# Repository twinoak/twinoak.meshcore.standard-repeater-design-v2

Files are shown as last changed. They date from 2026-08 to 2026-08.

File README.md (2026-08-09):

# TwinOak Standard Repeater Design v2

## General design concept and project goals
The thought behind this project came to life after quite a few failures in OTA firmware updates. There was need for a better, and more stable, way of doing the firmware updates. 
Besides the devices being bricked from the OTA process, repeaters can also sit quite a long distance away, so it would also be desireable to have something that could update remotely, from the comfort of a desk. 
One could consider using LoRa for sending the updates to the repeaters, but since the network is already congested enough, it seems like a bad idea to pile even more load on that band, even assuming that it somehow would be possible to get a stable link to all the repeater sites.

It was decided to go for a design which incorporated an LTE-M module for managinge the node. This gives almost 100% coverage(in Denmark at least!) and high bandwidth for firmware transfers. 
The structure looked something like this:
```mermaid
flowchart LR
    subgraph Mesh plane
    A@{ shape: cloud, label: "Mesh network" } <--> B[LoRa module]
    end
    B[LoRa module] <-.-> C[LTE-M module]
    subgraph Management plane
    C <--> D@{ shape: cloud, label: "Internet" }
    end
```

Besides the problematic management of remote nodes, there is also a few other features to address with this new repeater design. This meant that the primary goals for the project ended up being:
1. <b>Remote management</b>. Being able to do management remotely based on existing LTE infrastructure. Only management, no data via LTE.
2. <b>Superior noise "rejection"</b> with radio in RF shielding and using proper cables and isolation to give the LoRa the best possible noise floor. Previous experience with SenseCAP Solar P1 nodes, even though they are very nice nodes, proved that they are just plastic enclosures with no RF protection. Put them next to a cell tower and you are in trouble! A bit ironic that the biggest nemesis regarding noise in MeshCore repeaters is LTE, when this going to use LTE as the transport for the management plane!
3. <b>Integrated cavity filter</b>. There has been multiple issues with noise in all many locations. There is always a cell tower(or some DAB/DVT/whatever tower) sitting just next to great locations. The Solar P1 only offers the option to add a small SAW filter, but one goal of this project is that it should to be easy to add a good cavity filter. Even maybe be the default.
4. <b>Modularity</b>. Things change fast; firmware, features and other software changes fast! But hardware also changes. With the Solar P1 one would have to replace the entire unit if a new and better radio became available. This project should solve this by enabling changing JUST the radio or JUST the solarpanel or JUST the batteries. Not doing a complete "forklift upgrade" everytime is a must.

## Hardware design principle
The hardware is split into 3 parts:
1. The LoRa part
2. The power part
3. The management part

To make these function together in a modular way each part has been split into multiple "levels" with increasing amount of specialization the higher the level. This has been illustrated here:
```mermaid
block
  columns 7
  block:stuff:2
    columns 1
    A1["LoRa modul"] 
    space
    A2["LoRa adapter board"] 
    space
    A3["Platform board"]
    space
    space
  end
  space
  block:stuff2:2
    columns 1
    space
    space
    space
    space
    B3["Platform mgmt"]
    space
    B4["Power"]
  end
  space
  block:stuff3:2
    columns 1
    C1["LTE modul"] 
    space
    C2["LTE adapter board"]
    space
    C3["Platform board"]
    space
    space
  end

  %% Arrows vertically
  A1 <--> A2
  A2 <--> A3

  B4 --> B3

  C1 <--> C2
  C2 <--> C3

  %% Arrows horisontally
  A3 <--> B3
  B3 <--> C3
```
From the bottom up:
- <b>Power</b> is just that: Simple DC power source from either solarpanel, grid connection or battery.
- <b>Platform</b> and <b>Platform management</b> is introducing management of the power from the power source and handling signaling between the two platform boards. Each platformboard is just supplying simple power to the upper levels and generic IO between the levels.
- <b>Adapters</b> change the generic IO and power from the platform to the specific needs of the module above it. That could be board specific power management, levelshifting of IO signals and routing to the proper pins for the given module above.
- <b>Radio modules</b> is the actual off-the-shelf radio modules, such as a Heltec LoRa module like the T096 or similar.

Each of the 3 parts should be kept as RF isolated as possible as the two radio modules will likely interfer with each other. So the parts also indicate an "physical seperation" with RF shielding. To make this as good as possible the entire repeater should be house inside a RF shielded enclosure and both the LoRa part and the management part should be kept in seperate RF shielded enclosures. Great care should be taken at the interfaces between each part, such that RF noise don't traverse the bounderies between each part.

### Pinouts and inter-board wiring

Every pin of the D-subs, the A↔B ribbon, the platform boards and all adapter mappings is documented in
[`hardware/pcb/INTERCONNECT.md`](hardware/pcb/INTERCONNECT.md) — including the I2C bus plan (LoRa is master,
INA3221 @0x42, RV-3028 @0x52), the LoRa↔Walter UART link, the remote power-kill behaviour and JLCPCB part
references. Update that file first whenever the wiring changes.

## Bill-of-materials and links to sources

| Component | Brand | Model | Source | Price |
|---|---|---|---|---:|
| <u>*External components*</u> |
| Antenna, LoRa | Vinnant | CC868/8-PEL 10dBi | [Hoeg teknik](https://hoegteknik.dk/shop/da/dv-nodermeshtastic/483-8dbd-58-antenne-for-868-mhz.html) | 599 DKK |
| Antenna, LTE-M | SR passives| IP67, N-Male, 5dBi | [TME](https://www.tme.eu/dk/en/details/5g-ant-rs02w-n/gsm-antennas/sr-passives/) | 73 DKK |
| Cable | Bevotop | LMR240, N Male to N Male, 80cm | [Aliexpress](https://www.aliexpress.com/item/1005002640557645.html) | ~70 DKK |
| Pipe | | 1" pipe, 200cm | [Webshop](https://shop.erik-larsen.dk/products/pipe-galv?variant=39625182412883) | 150 DKK |
| Brackets | | Pipeclamps, set of 2, max 60mm | [Amazon](https://www.amazon.de/-/da/Premium-mastklemme-dobbeltklemme-galvaniseret-dobbelt/dp/B010UL5B66) | ~67 DKK |
| Enclosure | | Diecast alu box, IP67 | [Aliexpress](https://www.aliexpress.com/item/1005007492347455.html) |  ~185 DKK |
| Solar panel | Cellevia | 10W Solar Panel | [TME](https://www.tme.eu/dk/en/details/cl-sm10p/photovoltaic-modules/cellevia-power/) | 76 DKK |
| Vent valve | | M16 watertight alu vent valve | [Aliexpress](https://www.aliexpress.com/item/1005012242062756.html) | ~20 DKK |
| Bracket | | For solar panel | TBD | |
| Bracket | | For enclosure | TBD | |
| <u>*Internal components*</u> |
| Backplates | Custom | Set of 2pce, 1,5mm lasercut alu | (Fusion link? DXF?) | 280 DKK |
| RF boxes | Gainta | G103-IP67, 64x98x34mm, alu, 2pce  | [TME](https://www.tme.eu/dk/en/details/g103-ip67/multipurpose-enclosures/gainta/) | 108 DKK |
| Cavity filter | Sysmocom | 7Mhz Cavity filter(Link to test?) | [Sysmocom](https://shop.sysmocom.de/868-863..870-MHz-cavity-filter-ISM-LoRa-SigFox-Helium/cf866.5-kt30)  |  ~400 DKK |
| Battery | Meshnology | 10.000mA LiPo battery | [Meshnology](https://meshnology.com/collections/frontpage/products/3-7v-10000mah-lipo-battery-with-usb-charger-protection-for-arduino-esp32-drone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) | ~150 DKK |
| Cable | | U.FL -> SMA pigtail, 10cm | [Aliexpress](https://www.aliexpress.com/item/1005009937311685.html) | ~10 DKK |
| Cable | | N-female -> SMA pigtail, 10cm | [Aliexpress](https://www.aliexpress.com/item/1005008984322302.html) | ~10 DKK |
| Cable | | N-female -> SMA pigtail, 20cm | [Aliexpress](https://www.aliexpress.com/item/1005008984322302.html) | ~10 DKK |
| Cable | | SMA -> SMA pigtail, 10cm | [Aliexpress](https://www.aliexpress.com/item/1005006890065800.html) | ~10 DKK |
| <u>*Radio modules*</u> |
| LoRa module | Heltec | Heltec V3, ESP32 based | [Heltec](https://heltec.org/project/wifi-lora-32-v3/) |  ~120 DKK |
| *...or...* |
| LoRa module | Heltec | Heltec T096, nRF52 based | [Heltec](https://heltec.org/project/t096/) |  ~230 DKK |
| LTE module | Quickspot  | Walter LTE MCU, ESP32 based | [TinyTronics](https://www.tinytronics.nl/nl/development-boards/microcontroller-boards/met-telecommunicatie/walter-esp32-s3-iot-development-board-cat-m-nb-iot-en-gnss-gm02sp) | ~510 DKK |
| <u>*Custom PCBs*</u> |
| Platform board | | TBD | | |
| Heltec V3 adapter | | TBD | | |
| *...or...* |
| Heltec T096 adapter  | | TBD | | |
| LoRa connector board | | TBD | | |
| LTE connector board  | | TBD | | |
| <u>*Electrical components*</u> |
| D-sub connector | Amphenol | FCE17-E09SM-250, 9-pin, filter, x2| [Mouser](https://eu.mouser.com/en/ProductDetail/Amphenol-Commercial-Products/FCE17-E09SM-250) |  ~175 DKK |
| D-sub connector | Amphenol | L717DFE09PT, 9-pin, male PCB, x2  | [Mouser](https://eu.mouser.com/en/ProductDetail/Amphenol-Commercial-Products/L717DFE09PT) |  ~100 DKK |
| Capacitor | Panasonic  | 16SEPG470M, 470µF PolyAlu, x1 | [TME](https://www.tme.eu/dk/en/details/16sepg470m/tht-polymer-capacitors/panasonic/) | ~10 DKK |
| Capacitor | AISHI | EWH1CM101E11OT, 100µF, x2 | [TME](https://www.tme.eu/dk/en/details/ce-100_16pht-y/tht-electrolytic-capacitors/aishi/ewh1cm101e11ot/) | ~1 DKK |
| Capacitor | SR passives| CCT-10N/100V-S, 10nF Ceramic, x2  | [TME](https://www.tme.eu/dk/en/details/cct-10n_100v-s/mlcc-tht-capacitors/sr-passives/ct40805b103k101f1r/) |  ~1 DKK | | |
| Connector | | Pin headers for radio modules? | TBD | |
| Connector | | Low profile headers for adapters? | TBD | |

Total: ~3.250DKK + TBD + solder/heatshrink/screws/wires/etc + shipping/customs/fees/etc

## LTE-M providers

### Lebara
Lebara SIM card, their cheapest plan, has been tested and it worked fine with the Walter MCU and could get contact with the internet without issues.

### NexCon
The LTE provider nexcon.io has been tested. They have a 25MB/month plan that is VERY cheap, like 1eur/month per SIM card including a management website that is VERY nice! Can highly recommend them, however they might only serve commercial customers, so check that first.

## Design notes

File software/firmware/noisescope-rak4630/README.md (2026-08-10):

# NoiseScope — SX1262 spectrum/noise scanner for the RAK4630 adapter

Diagnostic firmware for the TwinOak standard-repeater LoRa module. When a site
has noise problems, flash this **in place of MeshCore**, let it stream spectrum
sweeps, RSSI histograms and burst statistics over the Walter management UART,
then flash MeshCore back. The measurement happens through the repeater's real
RX chain — antenna, coax, cavity filter, matching network, the SX1262 itself —
so unlike an external tinySA measurement it shows exactly what the radio sees.

Never transmits. RX only.

## What it measures

* **Monitor (default on boot):** continuous ~1 kHz instantaneous-RSSI sampling
  of the home channel (869.618 MHz, 62.5 kHz, SF8 by default) through the LoRa
  channel filter. Reports avg/max/min and a burst duty-cycle number every 10 s —
  this is MeshCore's "noise floor" number, but with the transients that
  MeshCore's averaging deliberately filters out.
* **Sweep:** stepped-RSSI spectrum scan (default 863–870 MHz in 25 kHz steps),
  avg + max-hold per point. The SX1262 tunes 150–960 MHz, so you can also point
  it at a suspected blocker (GSM/LTE downlink) — through the cavity filter,
  which is the honest view of what reaches the radio.
* **Hist:** Semtech's spectral-scan engine (official RAM patch, the same
  mechanism SX1261-equipped LoRaWAN gateways use). Per frequency: a histogram
  of 2048 RSSI samples taken 8.2 µs apart, 33 bins × 4 dB from −11 down to
  −139 dBm. Shows floor, burst level and duty cycle in one line — the tool for
  "idles at −115 but jumps to −100" mysteries.
* **Dwell:** park on one frequency and stream windowed statistics — burst
  periodicity and duty cycle over time.
* **CAD:** LoRa preamble-detection ratio, to tell "another LoRa network" apart
  from broadband/other interference.

See `PROTOCOL.md` for the exact NDJSON formats and the command set;
`tools/waterfall_plot.py` renders live or logged output as a waterfall.

## Relationship to MeshCore

Built on the **same pinned Adafruit nRF52 core fork and the same pinned
RadioLib commit** as MeshCore, with the same radio bring-up (DIO2 RF switch,
DIO3 TCXO 1.8 V, 140 mA current limit, RX boosted gain on), so RSSI readings
are comparable with what the repeater experiences in service.
`variants/rak4631/` and `boards/rak4631.json` are vendored from MeshCore
(Arduino LLC / Adafruit LGPL headers preserved).

MeshCore's on-flash config (identity keys, prefs in InternalFS) is **not
touched**: this firmware never writes flash, so a scanner→MeshCore round trip
preserves the repeater's identity. When flashing over SWD, use **sector/range
erase of the application area only — never chip erase** — or the bootloader,
SoftDevice and MeshCore's config filesystem go with it.

## Building

```
pio run
```

Artifacts in `.pio/build/rak4630/`:

* `firmware.hex` — for SWD flashing (Walter, J-Link, probe of choice)
* `firmware.zip` — DFU package for `adafruit-nrfutil dfu serial`
* `firmware.elf` — debugging

Offline/registry-blocked networks: every PlatformIO package can be substituted
with a local `symlink://` package (apt `gcc-arm-none-eabi` as
`toolchain-gccarmnoneeabi`, pip `scons`, apt `srecord` as `tool-sreccat`,
sparse-cloned CMSIS 5.7). The pinned framework and RadioLib come straight from
GitHub.

## Flashing workflows

**Remote (Walter, SWD):** flash `firmware.hex` over the SWD lines (D-sub pins
3/4/5), application range only. Same procedure back to MeshCore. The nRF52
watchdog (8 s) plus the bootloader living in protected flash means a bad day
ends in a reboot loop you can still flash out of — not a brick.

**Field (USB-C on the adapter):** double-tap reset or send `dfu` over any
serial console → UF2 bootloader (drag-and-drop) — or
`adafruit-nrfutil dfu serial -pkg firmware.zip -p COMx -b 115200`.

**Back to MeshCore remotely:** `dfu serial` reboots into the bootloader's
serial-only DFU if you flash over USB-CDC-less transports; over SWD just flash
the MeshCore hex.

## Using it

Connect at 115200 (Walter UART or USB). It boots into monitor mode and starts
reporting on its own — with `auto 10` (default) it also runs a full-band sweep
every 10 minutes. Typical session:

```
time 1754820000        # sync the clock (writes the RV-3028)
info
sweep                  # one full-band pass, ~7 s
hist 869.4 869.8 25    # histogram zoom on the 500 mW ERP subband
dwell 869.618 300      # 5 minutes of burst statistics on-channel
cad                    # is it LoRa?
```

Live waterfall on a laptop:

```
pip install -r tools/requirements.txt
python tools/waterfall_plot.py --port COM7 --metric max
```

Log on the Walter side and plot later:

```
python tools/waterfall_plot.py --file site.ndjson --save site.png
```

## Design notes / safety

* **Watchdog:** 8 s hardware WDT, fed from the main loop. Any hang → reset →
  boots into passive monitor mode.
* **Serial always live:** scans are chunked; command input is drained during
  blocking steps and executed between them. `stop` always works.
* **Spectral-scan patch:** ~2 kB Semtech blob (from `Lora-net/sx1302_hal`,
  shipped with RadioLib), uploaded into SX1262 RAM over SPI at the start of
  each `hist` session, purged by hardware reset at the end. Volatile by design:
  a PWR_KILL cycle, NRST pulse or reboot always returns the radio to stock.
* **Power telemetry:** reports the B-board INA3221 (panel/battery/load) in
  every heartbeat, so a scanning session doubles as a power-budget check.
  Missing peripherals (bench setup) are detected and skipped.
* **RX boosted gain** matches MeshCore's default (`boost off` to compare).
* The nRF52840's own radio is untouched (no BLE, no SoftDevice enabled).

## Interpreting results (quick reference)

* tinySA-style absolute accuracy is not the goal (±few dB); *deltas* are the
  signal: antenna vs. dummy load, filter in vs. out, quiet hour vs. busy hour.
* `stat.rssi.dc` ≫ 0 with calm `avg` = pulsed interferer (the case a single
  noise-floor number hides). Chase it with `dwell` (periodicity) then `hist`
  (level + true duty cycle), then `sweep --max` to find its frequency.
* High `cad.det` on a clean-looking channel = other LoRa traffic.
* A raised floor across the whole sweep that disappears on a dummy load =
  in-band interference or front-end compression from a strong out-of-band
  carrier; step the sweep across likely blockers (LTE800 DL 791–821,
  GSM-R/GSM900 DL 921–960) and remember you are looking through the cavity
  filter — that attenuation is part of the honest answer.

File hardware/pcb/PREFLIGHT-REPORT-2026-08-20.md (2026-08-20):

# TwinOak Standard Repeater v2 — JLCPCB Pre-Order Preflight (round 3)

**Date:** 2026-08-20 · **Scope:** Connector board A only (post-BME280/J_ENV re-route)
**Reference:** `hardware/pcb/INTERCONNECT.md` as the authoritative spec. Supersedes `PREFLIGHT-REPORT-2026-08-14.md` **for Conn A only** — findings for the other four boards in the 08-14 report remain in force.

---

## Verdict

**Order-ready after one two-field flag fix and a re-export.** The re-route is electrically perfect: the BME280 island is correct pin-for-pin (SDO strapped to GND → I²C **0x76**, exactly what stock MeshCore auto-detects), schematic and PCB agree **pad-for-pad across all 21 nets with zero open nets**, the long-standing **F1 clearance blocker at U4 is fixed** (board minimum is now exactly your 0.2 mm rule), and the GND zone fills are fresh — they respect every piece of new copper. One regression slipped in via the schematic sync, and the exports on disk predate everything.

| # | Finding | Severity |
|---|---|---|
| A1 | **J3 (J_ENV) lost `exclude_from_bom` / `exclude_from_pos_files`** — its schematic symbol says `in_bom yes` / `in_pos_files yes` (unlike JP1/J1/J2's `no`/`no`), so the F8 sync stripped the PCB excludes. With no LCSC number, Fabrication Toolkit will emit an unmatched JLC BOM line. | **Fix before export — 2 checkboxes** |
| A2 | **U5 (BME280) pin-1 orientation must be eyeballed in the JLC preview** — new part (C92489), LGA-8, no `FT Rotation Offset` field; FT relies on its rotation DB, and LGA sensors are frequent offenders. A wrong rotation puts VDD across GND. | **Resolve in JLC preview** |
| A3 | **`outputs/` gerbers are from July 20, `production/` is empty** — pre-F1-fix, pre-BME280, pre-re-route. Nothing currently on disk is uploadable. | Re-export |
| A4 | **Stock watch: L2 (C4354938 LPS4018) was 12 pcs at JLC on 08-14** — still listed and orderable today, but I could not read a live warehouse count this round. LCSC and Mouser (47 k+) are deep; BME280 C92489 sits at ~7 k at LCSC, SMT-assemblable (Standard). | Verify count at order time |

---

## Findings in detail

### A1 — J3 exclude flags stripped by the schematic sync (regression, trivial fix)
The PCB attr audit shows every hand-fit connector carrying both excludes **except J3**:

| Ref | PCB attrs | Sch `in_bom` / `in_pos_files` |
|---|---|---|
| J1 (D-sub) | through_hole + both excludes | no / no |
| J2 (ribbon) | through_hole + both excludes | no / no |
| JP1 | through_hole + both excludes | no / no |
| **J3 (J_ENV)** | **through_hole only** | **yes / yes** |

Root cause: J3's schematic symbol was created with `in_bom yes` / `in_pos_files yes`, and KiCad's Update-PCB-from-Schematic copies those flags onto the footprint — overwriting the excludes. **Fix it in the schematic** (J3 symbol properties → untick "In BOM" and "In position files"), then F8; fixing only the PCB attrs would regress on the next sync. After the fix, J3 exports exactly like JP1: bare pads, hand-solder the header when you want the ENV breakout.

### A2 — U5 rotation: check the pink pin-1 dot deliberately
U5 sits at (130.06, 77.54) rot −90 on F.Cu. The KiCad footprint is `Bosch_LGA-8_…_ClockwisePinNumbering` with the pin-1 tick at the chamfered corner; JLC's feeder orientation for C92489 is whatever their DB says, and there is no `FT Rotation Offset` field to pin it. In the JLC assembly preview, confirm their pin-1 marker lands on your extended silk tick / fab chamfer corner. While in the same session, re-eyeball U4 (TPS63001 DRC0010J — also no offset field) and confirm D4 is correctly absent (DNP).

### A3 — Stale exports
All 12 gerbers in `connector-board-a/outputs/` are dated **2026-07-20 13:45** — they predate the F1 clearance fix, the SH grounding, the BME280/J_ENV addition, and the re-route. `production/` is empty. After A1: refill zones, run ERC + DRC, export a fresh Fabrication Toolkit package, and consider deleting the July zip so it can't be uploaded by accident.

### A4 — Stock
* **C4354938** (L2, LPS4018-222MRC): the JLC part page is live with SMT assembly offered (Economic + Standard), but no count was readable in this pass — it showed **12 pcs on 08-14**. Confirm the count in the assembly BOM step; fallback: JLC Global Sourcing (LCSC has stock, Mouser holds ~47 k) or the C370436 sub from the 08-14 report.
* **C92489** (U5, BME280, genuine Bosch): ~**6,991 pcs** at LCSC, SMT-assemblable at JLC as a Standard part. One per board — fine, but it's the only humidity-capable part in the design, so don't sit on it.
* All other Conn-A parts (C14663, C15849, C15850, C45783, C149504, C17710, C17414, C28060, C8545) are JLC basics/high-runners; nothing else changed since 08-14.

---

## Medium / low — worth a thought while the files are open

1. **Conformal coating will blind the BME280.** If these boards get sprayed for outdoor duty, mask U5 — the metal-lid vent hole must stay open, and the enclosure needs some air exchange for RH/pressure readings to mean anything. (Sensor self-heating is a non-issue: MeshCore polls in forced mode.)
2. **Bench-test caveat carried over from 08-14:** the I²C pull-ups for this bus live on the RAK adapter (1 k pair). A-board + BME280 alone on the bench has no pull-ups → a bare-board I²C scan will fail. In-system is fine. (RAK-board scope; unchanged.)
3. **I²C stubs to U5** run 0.254 mm, mostly B.Cu, one via per line — electrically fine at 100 kHz. Nothing to do; noted for completeness.

---

## Verified clean — what I checked and found correct

**BME280 island, pin-for-pin (schematic *and* copper):** SDO (pad 5) → GND → address **0x76** ✓ · CSB (pad 2) → 3V3_LORA → I²C mode latched ✓ · VDD (8) + VDDIO (6) → 3V3_LORA ✓ · GND (1, 7) → GND ✓ · SDI (3) → I2C_SDA, SCK (4) → I2C_SCL ✓ · C22/C23 100 nF (C14663) across 3V3_LORA/GND at **2.8 mm and 3.3 mm** from U5 — proper decoupling distance ✓ · J_ENV pinout 1=3V3_LORA, 2=GND, 3=SDA, 4=SCL, pin-1 rect pad, 1.0 mm drills ✓ · stock `RAK_4631_repeater` ENV manager auto-detects BME280@0x76 — no firmware config needed ✓.

**Schematic ↔ PCB sync:** geometric netlist rebuilt from the schematic (all 106 pins attach; zero floating, zero NC conflicts) and compared pad-for-pad against the copper netlist — **100 % agreement, 21/21 nets, 86 connected pads**.

**Routing completeness:** every net is a single connected copper island (pads + 200 tracks + 49 vias + zone fills) — **zero open nets**, including all new BME280/J_ENV copper.

**Clearance sweep (F.Cu + B.Cu, tracks/pads/vias/zone fills, different nets):** **nothing below 0.2 mm anywhere** — the minimum is exactly 0.2000 mm (your rule), comfortably above JLC's 0.127 mm. **The 08-14 F1 blocker (0.111 mm VBAT_RAW at U4) is confirmed fixed.** The GND fills respecting every new track at ≥ 0.2 mm also proves the fills in the file are post-re-route.

**Board level:** outline closed (27.4 × 39.1 mm rect) ✓ · all new parts and courtyards fully inside; no courtyard overlaps anywhere (U5↔C22 gap 0.53 mm, U5↔C23 0.47 mm, U5↔J3 0.56 mm — tight but legal) ✓ · J3 pin-1 hole edge 1.79 mm from the board edge ✓ · min copper-to-edge 0.508 mm ✓ · vias uniform 0.6/0.3 ✓ · min THT drill 0.8 ✓ · track widths only 0.254 / 0.508 ✓ · all SMD front-side, single-side assembly preserved ✓.

**BOM:** 12 unique LCSC numbers across 21 machine-placed parts, every one populated — U5 carries **C92489**, C22/C23 reuse **C14663** ✓ · hand-fit J1/J2/JP1 and DNP'd D4 correctly excluded in both schematic and PCB (J3 is the lone exception → A1) ✓.

**Resolved from 08-14:** the open shield question is closed — **J1's SH pad is now tied to GND** in both schematic and copper ✓.

---

## Pre-order procedure (Conn A)

1. Schematic: J3 → untick In-BOM + In-position-files → save.
2. F8 (Update PCB from Schematic) → confirm only J3's attrs change.
3. Refill zones → ERC + DRC (expect zero; silk-over-pad on the new tight cluster gets its official check here).
4. Fabrication Toolkit export → verify the BOM has 12 LCSC lines and **no** J3 line, POS has no J3 row.
5. JLC preview: U5 pin-1 dot vs silk tick (A2), U4, D4 absent.
6. Assembly BOM step: read the live counts for **C4354938** and **C92489** before paying.

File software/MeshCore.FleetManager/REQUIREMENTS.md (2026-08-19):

# FleetManager — Requirements

Priority tags: **[M]** must-have (core value), **[S]** should-have, **[C]** could-have / later.
Unlike NightCrawler, FleetManager is a long-lived system, so "must" here means
"must exist for the first genuinely useful version," which is defined as the
**inventory + config-backup vault** (see [ROADMAP](ROADMAP.md) phase 1). Remote
control is deliberately *not* in that first must-have set — it's gated behind the
security model.

---

## 1. Inventory & identity

- **[M] FR-1** Maintain a record for **every node in the fleet**, of any tier
  (LTE-managed, mesh-only, third-party), keyed on the MeshCore public key with a
  human-friendly label/name.
- **[M] FR-2** Record each node's **capability set** (what management actions are
  possible) rather than a rigid type, and derive the archetype (LTE-managed /
  mesh-only / third-party) from it.
- **[M] FR-3** Record **site/location** context: where it physically is (address /
  coordinates / "the chimney in Grenaa"), mount type, antenna, and site notes —
  reusing the RF-site knowledge the project already tracks.
- **[M] FR-4** Record **role** (repeater / room server / companion / sensor /
  observer) and **hardware** (board, radio module, enclosure, filter, panel,
  battery) — the modular BOM per node.
- **[S] FR-5** Track **third-party / foreign nodes** with why they're in
  inventory (e.g. "essential hop to reach Vejle"), owner contact if known, and
  explicitly **no secrets** held for them.
- **[S] FR-6** Group nodes into **logical fleets/regions** (e.g. Djursland,
  Vejle) and tag them freely.
- **[S] FR-7** Track **lifecycle state**: planned → provisioned → deployed →
  degraded → retired → lost, with dates and notes.
- **[C] FR-8** Track **relationships/dependencies** between nodes (this node's
  only viable path to the internet-map is via that third-party hop).

## 2. Configuration backup vault

- **[M] FR-9** Store a **restorable configuration backup** per owned node: all
  MeshCore settings needed to reconstruct the node — identity keys (**private
  key**), **admin/guest passwords**, name, owner info, radio params (freq/bw/sf/
  cr/tx), region/scope config, advert intervals, repeat settings, and any custom
  vars.
- **[M] FR-10** Store secrets (private keys, passwords) **encrypted at rest**,
  with access controlled and audited. This is a hard requirement — see
  [SECURITY.md](SECURITY.md).
- **[M] FR-11** Support **versioned** config backups: keep history so you can see
  what a node's config was at any past point and roll back to it.
- **[S] FR-12** **Capture** a backup automatically where possible — from a
  provisioning step, from a NightCrawler crawl (non-secret fields), or from a
  direct query over the LTE plane for LTE nodes.
- **[S] FR-13** **Restore / re-provision**: generate the exact CLI command
  sequence (or push it directly, for LTE nodes) to rebuild a replacement node
  with a lost node's identity and config.
- **[S] FR-14** Detect **config drift**: compare the stored intended config
  against what NightCrawler observed or what a live query returns, and flag
  differences.
- **[C] FR-15** **Key rotation** workflow: change an admin password or rotate an
  identity across the fleet and track which nodes are updated.

## 3. Firmware management (LTE tier)

- **[S] FR-16** Maintain a **firmware image library** (versions, target boards,
  build provenance, checksums, release notes) for MeshCore and for the
  [NoiseScope](../firmware/noisescope-rak4630/) diagnostic firmware.
- **[S] FR-17** Track **which firmware each node runs** (from telemetry / crawl /
  query) and flag nodes behind the current target — an "update campaign" view.
- **[C] FR-18** **Orchestrate remote OTA** over the LTE plane, honouring the
  on-node A/B + health-gated auto-rollback design: stage image → trigger →
  monitor health → confirm or auto-rollback. FleetManager tracks campaign state
  across the fleet; the node firmware guarantees un-brickability.
- **[C] FR-19** **Swap firmware** on an LTE node between MeshCore and NoiseScope
  for a diagnostic session and back, as the noisescope workflow describes
  (flash-in-place, scan, flash-back), preserving the node's config filesystem
  (application-area erase only — **never** chip erase).
- **[C] FR-20** Track **OTA history** and outcomes per node (success, rollback,
  failure) for reliability trending.

## 4. Remote state & control (LTE tier)

- **[S] FR-21** **Force reboot / power-cycle** an LTE node remotely (the Walter
  can power-kill the LoRa radio's 3V3 rail), with the action authorised and
  audited ([SECURITY](SECURITY.md)).
- **[S] FR-22** Read **live node state** on demand over LTE (up/down, current
  firmware, radio config, uptime, last reboot reason).
- **[C] FR-23** **Remote console passthrough** to a node's MeshCore CLI over the
  LTE UART tunnel — the "management from a desk" endgame.
- **[C] FR-24** **Scheduled / conditional actions** (e.g. auto power-cycle a node
  that's been unresponsive for N hours, matching the on-node watchdog with a
  fleet-level safety net).

## 5. Telemetry & environment archive

- **[M] FR-25** Store **time-series telemetry** per node: battery voltage/current
  and charge, panel voltage/current (INA3221 channels), and enclosure environment
  (BME280 temp/humidity/pressure) — the same channels the repeater hardware and
  NoiseScope heartbeats already expose.
- **[S] FR-26** **Automatically pull** power and environment stats from LTE nodes
  on a schedule (the "automatic pulling of statistics" requirement) and ingest
  the same fields from NoiseScope heartbeats and MeshCore telemetry frames.
- **[S] FR-27** **Trend and alert**: charts over time, and alerts on thresholds
  (battery low, not charging through a sunny day, temperature/condensation risk,
  node silent).
- **[S] FR-28** Correlate telemetry with the **darkest-winter power-budget**
  concern — flag nodes whose battery trend won't survive the winter stretch.
- **[C] FR-29** **Manual telemetry entry** for mesh-only nodes visited in person
  (a reading taken with a multimeter or read off the mesh).

## 6. NoiseScope RF archive

- **[M] FR-30** Store **NoiseScope sweeps/measurements** per node/site with full
  context (timestamp, firmware, radio config, antenna/filter setup, the raw
  NDJSON), so a sweep is a first-class, permanently-kept artefact.
- **[M] FR-31** Support **historical comparison**: put a sweep from last year
  next to one taken now for the same site and show the delta (the explicitly
  requested "1 sweep last year vs a sweep now" use case).
- **[S] FR-32** **Trigger a NoiseScope session** on an LTE node (flash → scan →
  collect → flash back) and file the results automatically (ties FR-19 + FR-30).
- **[S] FR-33** Render sweeps as **waterfalls/spectra** (reusing the
  `waterfall_plot.py` logic) and histograms, and annotate known blockers
  (LTE800/GSM-R bands) as the noisescope docs describe.
- **[C] FR-34** **Fleet-wide RF health** view: which sites are noisy, trending
  worse, or newly quiet after a filter change.

## 7. Observation & drift (the NightCrawler tie-in)

- **[M] FR-35** **Ingest NightCrawler's mesh graph** and match observed nodes to
  inventory by public key.
- **[S] FR-36** Surface **unknown/rogue nodes** the crawler found that aren't in
  inventory — candidates to adopt (as owned or third-party) or investigate.
- **[S] FR-37** Surface **drift**: firmware behind target, region/scope config
  changed, owner info changed, neighbours lost/gained, node gone silent.
- **[S] FR-38** Store the **neighbour graph over time** so topology change is
  visible (an essential hop that vanished, a new link that appeared).

## 8. Access, audit, operability

- **[M] FR-39** All access to secrets and all control actions are **authenticated
  and audited** (who/what/when) — see [SECURITY](SECURITY.md).
- **[S] FR-40** A **web UI** (single-operator) presenting inventory, a per-node
  detail page, telemetry charts, the NoiseScope archive, and the drift dashboard.
- **[S] FR-41** An **API** so NightCrawler, the Walter nodes, and future tools can
  push/pull without the UI.
- **[C] FR-42** **Backup/export** of the whole FleetManager datastore itself
  (it's the crown jewels — it must itself be backed up, encrypted).
- **[C] FR-43** **Map view** of the fleet (sites, links, health) — possibly by
  feeding the existing MeshMapper/CoreScope tooling rather than reimplementing.

---

## 9. Non-functional requirements

- **[M] NFR-1 Security-first.** This system holds private keys and admin
  passwords and can reboot hardware. Confidentiality of secrets and
  authorisation of control actions dominate every design decision
  ([SECURITY](SECURITY.md)).
- **[M] NFR-2 Durability.** Inventory, backups and the RF archive are long-lived
  records that must survive disk failure — the datastore is itself backed up, and
  the RF/telemetry archive is expected to grow for years.
- **[M] NFR-3 Single-operator simplicity, multi-user-ready.** Runs for one person
  managing one fleet, on modest hardware (a home-lab box / small VPS / the same
  Raspberry Pi class the BBS runs on), but the model shouldn't preclude adding
  users/roles later.
- **[S] NFR-4 Offline-tolerant.** LTE nodes go dark; the mesh is intermittent.
  The system degrades to "last known state" gracefully and reconciles when
  connectivity returns.
- **[S] NFR-5 Technology fit.** Thomas's stack is .NET/C# (LabelHub, NoiseScope
  tooling, NightCrawler). A .NET server + a straightforward relational store is
  the natural fit; time-series data may warrant a purpose-built store later.
- **[S] NFR-6 Auditability for external stakeholders.** The project already has a
  NIS 2 / utility-company angle; an auditable record of node config, access and
  changes is a latent asset there — design so it *could* satisfy that scrutiny.
- **[C] NFR-7 Extensible node model.** New hardware, new capabilities, new
  telemetry channels arrive constantly (the whole repeater project is built on
  modularity) — the schema must absorb them without migrations-from-hell.

---

## 10. Explicit non-goals

- Not sending management traffic over LoRa (LTE/IP is the management plane).
- Not re-implementing the mesh map — integrate with existing mappers instead.
- Not a public/multi-tenant service in v1.
- Not doing the on-node firmware's job (A/B, watchdog, health-gating live on the
  node; FleetManager orchestrates and records, it doesn't replace them).

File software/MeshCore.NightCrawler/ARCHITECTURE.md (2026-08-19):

# NightCrawler — Architecture

The guiding constraint is [NFR-1: simplicity](REQUIREMENTS.md#2-non-functional-requirements).
This is a PoC console app. The architecture below is the *smallest* structure
that keeps the three genuinely tricky concerns — the frame protocol, the
throttle, and the traversal — cleanly separable and testable, and nothing more.

---

## 1. Layers

```
┌─────────────────────────────────────────────────────────────┐
│  CLI / host  (Program.cs)                                     │
│  parse args + config, build the object graph, run, report     │
└───────────────┬───────────────────────────────────────────────┘
                │
┌───────────────▼───────────────────────────────────────────────┐
│  Crawler  (the traversal)                                      │
│  frontier · visited-set · depth bound · per-node query plan    │
│  — pure logic, no sockets, no clock it doesn't own —           │
└───────┬───────────────────────────────────┬───────────────────┘
        │ asks for data                      │ every OTA request goes through
┌───────▼─────────────────┐        ┌─────────▼───────────────────┐
│  IMeshClient            │        │  IRateLimiter               │
│  high-level ops:        │        │  the single choke point     │
│  GetSelf, GetContacts,  │        │  (msgs/min token bucket)    │
│  Login, GetNeighbours,  │        └─────────────────────────────┘
│  GetOwnerInfo, GetVer,  │
│  GetRegions, GetStats   │
└───────┬─────────────────┘
        │ implemented by
┌───────▼─────────────────────────────────────────────────────┐
│  MeshCoreCompanionClient                                       │
│  companion frame protocol over a transport                    │
│  ├─ FrameCodec      (encode/decode <…>, >…len… payloads)      │
│  ├─ OpCodes         (the single place opcodes live)           │
│  ├─ read loop       (drains frames, routes PUSH_* asynchronously)│
│  └─ ITransport      (TcpTransport now; SerialTransport later) │
└───────┬───────────────────────────────────────────────────────┘
        │
┌───────▼───────────────┐        ┌─────────────────────────────┐
│  ITransport → TCP      │        │  IGraphStore                │
│  (TcpClient stream)    │        │  load/save the JSON graph   │
└────────────────────────┘        │  atomic incremental writes  │
                                   └─────────────────────────────┘
```

### Why these seams

- **Crawler ↔ IMeshClient.** The traversal is the part with the interesting
  bugs (loops, double-queries, depth off-by-ones). Putting a high-level
  `IMeshClient` interface between it and the wire means the whole traversal can
  be unit-tested against a fake client with a scripted mesh — no radio, no
  sockets, deterministic ([NFR-7](REQUIREMENTS.md#2-non-functional-requirements)).
- **IRateLimiter as a hard choke point.** [FR-24](REQUIREMENTS.md#16-throttling-first-class-not-an-afterthought)
  says it must be *structurally impossible* to skip the throttle. So the limiter
  is not a politeness call sprinkled around the code — every `IMeshClient` method
  that emits an over-the-air request `await`s a token from the limiter before it
  sends, inside the client implementation. The crawler can't forget to call it
  because the crawler never calls it directly.
- **OpCodes in one file.** Per [PROTOCOL.md](PROTOCOL.md) the numeric opcodes are
  not fully trustworthy across firmware versions. Isolating them means a firmware
  bump is a one-file edit.

## 2. Concurrency model

**Single logical worker.** At 1 message/minute there is nothing to parallelise —
the rate limiter is the bottleneck by a factor of thousands, not the CPU or the
socket. The crawl is a simple `async` loop: pull the next node from the frontier,
run its query plan (each step `await`s a rate token), fold the results into the
graph, enqueue new neighbours, persist, repeat.

The **only** concurrency is the client's background **read loop**, which must run
continuously to drain inbound frames and dispatch unsolicited `PUSH_*` frames
(adverts, path updates) regardless of what command is currently outstanding. This
is modelled as one long-running `async` read task feeding an internal channel;
command methods await the specific response frame they expect, pushes are routed
to handlers. (Per Thomas's stated preference, this is plain linear `async`/`await`
with a `Channel<T>`/`await foreach`, not hand-rolled `TaskCompletionSource`
plumbing or `Promise`-style constructs.)

## 3. Suggested project layout

A single solution, one runnable project, one test project:

```
MeshCore.NightCrawler/
├─ MeshCore.NightCrawler.sln
├─ src/
│  └─ MeshCore.NightCrawler/
│     ├─ Program.cs                 // arg/config parse, wire-up, run, summary
│     ├─ CrawlOptions.cs            // strongly-typed config (depth, rate, host…)
│     ├─ Crawl/
│     │  ├─ Crawler.cs              // the traversal (frontier, visited, depth)
│     │  ├─ Frontier.cs             // queue of (nodeId, depth) to visit
│     │  ├─ NodeQueryPlan.cs        // the per-node sequence of asks
│     │  └─ CrawlSummary.cs         // end-of-run stats
│     ├─ Mesh/
│     │  ├─ IMeshClient.cs          // high-level ops (the crawler's view)
│     │  ├─ MeshCoreCompanionClient.cs
│     │  ├─ FrameCodec.cs           // <…> / >…len… framing
│     │  ├─ OpCodes.cs              // CMD_/RESP_/PUSH_ constants (per firmware)
│     │  ├─ CompanionReadLoop.cs    // background frame drain + push routing
│     │  └─ Transports/
│     │     ├─ ITransport.cs
│     │     └─ TcpTransport.cs      // (SerialTransport.cs later — FR-4)
│     ├─ RateLimiting/
│     │  └─ TokenBucketRateLimiter.cs   // IRateLimiter, msgs/min
│     ├─ Model/
│     │  ├─ MeshNode.cs             // one node record (see DATA-MODEL.md)
│     │  ├─ Neighbour.cs
│     │  ├─ MeshGraph.cs            // the whole graph + run manifest
│     │  └─ RunManifest.cs
│     └─ Storage/
│        ├─ IGraphStore.cs
│        └─ JsonGraphStore.cs       // atomic incremental persistence
└─ tests/
   └─ MeshCore.NightCrawler.Tests/
      ├─ CrawlerTests.cs            // loops, depth, visited-set, budgets
      ├─ RateLimiterTests.cs
      ├─ FrameCodecTests.cs
      └─ FakeMeshClient.cs         // scripted mesh for traversal tests
```

If even this feels heavy for a first cut, it collapses cleanly to a handful of
files in one project; the folders are the *conceptual* seams, and the interfaces
(`IMeshClient`, `IRateLimiter`, `ITransport`, `IGraphStore`) are the ones worth
keeping no matter how small the implementation starts.

## 4. Dependencies

Keep it lean:

- **System.Text.Json** for persistence (in-box, source-generatable, fast). No
  Newtonsoft.
- A minimal arg parser — either hand-rolled or **System.CommandLine** if the flag
  surface justifies it. Config file binding via
  `Microsoft.Extensions.Configuration` is optional; a plain JSON `appsettings`
  read is fine for the PoC.
- **No** database, ORM, message bus, or web framework.
- Logging: `Microsoft.Extensions.Logging` with the console provider, or plain
  `Console` writes behind a tiny wrapper. Nothing heavier.

## 5. Configuration flow

`Program.cs` builds a `CrawlOptions` from, in ascending precedence: built-in
defaults → optional `appsettings.json` → environment variables → command-line
flags. The safe defaults (1 msg/min, depth 5) live in code so that *no*
configuration is required to run safely. See
[CONFIGURATION.md](CONFIGURATION.md).

## 6. Error & lifecycle handling

- **Per-node failures** (timeout, auth fail, malformed response) are caught,
  recorded on the node's record, and never abort the run
  ([NFR-5](REQUIREMENTS.md#2-non-functional-requirements)).
- **Transport drop** → the client raises a reconnect; the crawler pauses, the
  client re-establishes the TCP session and re-does the handshake, and the crawl
  resumes from the persisted frontier (FR-3). The visited-set and graph are
  already on disk, so at worst one node's partial query is retried.
- **Cancellation** — Ctrl-C / `SIGTERM` triggers a graceful stop: finish the
  current node (or abandon it), flush the graph and manifest, print the summary,
  exit non-zero to signal "incomplete." An overnight run stopped by the time
  budget (FR-22) does the same but exits zero.
- **Atomic writes** — the graph is written to a temp file and `File.Move`d over
  the target so a crash mid-write never corrupts the JSON
  ([FR-29](REQUIREMENTS.md#17-persistence)).

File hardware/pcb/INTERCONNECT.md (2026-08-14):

# TwinOak Standard Repeater v2 — Interconnect Reference

Single source of truth for every pin and net between the boards.
Updated 2026-08-14 (platform J1 ribbon remap; previously 2026-08-09 connection-audit + A/B power move).

## Topology

```
[LoRa module] ─ [LoRa adapter] ─ [platform board] ─ ribbon+IDC ─ (filtered D-sub bulkhead, LoRa box)
                                                                        │  ← connector board A (outside, D-sub male + 3V3 regulator)
                                                                   10-wire ribbon (A↔B)
                                                                        │  ← connector board B (outside, D-sub male + charger + telemetry)
[Walter]      ─ [LTE adapter]  ─ [platform board] ─ ribbon+IDC ─ (filtered D-sub bulkhead, LTE box)
```

* Both **platform boards are identical** (dumb 9-line pass-through; J1 order is permuted for flat ribbon fan-out — see the platform-board section). Only the adapters and connector boards give pins meaning.
* Bulkheads: Amphenol **FCE17-E09SM-250** filtered D-sub, **1000 pF** per line, **solder cup** — the internal harness fans the ribbon **flat across the solder cups in physical order**: conductor → D-sub pin **1, 6, 2, 7, 3, 8, 4, 9, 5** (conductor 10 unused). Red stripe (conductor 1) at the **pin-1/pin-6 end**; never split the ribbon into per-row bundles. This is the same map as a crimp-on IDC DE-9, so a crimped IDC socket on the ribbon gives the identical pinout for bench harnesses. *(Platform J1 was remapped 2026-08-14 to make this work — any pre-remap platform board needs the old 1:1-by-pin-number harness instead.)*
* Power architecture: solar → BQ24650 charger (B) → 1S LiPo. Raw battery feeds the Walter box (LTE D-sub pin 2) and, over the A↔B ribbon, the **TPS63001 3V3_LORA buck-boost on the A-board**. The Walter can kill 3V3_LORA remotely (LORA_PWR_KILL, default = ON when the kill line floats).

## D-sub pinouts (both are 9-pin, but NOT identical)

| Pin | LoRa box (A-side)  | LTE box (B-side) |
|----:|---|---|
| 1 | GND | GND |
| 2 | **3V3_LORA** (from A-board regulator) | **VLOAD+** (raw battery, INA ch3-measured) |
| 3 | LORA_nRESET | LORA_nRESET (Walter IO1) |
| 4 | LORA_SWDCLK ¹ | LORA_SWDCLK (Walter IO2) |
| 5 | LORA_SWDIO ¹ | LORA_SWDIO (Walter IO4) |
| 6 | I2C_SCL | **LORA_PWR_KILL** (Walter IO5) |
| 7 | I2C_SDA | — spare / NC |
| 8 | LORA_UART_RX | WALTER_TX (Walter IO7) |
| 9 | LORA_UART_TX | WALTER_RX (Walter IO8) |

¹ On the Heltec V3 adapter pin 4 is the **PRG/GPIO0 boot strap** and pin 5 is unused (ESP32 has no SWD).

Pins 3, 4, 5, 8, 9 are straight-through Walter↔LoRa links (via B-board). Pins 6, 7 differ per side; pin 2 carries a different rail per side.

## A↔B ribbon (10-wire, TE 8-215570-0 header both ends, 1:1)

| Wire | Net | Notes |
|-----:|---|---|
| 1 | GND | |
| 2 | VLOAD+ / VBAT_RAW | raw battery from B-board (`VLOAD+`, measured by INA ch3) → A-board regulator input (`VBAT_RAW`). Currently **unfused** — F2 was dropped; consider a PTC (C438898) in this feed if you want the ribbon protected. |
| 3 | LORA_nRESET | pass-through to both D-subs |
| 4 | LORA_SWDCLK | pass-through |
| 5 | LORA_SWDIO | pass-through |
| 6 | LORA_PWR_KILL  | LTE D-sub 6 → A-board kill circuit (Q3/EN) |
| 7 | I2C_SDA | LoRa D-sub 7 ↔ INA3221 on B-board |
| 8 | WALTER_TX / LORA_UART_RX | pass-through |
| 9 | WALTER_RX / LORA_UART_TX | pass-through |
| 10 | I2C_SCL | LoRa D-sub 6 ↔ INA3221 on B-board |

## Platform board (identical everywhere)

J1 conductor map (remapped 2026-08-14, board rev v1.1 — interleaved so the ribbon fans flat onto the D-sub cups):

| J1 pad / ribbon conductor | → D-sub pin | Rail / header row |
|--:|--:|---|
| 1 | 1 | GND (all row pins 1) |
| 2 | 6 | IO4 (rows B/D pin 2) |
| 3 | 2 | VBAT (rows A/C pin 2) |
| 4 | 7 | IO5 (B/D pin 3) |
| 5 | 3 | IO1 (A/C pin 3) |
| 6 | 8 | IO6 (B/D pin 4) |
| 7 | 4 | IO2 (A/C pin 4) |
| 8 | 9 | IO7 (B/D pin 5) |
| 9 | 5 | IO3 (A/C pin 5) |
| 10 | — | NC (unused conductor) |

By construction J1's **top header row (odd conductors) = D-sub top row, pins 1–5 in order**, and the **bottom row (even) = D-sub bottom row, pins 6–9 in order**. D-sub pin *meanings* are unchanged — only which ribbon conductor carries them.
Adapter interface = 4×5-pin rows; rows A‖C and B‖D are paralleled pin-for-pin (unchanged).
Note: platform J1 uses a 9-pin symbol on the 10-pad 82155700 footprint — pad 10 (unused IDC conductor) has no net. Cosmetic only.

## Adapter pin maps (platform IO → module pin)

| IO (D-sub) | Platform_LoRa name | RAK4630 adapter | Heltec V3 adapter | Platform_LTE name | Walter adapter |
|---|---|---|---|---|---|
| VBAT (2) | 3V3 | VBAT_NRF etc. (3.3 V in) | 3V3 header pins | VBAT | VIN (raw batt) |
| IO1 (3) | nRESET | P0.xx NRF_RESET (pin 17) + SW1 | RST | nRESET | Walter IO1 |
| IO2 (4) | SWDCLK | SWDCLK (pin 18) | **GPIO0 / PRG strap** | SWDCLK | Walter IO2 |
| IO3 (5) | SWDIO | SWDIO (pin 19) | — (NC) | SWDIO | Walter IO4 |
| IO4 (6) | SCL | P0.14 I2C_SCL + RV-3028 | GPIO34 (SCL) *LoRa side only — LTE side pin 6 = KILL* | PWR_KILL | Walter IO5 |
| IO5 (7) | SDA | P0.13 I2C_SDA + RV-3028 | GPIO33 (SDA) | SPARE | Walter IO6 |
| IO6 (8) | UART_RX | P0.15 Serial1 RX / P0.19 Serial2 RX (via J4) | GPIO44 U0RXD | UART_TX | Walter IO7 |
| IO7 (9) | UART_TX | P0.16 Serial1 TX / P0.20 Serial2 TX (via J5) | GPIO43 U0TXD | UART_RX | Walter IO8 |

RAK UART selection: 2.54 mm 3-pin headers **J4 (RX) / J5 (TX)** — jumper **1–2 = Serial1 (P0.15/P0.16, Arduino/MeshCore default)**, jumper 2–3 = Serial2 (P0.19/P0.20). The RAK adapter's SCL/SDA sit on the B-row platform pins (7/8) — electrically identical to the D-row (rows are paralleled on the platform board).

## I2C bus (LoRa is the single master)

* Members: RAK/V3 MCU (master), RV-3028-C7 RTC on the RAK adapter (**0x52**), INA3221 on B-board (**0x42**, A0 tied to SDA — deliberate).
* Pull-ups: **one set only — 1 k to +3V3 on the LoRa adapter** (RAK: R1/R2, V3 adapter: R2/R3). The B-board pull-ups were removed. With the rail killed the bus sits low and nothing backfeeds.
* Why 1 k: SDA/SCL cross the LoRa bulkhead filter (1000 pF/line ≈ 1.2 nF total with wiring). τ ≈ 1.3 µs → reaches V_IH in ~1.5 µs. Workable at 100 kHz (rise-time spec technically exceeded; drop the clock if flaky). 10 k would make the bus unusable (τ ≈ 12 µs).
* Sink current at 1 k ≈ 3.3 mA: within INA3221/RV-3028 limits; on nRF52 prefer high-drive (H0D1) pin config if VOL margin is tight.

## UART link (LoRa ↔ Walter)

Push-pull lines through two 1000 pF bulkhead filters (~2.2 nF) — fine at 115200. Recommended default 115200 8N1.
Heltec V3: the link lands on **UART0 (GPIO43/44)** so the Walter can run esptool-style flashing using nRESET + PRG (GPIO0). MeshCore RS232-bridge builds default to GPIO5/6 — override `WITH_RS232_BRIDGE_RX/TX` to 44/43 for this hardware (and mind the UART0 console).
RAK4630: SWD flashing via Walter (pins 3/4/5) stays the primary update path; UART is the data/management link (Serial1).

## Kill line behaviour

`LORA_PWR_KILL` (Walter IO5) → A-board R12 → Q3 gate (R13 100 k pull-down) → pulls TPS63001 EN low.
* Walter pin floating / Walter unpowered → **LoRa rail ON** (safe default).
* Drive HIGH to kill the LoRa 3V3 rail. RTC on the RAK adapter rides through on its backup caps.
* **Firmware rule: tristate nRESET/SWD/UART pins before asserting kill.** The A-board's 470 R series resistors (R1–R5) on pins 3/4/5/8/9 limit backfeed current into the unpowered radio to ~7 mA as a hardware backstop (swap to 0R if they ever bother SWD speed; bit-banged SWD is fine up to ~300 kHz).

## Walter USB / local flashing (added after USB analysis)

The Walter's USB-C VBUS and its VIN header pin are **directly tied** (datasheet: "DO NOT power Walter with both
the USB-C connection and the VIN-pin!"), and the S3's native USB (GPIO19/20) is not on the headers. The adapter
therefore now has:

* **U3 LM66100 ideal diode** (SC-70-6, LCSC C2869734) between the platform battery rail (`VCC`) and the Walter's
  VIN (`WALTER_VIN`), CE tied to GND, C3 100 nF on the input. Bulk C1 (470 µF) + C2 (10 nF) sit on the Walter side
  of the diode. Result: a PC on the onboard USB-C (5 V) simply wins the rail and **cannot back-charge the LiPo**
  through RS4 — hot-plug is safe with the system live. Drop ≈ 20–90 mV; INA ch3 still reads battery-sourced Walter
  current. (Boards built before this change: flip SW1 OFF before connecting USB — 5 V would otherwise force-charge
  the battery past the BQ24650's 4.2 V limit.)
* **J1 recovery header** (1×6, 2.54 mm): 1 = WALTER_VIN (5 V from a dongle is fine — the diode isolates the battery),
  2 = TX0 (GPIO43), 3 = RX0 (GPIO44), 4 = nRST, 5 = IO0 (boot strap, doubles as the module's 3V3_SW enable — unused
  here), 6 = GND. Any USB-UART dongle + esptool can flash the Walter if the native USB ever wedges.

## Board change log (this revision)

* **Bug fixed:** B-board had I2C SCL on ribbon wire 9 while the RAK adapter had SCL on D-sub 6 — SCL never reached the INA3221 and was instead shorted to Walter IO5 through the pin-6 pass-through. SDA happened to line up. New map above is consistent end-to-end (machine-verified netlist walk across all five boards).
* B-board: 3V3_LORA stage (TPS63001 + kill circuit) **moved to the A-board**; B-board pull-ups R9/R10 deleted; J1.7 now NC; every remaining part carries an `LCSC Part #` field. (F2 later removed in your rail rework — ribbon feed is unfused, see ribbon table.)
* A-board: was a dumb 1:1 adapter, now hosts the 3V3_LORA regulator, kill circuit and series protection resistors. Ribbon J2 is now the proper 10-pin 8-215570-0 symbol.
* RAK adapter: labels renamed to real signal names; Serial1/Serial2 selectable via J4/J5 pin-header jumpers; I2C pull-ups 10 k → 1 k.
* Walter adapter: symbol/labels renamed only — **no wire changes**. Firmware: KILL moves from IO8 → IO5; IO7 = TX to LoRa, IO8 = RX from LoRa; IO6 spare.
* Heltec V3 adapter: rebuilt for the real V3 (ESP32-S3) with a pinout-verified module symbol (was a V2 symbol with I2C/UART on input-only GPI36-38, and the module's 3V3 pins were not even connected). Physical 2×18 footprint reused (Heltec: V2→V3 pin layout unchanged) — verify mechanically against a real module before ordering.
* T096 adapter: still an unwired stub — TODO (nRF52840: same SWD+UART+I2C pattern as RAK; MeshCore T096 variant uses P0.07/P0.08 as Wire SDA/SCL, Serial1 on P0.23/P0.25).
* **2026-08-11 preflight fixes:** RV-3028-C7 **footprint pad numbering corrected** — the library footprint was mirrored (top row read 4-3-2-1); pads renumbered in `TwinOak.pretty` and in the U5 copy embedded in the RAK PCB, silk pin-1 dot moved to the true pin-1 corner. **U5 tracks must be rerouted** (nets stayed with their pad numbers, so four signal pads changed sides). B-board **STAT LEDs D2/D3 flipped** so the anode faces the VREF resistors — the 2026-08-09 note above claimed this fix but it was not in the files. B-board **input protection added**: new net `PANEL_IN` (J2.1) → D4 SS54 → `PANEL_RAW`; D5 SMBJ26A TVS from `PANEL_IN` to GND. MPPT setpoint left at 17.83 V — the panel now sits one diode drop above it (≈18.2 V ≈ Vmp), which lands the operating point even closer to the panel's maximum-power voltage. Part swaps for delisted JLC catalog entries: A-board R13–R15 100 k C17407 → **C149504** (Basic), B-board L1 C511353 → **C845066**. D4/D5 have no PCB placements yet — run *Update PCB from Schematic* on the B-board and place/route them at J2. *(Done 2026-08-13 — TH redrew the protection with direct wires; input net is unnamed but topology identical.)*
* **2026-08-13 JLC-import cleanup:** all hand-fitted parts are now excluded from BOM+position exports (Walter C1/C2/J1 + **U1/U2 set DNP**; RAK J4/J5; A-board JP1/J1/J2; B-board J1/J5), and the already-DNP parts (RAK U2, A D4, B C13/R11) carry explicit exclude attributes — Fabrication Toolkit exports now import to JLC without unmatched lines regardless of the Exclude-DNP option. RAK U3 and U5 carry an `FT Rotation Offset` field (+90° / 180°; field renamed 2026-08-14 — `FT Rotation Offset` is the name Fabrication Toolkit actually reads, `JLCPCB Rotation Offset` is not recognized) for the CPL; verify the pink-dot-on-white-dot alignment in the JLC preview each order (FT versions with issue #195 ignore the field — correct in the JLC editor if so). **U5/RV-3028 orientation re-verified against Micro Crystal's datasheet (top row 1-2-3-4, dot top-left): the board is correct — the JLC part model is what needs rotating.** SW1 (C55159901): valid+assemblable but zero JLC warehouse stock — use JLC Global Parts Sourcing (LCSC has stock) or hand-solder. Bottom-silk mirroring checked on A and B: identical flags, both correct.
* **2026-08-13 CORRECTION — RV-3028-C7 footprint restored to ORIGINAL numbering (pin 1 top-right).** The 2026-08-11 preflight claimed the footprint was mirrored; that claim was wrong — it came from text-layer extraction of the datasheet's Pin Connections figure, which lists the corner labels in misleading order. Visual read of the figure (top view: #1 bottom-left with index dot, numbering CCW) plus TH's Micro Crystal eval-board photos confirm the ORIGINAL footprint chirality was correct all along; JLCPCB's C3304278 model agrees. Pads renumbered back in the shared lib and in the U5 copy on the RAK PCB; U5's rotation offset stays **180°** (an earlier note here said "zeroed" — that was wrong; TH re-verified the 180° offset against the JLC pink-dot preview 2026-08-14). **U5 must be rerouted a second time** (the 2026-08-12 reroute matched the wrong numbering). After rerouting, verify in the JLC preview that their pink pin-1 dot sits on the silk dot at the chosen rotation.
* **2026-08-14 — platform J1 remapped for flat ribbon fan-out (board rev v1.1).** The old harness rule (conductor n → D-sub cup n) forced splitting the ribbon into a top-row and a bottom-row bundle at the solder cups, because the cups physically interleave (1,6,2,7,3,8,4,9,5 walking across the connector). J1's schematic wiring and PCB breakout were permuted so conductor n now lands on the n-th physical cup: J1 pads 2–9 now carry IO4, VBAT, IO5, IO1, IO6, IO2, IO7, IO3 (in pad order). D-sub pinouts (both boxes), the adapter-row pinout, connector boards A/B and the A↔B ribbon are all untouched — the change lives entirely on the platform board, and one board serves both boxes as before. Bonus: the ribbon map now equals a standard crimp-on IDC DE-9, and J1's top/bottom header rows correspond 1:1 to the D-sub's top/bottom cup rows. Silk bumped to "Platform baseboard v1.1" with the fan-out order printed next to J1. Edits machine-verified (full connectivity walk sch+pcb, expected-netlist match, 0.2 mm clearance pass); the GND stitch zone's cached fills were stripped — **open in KiCad 10, refill zones (B), run DRC, re-export gerbers** before ordering. A platform board built from pre-remap files needs the old 1:1 harness.
* **2026-08-14 preflight-2 fixes:** conn-A VBAT_RAW clearance at the TPS63001 rerouted (was 0.111 mm — under JLC's 0.127 mm minimum — now ≥ 0.2 mm, re-verified). Walter U3 ideal diode LCSC swapped **C2869734 → C2832141** (LM66100DCKT, same part/footprint — DCKR fell to 9 pcs JLC stock). Rotation-offset fields unified everywhere to the FT-recognized name `FT Rotation Offset`, schematic and PCB in agreement: RAK U3 = **+90°**, RAK U5 = **180°**, conn-B U1 = **−90°** (all verified against the JLC pink-dot preview; conn-B U1's field added to the schematic so a future field re-sync can't drop the PCB value). Walter adapter: **"USB-C THIS END" silk hint** added at the socket's pin-1/VIN end (USB-C end of the module — the 2×14 socket is unkeyed). Fabrication Toolkit `EXCLUDE DNP` now ticked on all four assembled boards. Stock watch at order time: RAK4630 47 pcs, LPS4018 (conn-A L2) 12 pcs, SI4840DY 152 pcs, CAX toggle via Global Sourcing. USB-C receptacle vs 1.6 mm board: **decided 2026-08-14 — keeping the TYPEC-303-ACP16 (C720628) on the standard 1.6 mm board as-is** (shell tabs solder from the top into the slots; maintenance-port duty). Same-day layout polish: conn-B spine widened to 40 mil (2 A path) / 30 mil (panel chain); conn-A TPS63001 input caps moved tight to VIN; RAK I2C pull-ups moved onto the live bus (U2 pins 7/8, vacated D-row pins NC'd); the GND via near the RAK USB-C shell slot relocated (1.49 mm hole-edge gap now); **D-sub SH shield pads tied to GND on both connector boards** (SH pin added to the DE9 symbol, pads picked up by the GND pours). All five boards re-verified: zero opens, fills fresh, no different-net spacing under 0.2 mm outside the accepted RAK USB pair region.

## Shared libraries (from this revision)

All custom symbols and footprints live in **`hardware/pcb/lib/`**:
`TwinOak.kicad_sym` (Platform_interface / Platform_LoRa / Platform_LTE, RAK4630, RV-3028-C7, DPT_Walter,
WiFi_LoRa_32_V3, 8-215570-0, TPS63001) and `TwinOak.pretty/` (platform-adapter-footprint, 82155700, RAK4630,
RV-3028-C7, CPH3225A, USB-C XUNPU, Kinghelm switch, CAX toggle, walter-socket/-solder, Heltec module, TI VQFN).
Every project has its own `sym-lib-table`/`fp-lib-table` pointing at them via `${KIPRJMOD}` relative paths, so the
repo is self-contained — no global-library registration needed. Superseded per-project `.pretty` dirs and the old
`hardware/TwinOak-standard-repeater-layout.kicad_sym` are parked in `hardware/pcb/_superseded/` (delete when happy;
also remove their entries from KiCad's global library tables if you had added them there).
Conventions: power symbols are the standard `power:GND` / `power:+3V3` / `power:VCC` / `power:VIN` / `power:VBAT`
everywhere; every unused pin carries an explicit no-connect flag (T096 adapter excluded — still an unwired stub).

## B-board rail names (your rename, kept)

`PANEL_IN` (J2) → **D4 SS54** (reverse-panel blocking, added 2026-08-11) → `PANEL_RAW`→switch→`PANEL+`→RS2→`VIN` (charger input; **D5 SMBJ26A** TVS clamps `PANEL_IN` to GND) · `BAT_RAW`→switch→`BAT+`→F1→`VBAT`→RS3→`VCC`
(battery rail) · `VCC`→RS4→`VLOAD+` (feeds LTE D-sub pin 2 and ribbon wire 2). INA3221: ch1 = panel (RS2),
ch2 = battery (RS3), ch3 = total load (RS4). Fixed during review: IN-1 rejoined to `VIN`, IN-3 label typo
(`VLOAD`→`VLOAD+`), and both STAT LEDs were reversed (anode must face the VREF/resistor side, cathode the STAT pin).

## Adapter bulk storage (verified)

Each radio adapter buffers its rail at the box entry, per the BOM: Walter = **470 µF 16 V polymer**
(Panasonic 16SEPG470M) + 10 nF (CCT-10N/100V-S); Heltec V3 = **100 µF** (AISHI EWH1CM101E11OT) + 10 nF;
RAK = 2×100 µF MLCC on the 3V3 rail. For the Walter this is sound: LTE-M bursts (~1 A class) ride on the module's
own buck input caps + 470 µF low-ESR, and the 10 Ah battery is close by — no change recommended. If field logs ever
show brown-outs during TX bursts, double C1 to 2×470 µF; don't go polymer→tantalum here.
The Walter adapter also gained a reset micro-switch (SW1, Kinghelm KH-6X6X5H-STM, C2837531) — `WALTER_nRST` to GND,
safe against the module's onboard 10 k pull-up/RC.

## JLCPCB / BOM notes (checked 2026-08-09)

Substitutions vs. previous values (all in stock at LCSC):

| Ref (B-board) | Was | Now | LCSC |
|---|---|---|---|
| R2 (MPPSET) | 36k5 (out of stock everywhere) | **36k** → V_MPP = 17.8 V (was 17.6 V; panel Vmp 18.2 V — still fine) | C4360 |
| F1 | Bourns MF-MSMF300 (not at LCSC) | RUILON SMD1812P300TF/16, 3 A hold | C702820 |
| F2 | generic 0.35 A | PTTC SMD1206P035TF/30 PTC | C438898 |
| C1/C2 (solar input) | 10u 25 V-class | Samsung CL32B106KBJNNNE **50 V** (panel Voc ≈ 21.6 V) | C138687 |
| Q1/Q2 | Si4840BDY (LCSC OOS) | VBsemi SI4840DY-T1-E3-VB (low stock, 131) — check JLCPCB's own stock of C222446 first | C558269 |
| L1 | IHLP4040DZER100M**5A** (C511353 — delisted from the JLC assembly catalog) | IHLP4040DZER100M**11** (same land pattern, Isat 7.1 A) | C845066 |
| D2/D3 | unspecified LEDs | CHG = red C84256, DONE = green C2297 | — |
| R13–R15 (A-board) | 100k C17407 (NRND, delisted at JLC) | same UNI-ROYAL 0805W8F1003T5E re-listed, Basic | C149504 |
| D4 (new, B-board) | — | SS54 5 A/40 V SMA reverse-panel blocking diode in the PANEL_IN feed | C22452 |
| D5 (new, B-board) | — | SMBJ26A 26 V-standoff 600 W SMB TVS, PANEL_IN → GND | C123820 |

Not machine-assemblable (hand-solder, source at Mouser/TME): TE 8-215570-0 ribbon headers, Amphenol L717DFE09PT PCB D-subs, FCE17-E09SM-250 bulkheads. THT JST/screw-terminal parts have LCSC numbers in the schematic if you want JLC THT assembly.
Low-LCSC-stock flags: C13585 (10 µF 1206, JLC Basic stock is separate), C17710 (470 R, same), C2903502 (20 mΩ shunt, 2.6 k pcs), C558269 (see above).

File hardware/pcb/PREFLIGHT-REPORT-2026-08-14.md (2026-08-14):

# TwinOak Standard Repeater v2 — JLCPCB Pre-Order Preflight (round 2)

**Date:** 2026-08-14 · **Scope:** Walter adapter · RAK4630 adapter · Connector board A · Connector board B · Platform board
**Reference:** `hardware/pcb/INTERCONNECT.md` (2026-08-14) as the authoritative spec. Supersedes `PREFLIGHT-REPORT-2026-08-11.md`.

---

## Verdict

**Order-ready after one copper fix, one BOM edit, and one rotation-offset resolution.** Everything that changed since the 2026-08-11 preflight was re-verified from scratch and came back correct: the **RV-3028 second reroute is electrically perfect**, the **platform J1 interleave remap is machine-verified end-to-end across all five boards**, the STAT-LED flip and the D4/D5 panel protection are in and correctly oriented, and every schematic now matches its PCB pad-for-pad with **zero mismatches and zero open (unrouted) nets anywhere**.

| # | Board | Finding | Severity |
|---|---|---|---|
| F1 | Conn A | **VBAT_RAW track 0.111 mm from U4 (TPS63001) L1 node** — under JLC's 0.127 mm fab minimum. Unchanged since last preflight. | **Blocker — must fix** |
| F2 | Walter | **LM66100DCKR (C2869734) has 9 pcs JLC stock** — effectively unorderable | **Blocker — 1 field edit** |
| F3 | RAK | **U5 rotation offset: files say 180°, INTERCONNECT.md says it was zeroed** — one of them is wrong, and a wrong value = dead RTC. Plus U3 offset −90 (sch) vs +90 (pcb). | **Resolve in JLC preview** |
| F4 | All | **Every file in `outputs/` is from July 20** — pre-preflight-fixes, pre-rewire. `production/` is empty. | Re-export everything |
| F5 | RAK / Conn A | Stock watch: RAK4630 **47 pcs**, LPS4018 L2 **12 pcs**, SI4840DY 152, CAX toggle absent from catalog mirror | Order soon / global-source |

Details below, then the verified-clean list, then the updated pre-order procedure.

---

## Critical / high findings

### F1 — Conn A: 0.111 mm clearance at the TPS63001 — BLOCKER, confirmed twice (measured both preflights)
The VBAT_RAW 0.508 mm track ending at **(131.08, 99.438)** passes the U4 L1-node tracks and **U4 pad 4** (at 131.58, 99.438) with **0.111 mm** track-to-track and **0.126 mm** pad-to-track clearance on F.Cu. JLCPCB's 2-layer minimum is 0.127 mm — this **can fail fabrication**, and it violates your own 0.2 mm rule, so KiCad DRC will flag it too. Fix: pull that VBAT_RAW ending ~0.15 mm away from U4 pad 4 (it's the same two routes flagged on 2026-08-11 — the fix never landed).

### F2 — Walter: LM66100DCKR down to 9 pcs at JLC — BLOCKER (1 field edit)
U3's **C2869734** (LM66100DCKR) shows **9 pcs** in the JLC assembly catalog — below any sane MOQ headroom. Same die, drop-in alternatives, both in stock:

| Option | LCSC | Stock (2026-08-14) | Note |
|---|---|---|---|
| **LM66100DCKT** (cut tape) | **C2832141** | 182 | Same part, same SC-70-6 — recommended |
| LM66100QDCKRQ1 (automotive) | C5219211 | 548 | Same footprint, AEC-Q100 |

### F3 — RAK: rotation-offset state is internally inconsistent — resolve before ordering
Fabrication Toolkit reads the footprint field **`FT Rotation Offset`** (verified against FT's docs; `JLCPCB Rotation Offset` is *not* a recognized name). Current live values in the PCBs: RAK **U5 = 180**, RAK **U3 = 90**, Conn B **U1 = −90**. Three problems:

1. **U5 (RV-3028):** INTERCONNECT.md's 2026-08-13 correction says the offset was **zeroed** after the footprint numbering was restored — but the file still carries **180**. One of the two is stale. A wrong 180° on the RTC swaps VDD/VSS diagonally → dead/damaged part on every board. Only the JLC preview (their pink pin-1 dot on your silk dot) settles which is right — **check it deliberately, don't assume**.
2. **U3 (USBLC6):** schematic says **−90**, PCB says **+90** — 180° apart on a SOT-23-6 = supply pins mirrored. The PCB value is the live one; verify it in the preview and fix the schematic field.
3. Hygiene: the schematic still carries the dead-name `JLCPCB Rotation Offset` fields on U3/U5. Rename them to `FT Rotation Offset` with the settled values (or delete them and keep only the PCB fields), so a future field re-sync can't reintroduce the conflict.

Also eyeball in the same preview session: Conn B U1 (BQ24650, −90), Conn A U4 (TPS63001 DRC0010J, no offset field — relies on FT's rotation DB), the USB-C receptacle, the RAK4630 module, and diode polarity on D4/D5/D1/D2/D3 (Conn B) and D1/D2 (RAK).

### F4 — Stale exports: do not upload anything currently on disk
All gerbers in every `outputs/` folder date from **July 20** (pre-preflight fixes, pre-J1-remap), including `platform-board/outputs/platform-board.zip` — uploading that zip would order a **pre-remap platform board** that needs the old harness. `production/` folders are empty. After F1: refill zones, re-run DRC, export fresh Fabrication Toolkit packages on all boards, and consider deleting the stale `outputs/` zips so they can't be uploaded by accident. (Good news: the platform zone fills in the *file* are **fresh** — I verified they clear all foreign nets and complete the GND net, so the INTERCONNECT warning about stripped fills has already been actioned. The stale part is only the exported outputs.)

### F5 — Stock watch (JLC assembly catalog via jlcsearch mirror, 2026-08-14)

| Part | Ref | Stock | Action |
|---|---|---|---|
| C32315253 RAK4630-8-SM-I | rak U4 | **47** (unchanged since 08-11) | 1/board, no substitute — order soon |
| C4354938 LPS4018-222MRC 2.2 µH | conn-a L2 | **12** (unchanged) | JLC Global Sourcing (LCSC has stock) or sub C370436 |
| C558269 SI4840DY (VBsemi) | conn-b Q1/Q2 | 152 | 2/board — fine for a small run, don't sit on it |
| C55159901 CAX toggle | conn-b SW1 | **absent from mirror** | Known: zero JLC warehouse stock — Global Sourcing or hand-solder |
| C3304278 RV-3028-C7 | rak U5 | 429 | OK |
| C2293 LED blue 0805 | rak D2 | 19 k | OK |

All **48 unique LCSC numbers** across the four assembled boards were re-checked today; descriptions/packages match the schematic values in every case. Everything else is deep in stock (thousands to millions).

---

## Medium / low — worth a look while the files are open

1. **RAK: I²C pull-ups still on the D-row** (R1/R2 on U2 pins 17/18; the bus runs on 7/8). In-system fine (platform parallels the rows); bench bring-up over USB with no platform under it has no pull-ups → RTC scan fails. Same nag as last time; move to pins 7/8 if you ever expect to bench-test bare.
2. **RAK: GND via 0.19 mm from the USB-C shell slot** — via at (139.332, 83.058) sits 0.19 mm hole-edge-to-hole-edge from J3's S1 oval slot, under JLC's 0.254 mm hole-to-hole guideline. Same net (GND), so worst case is a DFM remark / drill breakout; nudging the via ~0.1 mm away is free.
3. **Walter: the 2×14 socket still has no orientation hint on silk** (only the A–D row letters on the platform interface). One "USB-C ➜ this end" text prevents a 180° module insertion in the field.
4. **Platform: the J1 fan-out legend documented in INTERCONNECT.md is not on the silk.** The board carries only "Platform baseboard v1.1". Either add the `1,6,2,7,3,8,4,9,5` legend text or amend the doc — as-is, the harness builder needs the doc open.
5. **D-sub shield pads (SH) still float on A and B** — the deliberate-or-not decision from last preflight remains open. Make it conscious.
6. **USB-C vs 1.6 mm board** (repeat): the XUNPU TYPEC-303-ACP16 drawing assumes 0.8 ± 0.1 mm PCB for the through-shell tabs. Confirm the C720628 variant against 1.6 mm before assembly, or order the RAK adapter at 0.8–1.0 mm thickness.
7. **EXCLUDE DNP option differs per board** (rak/conn-a: true; walter/conn-b: false). Now moot — I verified **every** DNP/hand-fit part on all four assembled boards carries both `exclude_from_bom` and `exclude_from_pos_files` in the PCB, so exports come out clean either way — but ticking it everywhere costs nothing and removes the trap.
8. **Conn B: charge-spine widths unchanged** (0.508 mm / 20 mil bottleneck, ~+20 °C at 2.0 A peak-sun). Concrete fix: widen **20 mil → 40 mil (1.0 mm)** on the 2 A battery-charge spine — that takes the rise from ~+20 °C to **~+7 °C** (30 mil ≈ +10 °C, 50 mil ≈ +4.5 °C, IPC-2221 1 oz external). The runs that carry the full 2 A (KiCad coords, F.Cu unless noted):
   * SRP node `Net-(U1-SRP)`: L1.2 (146.8, 57.0) → C10.1 → RS1.1 (143.8, 53.3), ≈ 8 mm (the C8/C9 branch at x ≈ 151.6 carries ripple — widen if easy)
   * `VCC` spine link RS1.2 → RS3.1: (143.8, 50.4) → (143.8, 48.5)
   * `VBAT`: RS3.2 (143.8, 45.5) → F1.1 (142.5, 42.2), ≈ 4.5 mm
   * `BAT+`: F1.2 (146.8, 42.2) → SW1.5 (149.8, 38.2), ≈ 6.5 mm
   * `BAT_RAW` (B.Cu): SW1.4 (149.8, 42.9) → J7.2 (143.8, 34.3), ≈ 12 mm
   * PH node `Net-(U1-PH)`: Q1 source (145.3, 73.4) → Q2 drains (y = 69.5) → L1.1 (146.8, 66.0), ≈ 8.5 mm — same 2 A, and shorter/wider is also better for EMI

   The panel-side ~1.2 A chain sits at ~+6 °C and is nice-to-have at 30–40 mil: `Net-(D4-A)` J2.1 → D4/D5 (≈ 40 mm, mostly B.Cu at x ≈ 166.3), `PANEL_RAW` D4.1 → SW1.1 (≈ 21 mm), `PANEL+` SW1.2 → RS2.1 (≈ 17 mm B.Cu), `VIN` RS2.2 → C1/C2 (≈ 8 mm) plus the 14.6 mm feed at x = 142.7 down to the Q1 drains. While in there, add a **second via in parallel** at the three spots where panel current crosses layers through a single 0.6/0.3 via: (167.1, 58.7), (149.9, 47.2), (149.9, 50.2). Do **not** widen the 0.254 mm kelvin/sense taps — U1 pins 9/10 (SRN/SRP), the four long INA3221 taps at x ≈ 141.9–143.3, the U2.1 run at y = 93.1, and the R3 VFB tap are all correct thin (widening them adds no capacity and hurts sense accuracy). The 2 A spine itself never crosses a via — all F.Cu/THT — so tracks are the whole story.
9. **Conn B: D5 drawn with a bidirectional-TVS symbol** but SMBJ26A is unidirectional. Copper is right (cathode band to panel+, forward-conducts on reversed panel — which even complements D4). Cosmetic only.
10. **RAK: J3 S1 slot annular 0.125 mm** and **Conn B: SW1 mounting-post pad at 0.024 mm from board edge / zero-annular oval** — both are the connector-manufacturer land patterns, both known; expect at most DFM remarks.

---

## Verified clean — what I checked and found correct

**Schematic ↔ PCB sync:** independent geometric netlists rebuilt for all five schematics and compared pad-for-pad against the copper netlists in the PCBs — **100 % agreement, all five boards** (conn-a's stale name sync from last time is gone).

**Routing completeness:** every net on every board is a single connected copper island (pads + tracks + vias + zone fills) — **zero open nets**. This specifically confirms: **U5's second reroute is correct** (SCL→pad 3, SDA→4, VSS→5, VBACKUP→6, VDD→7, EVI→8 on the restored numbering, matching the shared lib exactly), the **platform rewire is fully routed**, and Conn B's **D4/D5 are placed and routed**.

**Platform J1 remap, machine-verified end-to-end:** RAK pin → adapter interface → platform row → J1 conductor → (1,6,2,7,3,8,4,9,5) solder-cup fan → D-sub → A-board → ribbon → B-board → LTE D-sub → platform → Walter pin, for every signal:

| Signal | LoRa D-sub | Ribbon wire | LTE D-sub | Walter pin | Result |
|---|---|---|---|---|---|
| nRESET | 3 | 3 | 3 | IO1 | **PASS** |
| SWDCLK | 4 | 4 | 4 | IO2 | **PASS** |
| SWDIO | 5 | 5 | 5 | IO4 | **PASS** |
| I2C_SCL | 6 | **10** | — (INA3221) | — | **PASS** |
| I2C_SDA | 7 | 7 | — (INA3221 + A0=0x42) | — | **PASS** |
| UART RX←TX | 8 | 8 | 8 | IO7 | **PASS** |
| UART TX→RX | 9 | 9 | 9 | IO8 | **PASS** |
| KILL | — | 6 | 6 | IO5 | **PASS** |
| 3V3_LORA / VLOAD+ | 2 | 2 (VBAT_RAW) | 2 | VIN via LM66100 | **PASS** |
| GND / spare | 1 / — | 1 | 1 / 7 NC'd | GND / IO6 | **PASS** |

J1 pad 10 has no net (unused conductor) ✓; odd conductors = A/C rows, even = B/D rows exactly as documented ✓; silk bumped to v1.1 ✓.

**Fixes from the 08-11 preflight, confirmed landed:** STAT LEDs D2/D3 now anode→R7/R8→VREF, cathode→STAT1/2 (open-drain sink — correct) ✓ · D4 SS54 anode→J2.1, cathode→PANEL_RAW ✓ · D5 SMBJ26A cathode→panel input, anode→GND ✓ · R13–R15 = C149504 ✓ · L1 = C845066 ✓ · Walter U1/U2 now DNP + excluded ✓ · Walter C1/C2/J1, RAK J4/J5, A-board JP1/J1/J2, B-board J1/J5 all carry exclude-BOM **and** exclude-POS attributes in the PCBs ✓ (the 08-13 cleanup is complete — no unmatched JLC lines regardless of options).

**Electrical re-checks (this round):** kill chain J2.6→R12→Q3 (R13 pulldown, R14 pullup to VBAT_RAW) → TPS63001 EN, default-ON when floating ✓ · TPS63001 pin-complete, FB→VOUT (fixed version), PS/SYNC low via R15 with JP1 forced-PWM option ✓ · BQ24650 network recomputed: MPPT divider 499k/36k, 4.2 V float (499k/499k), TS window (5k23/30k1 vs VREF), TERM_EN=enabled, bootstrap D1 A→REGN/K→BTST, SRP/SRN across RS1 with C10 differential cap ✓ · INA3221 ch1=RS2(panel), ch2=RS3(battery, bidirectional), ch3=RS4(load), A0→SDA=0x42, powered from the always-on MCP1700 ✓ · LM66100: VCC→VIN, VOUT→WALTER_VIN, CE→GND ✓ · USB path J3→USBLC6 flow-through→nRF USB, D+→D+, CC 5.1 k, shield→GND ✓ · RV-3028: VDD/VSS/backup bank/EVI pull-up ✓ · UART jumpers J4/J5 1-2 = Serial1 (P0.15/16) ✓ · rail chain PANEL_IN→D4→PANEL_RAW→SW1→PANEL+→RS2→VIN and BAT_RAW→SW1→BAT+→F1→VBAT→RS3→VCC→RS4→VLOAD+ ✓ (ribbon feed deliberately unfused, per spec).

**NC / DNP audit:** zero unconnected pins without NC flags, zero NC-but-connected conflicts, on all five boards (61 explicit NCs). B-board J1.7 spare NC'd ✓.

**Board-level:** outlines closed on all five ✓ · min drill 0.3 mm everywhere ✓ · via 0.6/0.3 ✓ · zone fills present and fresh on all boards (they clear all foreign nets — platform's post-rewire refill is in the file) ✓ · different-net clearance sweep: **nothing below 0.127 mm anywhere except F1**; the only sub-0.2 items are the known USB differential pair on the RAK (0.146–0.196 mm, deliberate) and a handful of 0.17–0.19 via gaps in the same USB area — DRC nags, fab-safe ✓ · all SMD front-side, single-side assembly ✓.

**BOM:** every machine-placed part on all four assembled boards carries `LCSC Part #` ✓; platform is all hand-solder THT (order bare, **2 per repeater**) ✓; 48/48 part numbers live and matching their schematic values ✓ (stock exceptions in F2/F5).

---

## Pre-order procedure (do in this order)

1. Conn A: nudge the VBAT_RAW ending at (131.08, 99.438) ≥ 0.2 mm off the U4 L1 node (F1).
2. Walter schematic: U3 `LCSC Part #` → **C2832141** (F2). Update PCB from schematic.
3. Field hygiene: rename the schematic `JLCPCB Rotation Offset` fields on RAK U3/U5 to `FT Rotation Offset` and settle their values; decide U5 = 0 or 180 **only** via the JLC preview (F3).
4. Decide/confirm: L2 sourcing (Global Sourcing vs C370436), CAX toggle (Global Sourcing vs hand-solder), SH-to-GND, USB-C vs 1.6 mm board.
5. Every touched board: *Update PCB from Schematic* → refill zones → **run real ERC + DRC in KiCad 10 locally** (this sandbox still can't run v10 — my geometric sweep is not a substitute; expect it to also show the known USB-pair nags).
6. Fabrication Toolkit export per board (EXCLUDE DNP ticked for tidiness) → fresh `production/` zips only — treat everything in `outputs/` as stale (F4).
7. In the JLC order tool: confirm rotations against the pink-dot preview (U5, U3, conn-b U1, conn-a U4, USB-C, RAK module, all diodes), confirm live stock for the F5 list, expect unmatched lines only if a hand-solder part slipped through (none should).
8. Order: platform ×2 per repeater (bare), other boards with front-side SMD assembly; conn-b THT set via JLC THT or hand.

## Open items only you can close

U5 rotation offset truth (JLC preview) · USB-C vs 1.6 mm (or thinner RAK board) · SH-to-GND decision · CAX toggle sourcing · RAK module stock timing (47 pcs) · harness pin-1 discipline at build time · RTC TCE=1 / BSM=LSM firmware config (unchanged from last report).

---

*Method: independent geometric netlister (transform-validated, 100 % pad-net agreement with all five PCBs) + full-copper connectivity (pads/tracks/arcs/vias/zone fills) + different-net clearance sweep + hole/annular/edge audits, all rebuilt from the current working-tree files (which match git HEAD apart from line-ending churn — no uncommitted design changes). Cross-board walk executed programmatically against INTERCONNECT.md's 2026-08-14 map. Stock: jlcsearch mirror of the JLC assembly catalog, 2026-08-14 — re-verify the F5 watch-list at upload time. FT field-name behaviour verified against the Fabrication Toolkit documentation.*

---

## Addendum — 2026-08-14 evening (post-review fixes, verified)

* **F1 FIXED and re-verified:** the conn-A reroute landed — minimum different-net spacing on the board is now exactly 0.2 mm (your rule limit, passes), zero open nets, schematic↔PCB sync intact.
* **F2 applied:** Walter U3 → **C2832141** (LM66100DCKT, 182 pcs), schematic + PCB fields both updated.
* **F3 resolved:** PCB values confirmed correct per TH's JLC preview check. Fields renamed to `FT Rotation Offset` everywhere; RAK sch U3 corrected −90 → **+90** to match the verified PCB value; conn-B U1's −90° field added to the schematic so a field re-sync can't drop it. INTERCONNECT.md corrected (the "zeroed" claim was the stale statement).
* **Walter silk hint added:** "USB-C / THIS END" on F.Silk at (148.6, 67.8), inside the module outline at the pin-1/VIN end — visible while inserting, clear of all pads and footprint silk.
* **EXCLUDE DNP** ticked in walter + conn-B Fabrication Toolkit options (now true on all four assembled boards). No DNP/exclude attributes were missing — verified again.
* **USB-C vs 1.6 mm (medium #6):** no *verified* drop-in found. Same-series XUNPU height variants exist — TYPEC-303-ACP16H056 (C53278835), H065-B/-O (C53278836/37), H068-B/-O (C53278838/39), 180–600 pcs each — one of these may be the taller-stack/longer-tab version, but the drawings are image-only and need a 2-minute human check on LCSC. Fallbacks: order the RAK adapter at 0.8–1.0 mm (JLC standard; board is small and carried by the 20-pin interface), or keep 1.6 mm and accept top-side-soldered shell tabs (reduced retention; maintenance-port duty only).

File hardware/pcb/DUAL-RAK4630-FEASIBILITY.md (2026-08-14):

# Dual-RAK4630 Adapter — Feasibility Investigation

*TwinOak standard repeater v2 · 2026-08-11 · updated 2026-08-12 (§6: same-channel bridge addendum)*
*Scope: a new LoRa-box adapter carrying **two** RAK4630 stamp modules. Walter adapter, platform boards, connector boards A and B stay **exactly as designed**. Remote flashing and control of both modules via the Walter must work as it does today for the single module.*

**Verdict: feasible.** The D-sub is not actually the blocker — you don't need more pins. What you need is *target selection inside the LoRa box*, and there is a clean way for the Walter to signal "which module" over the existing lines, with **zero firmware on the adapter** and no dependency on either RAK being alive. Everything reduces to one new adapter PCB plus a ~20-line addition to the Walter's firmware.

---

## 1. What the adapter actually receives

Per `INTERCONNECT.md`, the dual adapter sees exactly what the single one sees (LoRa-box D-sub, via the unchanged platform board):

| Pin | Net | Direction (adapter view) |
|---|---|---|
| 1 | GND | — |
| 2 | 3V3_LORA (A-board TPS63001) | power in |
| 3 | LORA_nRESET (Walter IO1) | in |
| 4 | LORA_SWDCLK (Walter IO2) | in |
| 5 | LORA_SWDIO (Walter IO4) | bidir |
| 6 | I2C_SCL (to INA3221 on B) | out (RAK is master) |
| 7 | I2C_SDA | bidir |
| 8 | LORA_UART_RX (← WALTER_TX) | in |
| 9 | LORA_UART_TX (→ WALTER_RX) | out |

One reset, one SWD port, one UART, one I2C master role — for two modules. Those are the four sharing problems; each has a clean answer.

## 2. The four sharing problems

### 2.1 SWD — you must multiplex; you cannot parallel

The obvious hope is SWD multi-drop (several targets parallel on one SWDIO/SWDCLK, selected via `TARGETSEL`). **The nRF52840 does not support it** — multi-drop requires an ARM DPv2 debug port, and Nordic has confirmed the nRF52840's SW-DP has no multi-drop capability. Two live DPs paralleled on one wire pair would both respond to the line-reset + `DPIDR` read and fight over SWDIO.

So the SWD pair must be **switched** to one module at a time with an analog switch. This is trivial electrically: the Walter bit-bangs SWD at ≲300 kHz through the A-board's 470 Ω series resistors and two 1000 pF bulkhead filters (τ ≈ 1 µs — already the speed limiter). A 10 Ω analog switch (TS5A23157, LCSC **C11133**) in the path is invisible at those speeds. The unselected module's SWD pins float safely — nRF52 keeps an internal pull-up on SWDIO and pull-down on SWDCLK.

### 2.2 nRESET — one line, two targets

If nRESET were shared, every flash of module B would also reboot module A. So nRESET is **routed** (same SPDT approach) to the selected module only, and each module keeps its own local reset push-button (2× Kinghelm KH-6X6X5H-STM, as on the current adapter). The unselected module's reset gets a local 10 k pull-up so it idles released. Pin-reset on nRF52 is hard-wired behaviour (via UICR `PSELRESET`), so a hung module can always be reset — same caveat as today: a full chip-erase clears UICR, and your Walter flasher must restore `PSELRESET` afterwards. You already live with this on the single-RAK design, nothing new.

### 2.3 UART — stock MeshCore is point-to-point, so mux it

MeshCore's serial interface is a point-to-point protocol with no device addressing. Two stock-firmware nodes cannot share one UART as a bus (both would answer, and both would emit unsolicited traffic). Two honest options:

* **Analog mux (recommended).** Walter's TX is routed to one module's RX, and that module's TX is routed back. One TS5A23157 handles both directions. The unselected module's RX is pulled up to idle-high; its TX simply goes nowhere. Fully transparent to MeshCore — the Walter just decides *who it is talking to*, exactly like plugging the cable into the other module.
* **Bridge MCU (your "UART bridge" idea).** A small MCU on the adapter speaks to the Walter on one UART and fans out to both RAKs, adding an addressing layer. It works, but it adds a third firmware image, a flashable single point of failure between you and both radios, and it cannot carry SWD (so you still need the switching logic for flashing). Given that the mux gives you everything the bridge would except *simultaneous* streaming from both modules, the mux wins. (If you ever want concurrent streams, the ATtiny variant in §4 can grow into a concentrator later.)

Switching the mux mid-stream can corrupt at most one byte; the Walter chooses when to flip, so in practice it flips between polls.

### 2.4 I2C — segment the bus; never share the master role

Three hard constraints collide here: the LoRa module is the *single* I2C master by design; nRF52 TWIM has no multi-master arbitration; and both modules running stock MeshCore will each want an RV-3028 RTC, which has a **fixed address 0x52** — two of them cannot coexist on one bus anyway. The clean answer is segmentation, no switching required:

* **RAK-A's bus = today's bus, unchanged.** Its P0.13/P0.14 carry its own RV-3028 (with backup caps, riding through kills) *and* the D-sub SCL/SDA out to the INA3221 on the B-board, with the same 1 k pull-ups to 3V3_LORA (still needed — the bulkhead's ~1.2 nF is unchanged).
* **RAK-B gets a private bus.** Its P0.13/P0.14 see only its own RV-3028 with ordinary 4.7 k pull-ups (short traces, no filter caps). MeshCore auto-detects the RTC exactly as on module A.

Consequence: battery telemetry (INA3221) is visible to module A only. That is the right outcome anyway — with both modules running MeshCore you want exactly one of them reporting battery state, not two nodes double-polling one sensor. Module A is thereby the "primary" node. (If you ever need B to reach the INA3221, the spare half of one TS5A23157 can steer the external segment — but I'd leave that off v1.)

## 3. The clever part — selecting a target over the existing wires

The select logic must satisfy three requirements: controllable by the Walter using only pins 3/4/5/8/9; **no dependency on either RAK being alive** (a bricked module must always be reflashable — this rules out any scheme where a RAK sets the mux, e.g. an I2C GPIO expander, which dies with its master); and defined behaviour at power-on.

**Key observation:** in normal operation and in every sane flash sequence, SWDCLK never toggles *while nRESET is held asserted*. The Walter owns both lines, so you can simply make that a rule of your flasher — which turns "SWDCLK edges during reset-low" into a free, unused signalling channel. No new pins, no new protocol on any existing traffic.

**Implementation — a 2-bit shift register, no MCU:**

```
                        ┌──────────────────────────────┐
 nRESET (pin 3) ───┬───►│ 1G97: CLK_EN = ~nRESET       │
 SWDCLK (pin 4) ───┼───►│ SHIFT_CLK = SWDCLK & ~nRESET │
                   │    └──────────────┬───────────────┘
                   │                   ▼
 SWDIO (pin 5) ──── D ──►[FF1 1G175]──►[FF2 1G175]     RC on CLR pins:
                          │ Q = DEBUG_SEL │ Q = UART_SEL   power-on = 0,0 → module A
                   │      ▼               ▼
                   │   SPDT: SWDIO/SWDCLK/nRESET → A or B   SPDT: UART TX/RX → A or B
                   │
                   └──►[RC ~2–5 ms + 1G17 Schmitt]──► nRESET to *selected* module
```

* **Parts:** 2× SN74LVC1G175 D-FF with clear (LCSC C2677755 / C202238), 1× 74LVC1G97 configurable gate (computes `SWDCLK AND NOT nRESET`), 1× 74LVC1G17 Schmitt buffer, 3× TS5A23157 dual-SPDT (C11133) — six SC70/MSOP-class chips, all JLC-assemblable, **zero firmware**.
* **Programming a selection:** Walter drives nRESET low, clocks 2 bits in on SWDCLK with SWDIO as data (FF2's bit first), releases nRESET. Takes microseconds. Idempotent — the Walter never needs to *know* the current state, it just re-programs it before every operation.
* **The reset that programs the mux never reaches the radios.** nRESET toward the modules passes an RC (~2–5 ms) + Schmitt buffer, so the sub-millisecond programming window is filtered out entirely. Flipping the UART from A to B **does not reboot anything**. A real reset = Walter holds nRESET ≥ 50 ms (which also still supports the bootloader's double-tap DFU entry, per module). The pulse must exceed the ~1 µs bulkhead RC, so a 100–500 µs programming window is the sweet spot.
* **Power-on default = module A** (RC clear on the FFs), so a fresh unit behaves exactly like the single-RAK design until told otherwise.
* **Stray-clock safety:** during the programming window the 2–3 SWDCLK pulses do reach the previously-selected module's SWD pins, but a valid SWD transaction needs a full 8-bit header — a couple of stray clocks cannot form one. Conversely, if a Walter reboot ever glitches a spurious bit into the FFs, nothing breaks: the next operation re-programs the state anyway.
* **Bench override:** two 3-pin THT jumpers (repo convention) can force DEBUG_SEL / UART_SEL to A or B, bypassing the FFs during bring-up.

**Why two independent bits:** DEBUG_SEL (SWD + reset) and UART_SEL are separate, so the Walter can keep the live console on module A *while* it flashes module B over SWD. A one-bit version saves one FF and loses that.

**Alternative implementation:** one ATtiny202/402 decoding the same (or a richer) signalling scheme and driving the three select lines. One chip instead of four logic parts, and extensible (pulse-width protocols, UART concentration). Cost: a third firmware image and a factory UPDI-programming step. For an unattended hilltop box I'd take the discrete logic — it cannot be bricked, ESD-corrupted, or version-skewed. Both fit the board.

## 4. Walter firmware rules (the entire software cost)

1. Never toggle SWDCLK while nRESET is asserted, except deliberately, to program the select register (reorder the flash sequence if it currently clocks during reset — attach via the normal SWD line-reset sequence with nRESET released).
2. Program the select register explicitly before every SWD or UART operation; assume nothing about its current state.
3. Real resets: hold nRESET ≥ 50 ms. Select programming: 100–500 µs window.
4. After a full chip-erase, restore UICR `PSELRESET` (existing rule, unchanged).
5. Tristate nRESET/SWD/UART before asserting LORA_PWR_KILL (existing rule, unchanged).

## 5. Power

* **Rail capacity:** TPS63001 on the A-board delivers ~1.2 A in step-down mode (V_IN ≥ 3.6 V) and ≥ 800 mA worst-case across the LiPo range. Worst-case dual load — both nRF52840s active plus both SX1262s in TX at +22 dBm (118 mA typ each) — is ~260–300 mA. Comfortable margin; no A-board change needed.
* **Bulk:** double the adapter's rail bulk to 4× 100 µF MLCC (two per module, per the current BOM pattern), plus each module's RTC keeps its own 2× 100 µF backup pair.
* **Energy budget (the real cost):** an always-listening MeshCore node is roughly 8–15 mA at 3.3 V (nRF52 + SX1262 RX 4.6 mA, DC-DC). A second radio roughly **doubles the site's quiescent draw** — ~0.2–0.3 Ah/day extra at battery voltage. With the 10 Ah battery: no-sun autonomy drops from ~35–40 days to ~18–22 days. The 10 W panel still covers it in any realistic Danish winter, but the dual box has half the dark-weather reserve of a single. Worth stating on the site sheet.
* **Kill line:** LORA_PWR_KILL cuts 3V3_LORA — i.e. **both** modules together. You cannot power-cycle one module alone. In practice this doesn't matter: per-module pin-reset (routed) plus SWD recovery covers every soft-failure mode, and rail-kill remains the big hammer. Per-module load switches could be added, but need a third select bit — not worth it for v1.

## 6. RF — two antennas, both modules on air

You've chosen two separate antennas (second N/SMA bulkhead on the LoRa box, both RAK4630s the u.FL variant, pigtails only — still no RF on the PCB). The numbers that matter:

* **Damage:** SX1262 absolute-maximum RF input is **+10 dBm**. At +22 dBm TX, you need > 12 dB antenna-to-antenna isolation to protect the other receiver — vertically separated collinears on one mast give ~25–40 dB, so damage is a non-issue with any sane mounting. Aim for ≥ 30 dB (≥ 1–2 m vertical spacing; two verticals can't use cross-pol).
* **Desense is unavoidable:** at 30 dB isolation the victim still sees ~-8 dBm during the other's TX — total front-end blocking for that airtime. With LoRa repeater duty cycles (≲1–2 %) the throughput cost is small, but any packet arriving during the neighbour's TX is lost. This is inherent to co-located radios, not to this board.
* **Same channel:** pointless co-location (two omnis, same coverage) just doubles airtime for nothing. But the **bridge configuration is the legitimate same-channel case** — see §6.1.
* **Filtering:** the cavity filter serves module A's chain as today. Module B gets its own inline filter; in the same-channel bridge configuration it is simply a second unit of the same part (CF866.5KT30-class), which keeps the two-feedthrough plan a straight copy of the existing chain.

### 6.1 Same-channel bridge (the planned configuration)

Planned deployment: **RAK-A on the omni** (local coverage), **RAK-B on yagi(s)** toward one or more distant sites — a deliberate long-distance bridge, both radios on the DK standard channel, linked to each other through antenna-to-antenna coupling.

* **The site-internal link is guaranteed, not hoped-for.** Co-mounted antennas couple at ~25–45 dB isolation, so a +22 dBm TX is heard by the sibling at roughly −10 to −25 dBm against a ≈ −124 dBm sensitivity floor (SF8/62.5 kHz) — around **100 dB of margin**. Even a yagi back-lobe into an omni 2 m up the mast lands near −50 dBm. Any mounting that isn't actively adversarial works.
* **The real constraint is the opposite one:** stay under the SX1262's +10 dBm abs-max input, i.e. > 12 dB isolation — only violated if the yagi's main lobe fires point-blank (< ~0.5 m) into the omni. Mount the omni above/behind the yagis, out of boresight.
* **Costs, inherent to the topology:** every packet in range is repeated twice from one site (extra airtime/duty cycle), and each radio is deaf while the other transmits (same-channel "channel busy" — when they collide, it is usually with the same packet). MeshCore's dedup prevents repeat loops.
* **ERP on the yagi chain needs checking:** +22 dBm into a 12 dBi-class yagi minus ~2 dB filter+coax ≈ **+32 dBm ERP** vs the 500 mW (27 dBm) allowance of the 869.4–869.65 MHz sub-band. Because the Walter reaches each module independently (§3), run **asymmetric TX power**: omni node at the network standard, bridge node trimmed to ~16–17 dBm. RX keeps the full yagi gain either way, which is most of what the long shot needs.
* **Multi-yagi option (3-way combiner, three bridges at once):** a real 3-way divider costs 10·log 3 ≈ 4.8 dB + ~0.5–1 dB insertion. TX side that is self-solving — ~16.5 dBm per port ⇒ ≈ 26.5 dBm ERP per lobe at full +22 dBm TX, no power trim needed. The hidden price: the **same ~5.5 dB comes off RX** on all three bridges, and the receiver sums noise from all three bearings (one noisy azimuth raises the floor for all three links). Keep bearings well separated (> ~60°, no far site visible in two lobes — coherent feed means overlap ripple/nulls). Trick: cascade two 2-way splitters (−3.5/−7/−7 dB) and give the −3.5 dB port to the longest link (re-check that lobe's ERP, ≈ 28 dBm at 12 dBi). Use a proper 50 Ω Wilkinson-type divider rated through 868 MHz, not a 75 Ω CATV splitter. Combiner sits radio → filter → splitter → yagis, so one filter still serves the whole bridge side. If one link proves marginal in the field, fall back to a dedicated yagi on B and let nearer sites ride the omni.

## 7. Mechanical / layout

The platform-adapter footprint fixes the interface: 53.56 × 58.42 mm outline, four 5-pad header groups near the corners. Budget on that canvas: 2× RAK4630 (24.6 × 16.6 mm courtyard each), 2× RV-3028 + backup caps, 2× vertical USB-C (XUNPU TYPEC-303-ACP16) + ESD + CC resistors, 2× reset buttons, 6 small logic/switch chips, pull-ups, override jumpers. That is dense but plausible — roughly 2× the current adapter's population on the same area, and the current board has generous free space. Fallbacks if it won't route: hardwire Serial1 (drop the per-module J4/J5 jumpers — MeshCore default anyway), move the override jumpers to the back, or let the PCB overhang the platform outline (only the pad positions are sacred — check clearance to the box wall and the harness first). Both u.FL connectors face up with short pigtail runs to the two bulkheads.

USB note: two independent USB-C ports, one per module, same circuit as today (USBLC6-2SC6 + 5k1 CC pull-downs each). Nothing shared, nothing clever — in the field you plug the laptop into the one you mean.

## 8. What does NOT change

Walter adapter, both platform boards, connector board A, connector board B, both D-sub pinouts, the ribbon, the harness, the kill circuit, the flashing transport, the I2C architecture as seen from outside the box. The entire delta = one new PCB (`adapter-rak4630-dual`) + the Walter firmware rules in §4.

## 9. New-parts BOM sketch (all LCSC, JLC-assemblable)

| Qty | Part | Role | LCSC |
|---|---|---|---|
| 3 | TS5A23157DGSR dual SPDT, 10 Ω | SWDIO+SWDCLK / nRESET / UART TX+RX routing | C11133 |
| 2 | SN74LVC1G175 (SOT-23-6 / SC70) | select shift register | C2677755 / C202238 |
| 1 | 74LVC1G97 | clock gate `SWDCLK & ~nRESET` | check stock (any 1G00+1G04 pair substitutes) |
| 1 | 74LVC1G17 | Schmitt on filtered nRESET | check stock |
| 1 | RAK4630-8-SM-I (u.FL) | second radio | consigned/RAK as today |
| 1 | RV-3028-C7 + 2× 100 µF | second RTC + backup | as current BOM |
| 1 | XUNPU TYPEC-303-ACP16 + USBLC6-2SC6 + 2× 5k1 | second USB port | as current BOM |
| 1 | KH-6X6X5H-STM | second reset button | C2837531 |
| — | RC parts: FF clear (POR), reset filter, pull-ups (RX idle, nRESET, B-bus 4.7 k) | glue | basic parts |

## 10. Residual risks / open items

1. **Layout density** on the fixed 53.56 × 58.42 mm outline — do a placement study before committing (the one genuinely unknown item).
2. **Walter flasher sequence audit** — confirm it never clocks SWDCLK during asserted reset today; reorder if it does.
3. **Enclosure** — second N/SMA bulkhead hole + second filter + antenna spacing on the mast (site-side, not board-side).
4. **Select-logic bring-up test** — verify the RC/Schmitt reset filter passes double-tap DFU timing and blocks the programming window on the real bulkhead capacitances; values are trimmable (THT-friendly 0603s).
5. If you later want *simultaneous* UART streams from both modules, swap the discrete select logic for the ATtiny variant — footprint-compatible decision you can defer.

## Sources

- [Nordic DevZone — nRF52840 SW-DP multi-drop support (Nordic: not supported)](https://devzone.nordicsemi.com/f/nordic-q-a/51470/does-the-nrf52840-support-sw-dp-multi-drop)
- [Semtech SX1261/2 datasheet — abs-max RF input +10 dBm, RX 4.6 mA DC-DC, TX 118 mA @ +22 dBm](https://uelectronics.com/wp-content/uploads/2022/12/Datasheet-LoRa-SX1262.pdf)
- [TI TPS63001 datasheet — output-current capability](https://www.ti.com/lit/ds/symlink/tps63001.pdf)
- [LCSC — TS5A23157DGSR (C11133)](https://www.lcsc.com/product-detail/Analog-Switches-Multiplexers_Texas-Instruments_C11133.html)
- [LCSC — SN74LVC1G175 (C2677755 / C202238)](https://www.lcsc.com/product-detail/Flip-Flops_Texas-Instruments_C2677755.html)
- Repo: `hardware/pcb/INTERCONNECT.md`, `adapter-rak4630/rak4630-adapter.kicad_sch`, `connector-board-a/connector-board-a.kicad_sch`, `lib/TwinOak.pretty/platform-adapter-footprint.kicad_mod` + `RAK4630.kicad_mod`

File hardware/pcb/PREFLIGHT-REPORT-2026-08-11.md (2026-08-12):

# TwinOak Standard Repeater v2 — JLCPCB Pre-Order Preflight

**Date:** 2026-08-11 · **Scope:** Walter adapter · RAK4630 adapter · Connector board A · Connector board B · Platform board
**Reference:** `hardware/pcb/INTERCONNECT.md` (2026-08-09) treated as the authoritative spec.

---

## Verdict

**Not ready to order yet — but very close.** The system design is sound and the cross-board wiring is verified correct end-to-end. There are **2 critical items, 1 confirmed wiring bug and 2 BOM blockers**, all cheap to fix:

| # | Board | Finding | Effort |
|---|---|---|---|
| F1 | RAK adapter | **RV-3028 RTC footprint is mirrored** → dead RTC | Renumber 8 pads + reroute a small area |
| F2 | RAK adapter | **RAK4630 stamp footprint chirality unverified** — must be closed before ordering | 2-min STEP/print check (you) |
| F3 | Connector B | **Both STAT LEDs reversed** → CHG/DONE never light | Flip 2 symbols, no reroute |
| F4 | Conn A + B | **C17407 and C511353 delisted from JLC catalog** | 2 field edits (drop-in subs found) |
| F5 | Connector B | No reverse-panel protection (decision needed, not necessarily a change) | Your call |

Everything else — including all the things you asked about explicitly — checks out. Details below, worst first, then the clean list, then your 9 questions answered, then the exact pre-export procedure.

---

## Critical / high findings

### F1 — RV-3028-C7 footprint mirrored (RAK adapter U5) — CRITICAL, confirmed twice
`lib/TwinOak.pretty/RV-3028-C7.kicad_mod` pad layout, measured from the file:

```
top row  L→R:  4  3  2  1      real part (Micro Crystal DS, top view):  1  2  3  4
bottom   L→R:  5  6  7  8                                               8  7  6  5
```

The real C7 package numbers clockwise (1 top-left → 4 top-right → 5 bottom-right → 8 bottom-left); the footprint numbers counter-clockwise. That's a chirality error — **no rotation of the part can fix it** (rotating 180° gives top row 8,7,6,5 — still wrong). As drawn, the soldered part gets SDA on VDD's pad, VSS/VDD scrambled → dead RTC, possibly stressed part.

**Fix:** in the footprint editor swap pad numbers **1↔4, 2↔3, 5↔8, 6↔7** (keep silk pin-1 dot where the part's lid dot will actually sit — top-left). Then in the PCB: *Update Footprints from Library* on U5, and **reroute the U5 area** — the four signal pads swap sides, existing tracks will connect wrong nets. Re-run DRC after.

Verified independently: Micro Crystal RV-3028-C7 datasheet + application manual (3 extractions) and my own pad-coordinate dump above agree. Symbol pin *functions* (CLKOUT/INT/SCL/SDA/VSS/VBACKUP/VDD/EVI = 1-8) are correct — only the footprint is wrong.

### F2 — RAK4630 stamp footprint orientation: verify before ordering — treat as CRITICAL until closed
Everything textual about `TwinOak.pretty/RAK4630.kicad_mod` matches RAK's official pin-definition table: **all 44 pad functions, 23×15 mm body, 1.2 mm pitch, 13/9/13/9 pads per edge, RF keep-outs adjacent to RF_BT(15)/RF_LoRa(37)** — zero mismatches. What could *not* be verified remotely is the chirality (which long edge carries pins 1–13): RAK documents that only in images, and every image/PDF/CAD source was blocked or bitmap-only (docs images, SnapEDA, EasyEDA/LCEDA API, datasheet mirrors, LCSC drawing). Since F1 proves this library can contain a mirrored footprint, close this one deliberately:

* **Best:** download RAK's official STEP (`3D_RAK4630.stp`, downloads.rakwireless.com → LoRa → RAK4630 → 3D_File — the footprint already references this filename but the file is missing from the repo), assign it to the footprint, open the 3D viewer, and check pin-1/IPEX corner against the module photos on the RAK product page.
* **Or:** 1:1 print of the layout vs. a physical module.

A mirrored castellated stamp = scrap boards, so this 2-minute check is the single most valuable remaining action.

### F3 — STAT LEDs reversed on connector B (D2 CHG, D3 DONE) — HIGH, confirmed
Netlist and PCB pads both show **anode → STAT pin, cathode → R7/R8 → VREF node**. BQ24650 STAT1/2 are open-drain *sinks* (TI datasheet, typical application: anode to pull-up rail, cathode to STAT). As wired the diodes are reverse-biased whenever STAT asserts → **CHG/DONE can never light** (no damage — 3.3 V reverse is fine). The 2026-08-09 changelog in INTERCONNECT.md line ~140 says this was "fixed during review" — the fix is **not in the current files** (never landed or regressed). **Fix:** flip D2 and D3 in the schematic; the nets swap onto the opposite (symmetric) 0805 pads — no rerouting needed.

### F4 — Two BOM part numbers no longer orderable at JLCPCB — HIGH (order blocker)
Both parts have live JLC *info pages* but are **absent from the active assembly-parts catalog**, which is exactly the "not-found" case you wanted to avoid:

| Ref(s) | Current | Problem | Replacement (drop-in) |
|---|---|---|---|
| conn-a R13/R14/R15 (100k 0805) | **C17407** | LCSC marks NRND; delisted at JLC | **C149504** — same UNI-ROYAL 0805W8F1003T5E, **Basic** library, ~1.78 M in stock |
| conn-b L1 (10 µH IHLP4040) | **C511353** (M5A) | delisted at JLC (all sibling variants present) | **C845066** — IHLP4040DZER100M**11**, same land pattern, Isat 7.1 A, ~3.4 k stock (alt: C845065 M01) |

### F5 — Solar input robustness (connector B) — decision needed
* **Reverse-panel: HIGH risk, no protection.** J2 is a screw terminal — field-reversible. A reversed panel puts −18 V on VIN/PANEL+: INA3221 IN pins (abs max −0.3 V) get damaged and the battery discharges through Q1's body diode until F1 trips (~6 A). Options: series Schottky **SS54** in the panel feed (≈0.3 V of 17.8 V ≈ 2% loss; retune R2 a notch if you care), a P-FET reverse blocker, or accept-and-label. Pick one consciously.
* **Panel TVS: MEDIUM.** Cold-morning Voc ≈ 24 V vs INA3221 26 V abs max = 2 V margin, and hot-plugging long leads into low-ESR ceramics rings above Voc. An **SMBJ24A** across PANEL+/GND is cheap insurance (BQ24650 itself is rated to 33 V).

---
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

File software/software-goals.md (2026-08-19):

Must haves:
1. OTA with A/B + health-gated auto-rollback. "Un-brickable".
2. Autonomous watchdog + power-cycle.
3. Power telemetry with trending and alerts.
4. Remote console / config passthrough(tunnel to the MeshCore CLI over a UART link). Centralized config management?
5. Continuous RF health stats + noisescope on demand(periodic noise floor samples, neighbor RSSI/SNR, packet/forward counts, airtime from normal MeshCore operation)

Should have:

6. Boot-loop detection + log/crash capture
7. Telemetry store-and-forward
8. LTE self-monitoring
9. Enclosure environment monitoring

Nice to have:

10. Remote promiscuous packet capture, maybe some sort of MQTT server

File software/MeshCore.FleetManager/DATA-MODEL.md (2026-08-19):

# FleetManager — Data model

The model is built around one central entity — the **Node** — with satellite
entities for the things that accrete over time (config backups, telemetry, RF
sweeps, firmware, events) and the things a node belongs to (sites, fleets).

Secrets are modelled **separately** from everything else and are the only
encrypted-at-rest, access-gated part of the store — see
[SECURITY.md](SECURITY.md). This separation is deliberate: the vast majority of
FleetManager data is ordinary operational data; only the key/password vault is
sensitive, and isolating it keeps the security surface small.

---

## 1. Entity overview

```
Site ──< Node >── Fleet(tag)
             │
             ├──< ConfigBackup >──(references)──> SecretBundle   [encrypted vault]
             ├──< TelemetrySample            (time-series)
             ├──< NoiseScopeSweep            (RF archive)
             ├──< FirmwareState / OtaCampaignRun
             ├──< NodeEvent                  (audit + lifecycle + control actions)
             └──  CapabilitySet              (embedded)

FirmwareImage (library, fleet-wide)
CrawlObservation (from NightCrawler, matched to Node)
```
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

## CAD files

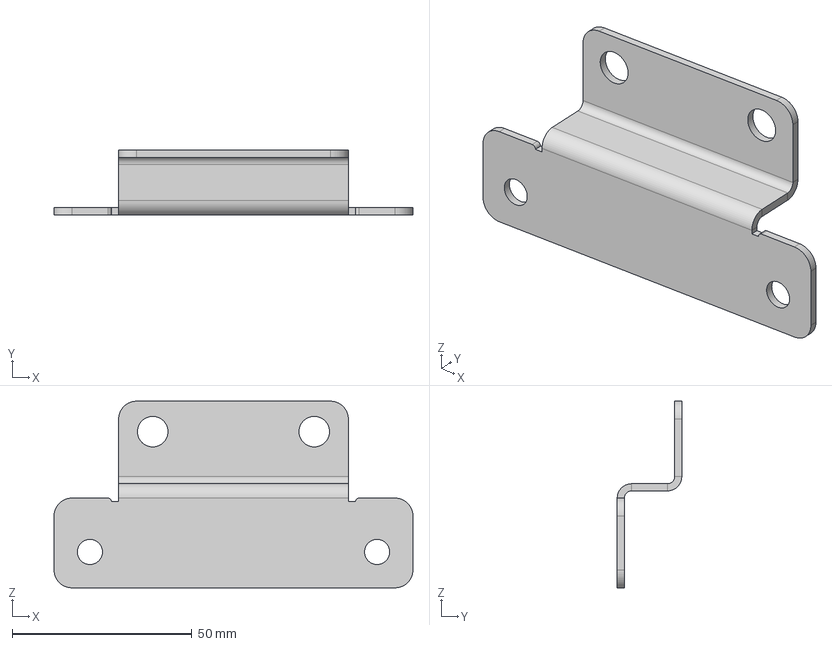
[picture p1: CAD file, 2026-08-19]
hardware/brackets/enclosure/Enclosure bracket.step
100.0 x 18.0 x 52.0 mm

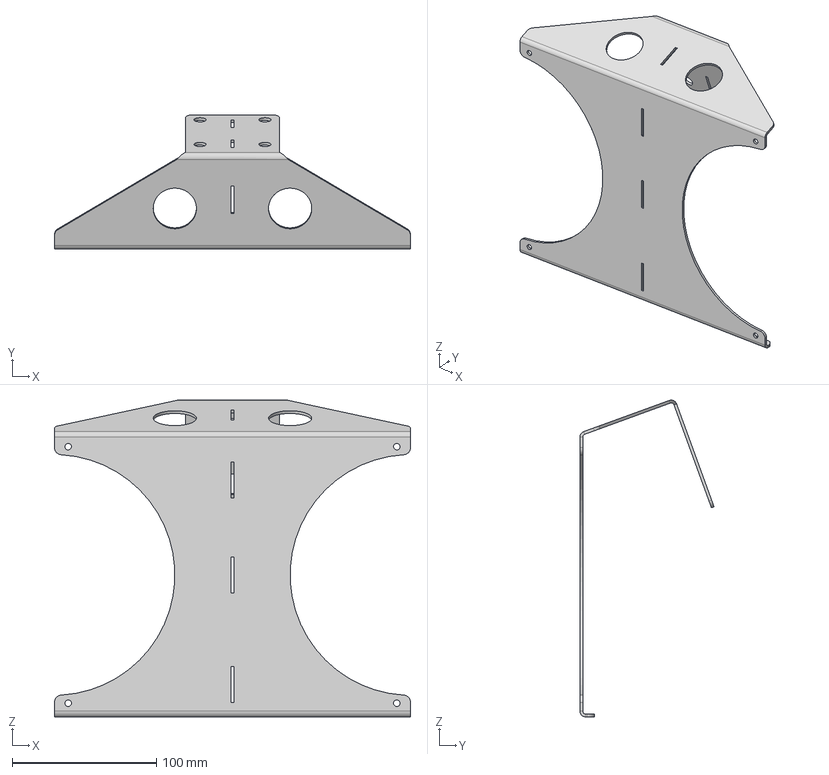
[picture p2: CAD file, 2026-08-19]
hardware/brackets/solarpanel/Solarpanel holder - Part A_V2.step
247.0 x 93.1 x 219.8 mm

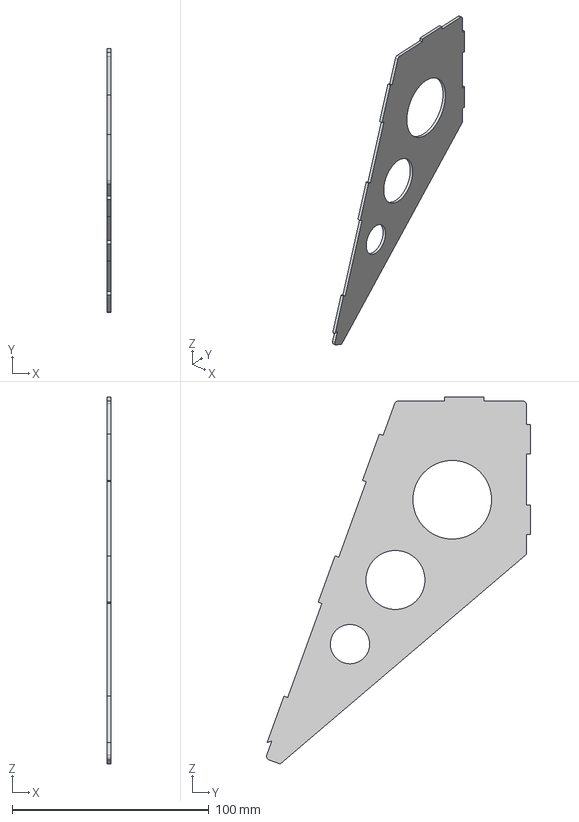
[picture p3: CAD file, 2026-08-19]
hardware/brackets/solarpanel/Solarpanel holder - Part B_V2.step
2.00 x 134.3 x 186.7 mm

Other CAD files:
hardware/brackets/enclosure/Enclosure bracket.dxf
hardware/brackets/solarpanel/Solarpanel holder - Part A_V2.dxf
hardware/brackets/solarpanel/Solarpanel holder - Part B_V2.dxf

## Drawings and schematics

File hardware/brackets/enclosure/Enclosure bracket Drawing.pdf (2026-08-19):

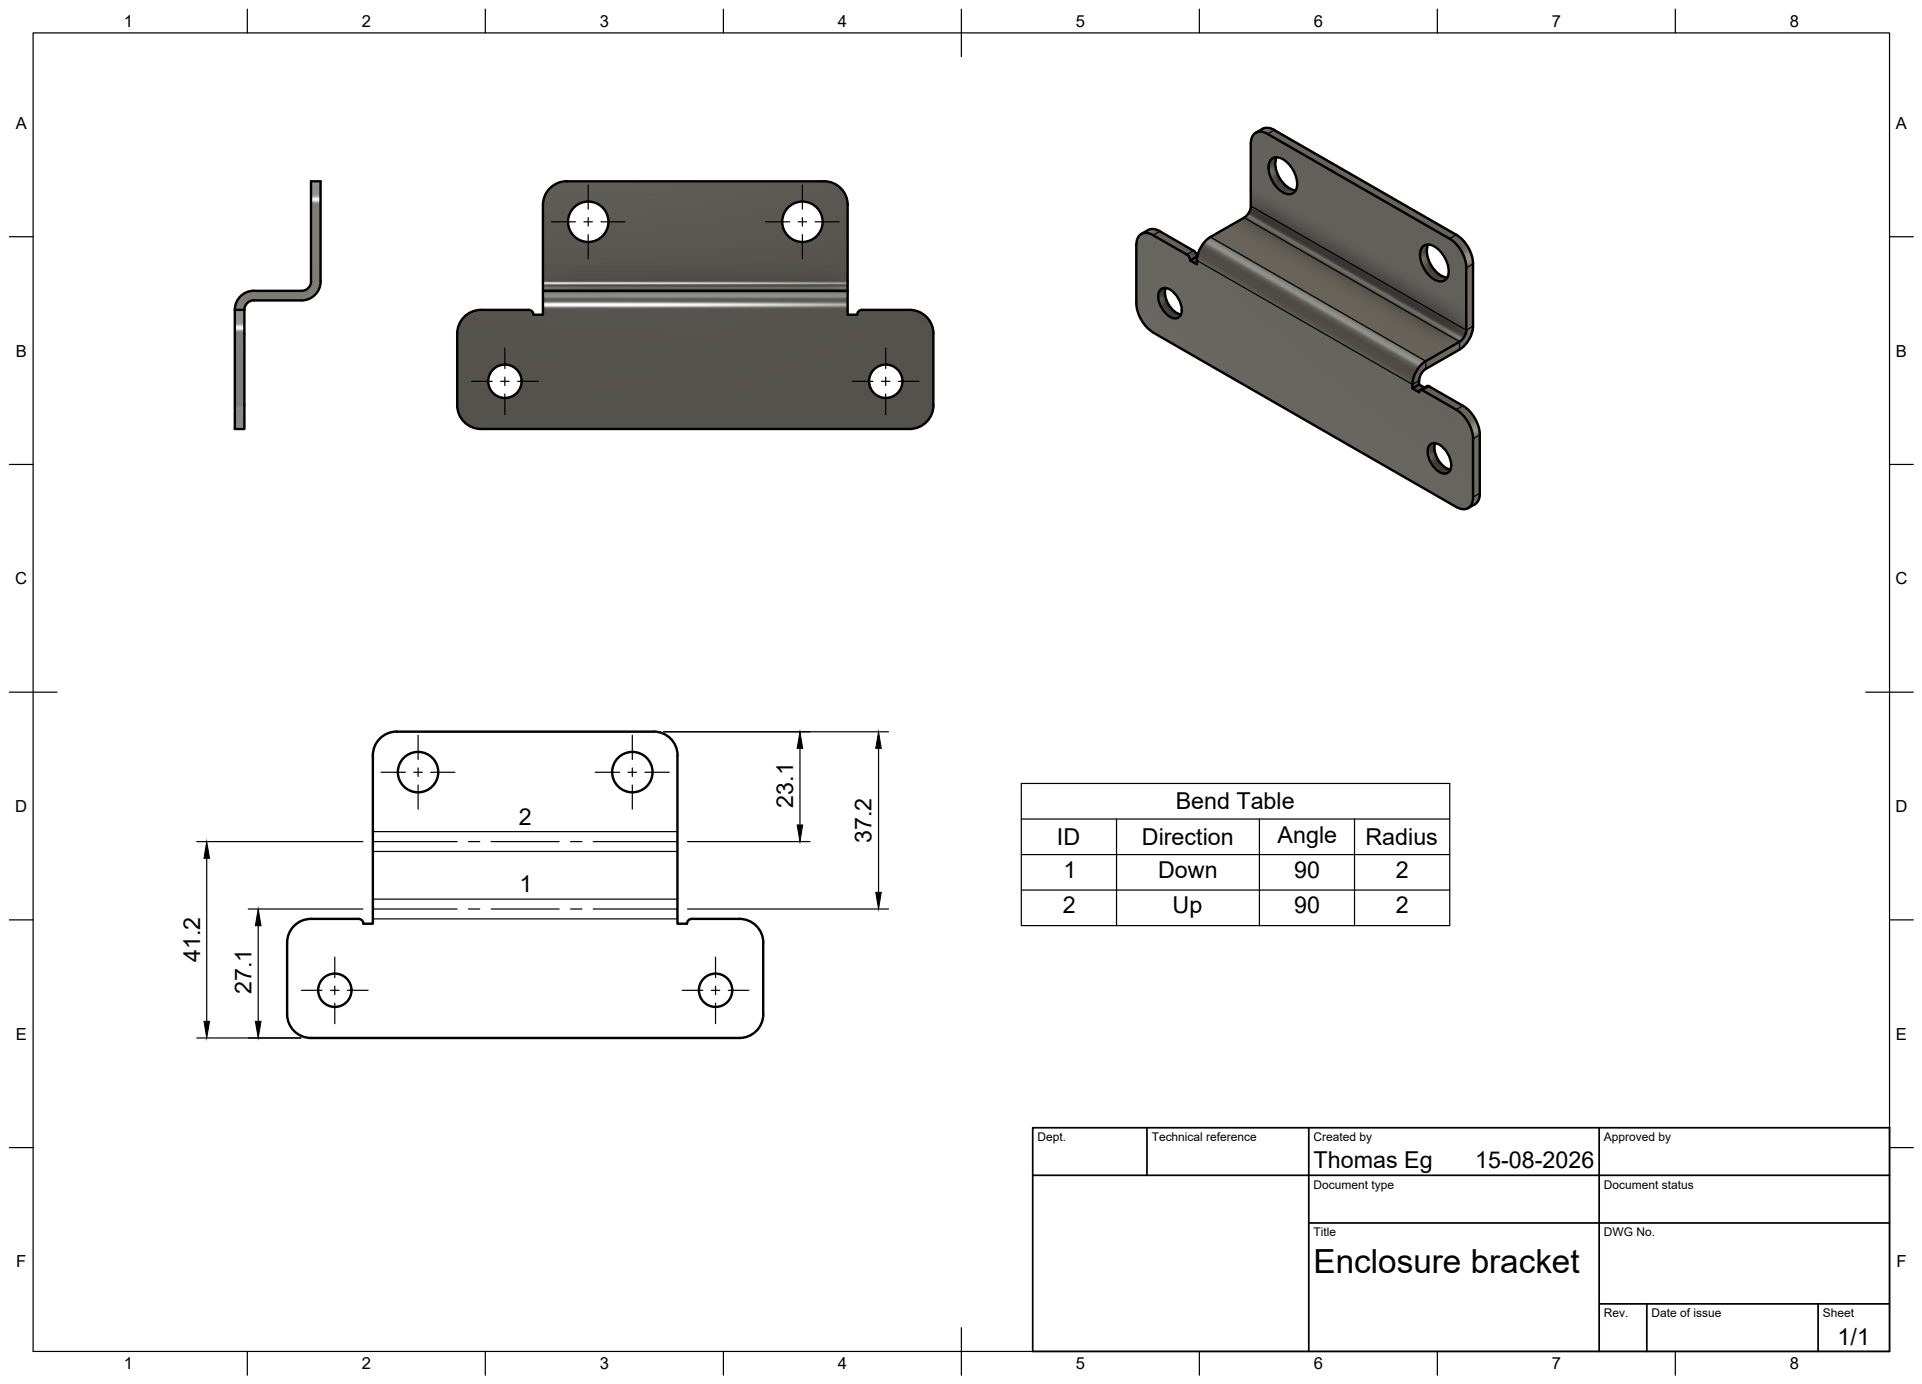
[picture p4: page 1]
Title; DWG No.; Rev.; Date of issue; Sheet; Enclosure bracket; Thomas Eg 27.141.2; Bend Table

Dept. | Technical reference | Created by 15-08-2026 | Approved by

Document type | Document status

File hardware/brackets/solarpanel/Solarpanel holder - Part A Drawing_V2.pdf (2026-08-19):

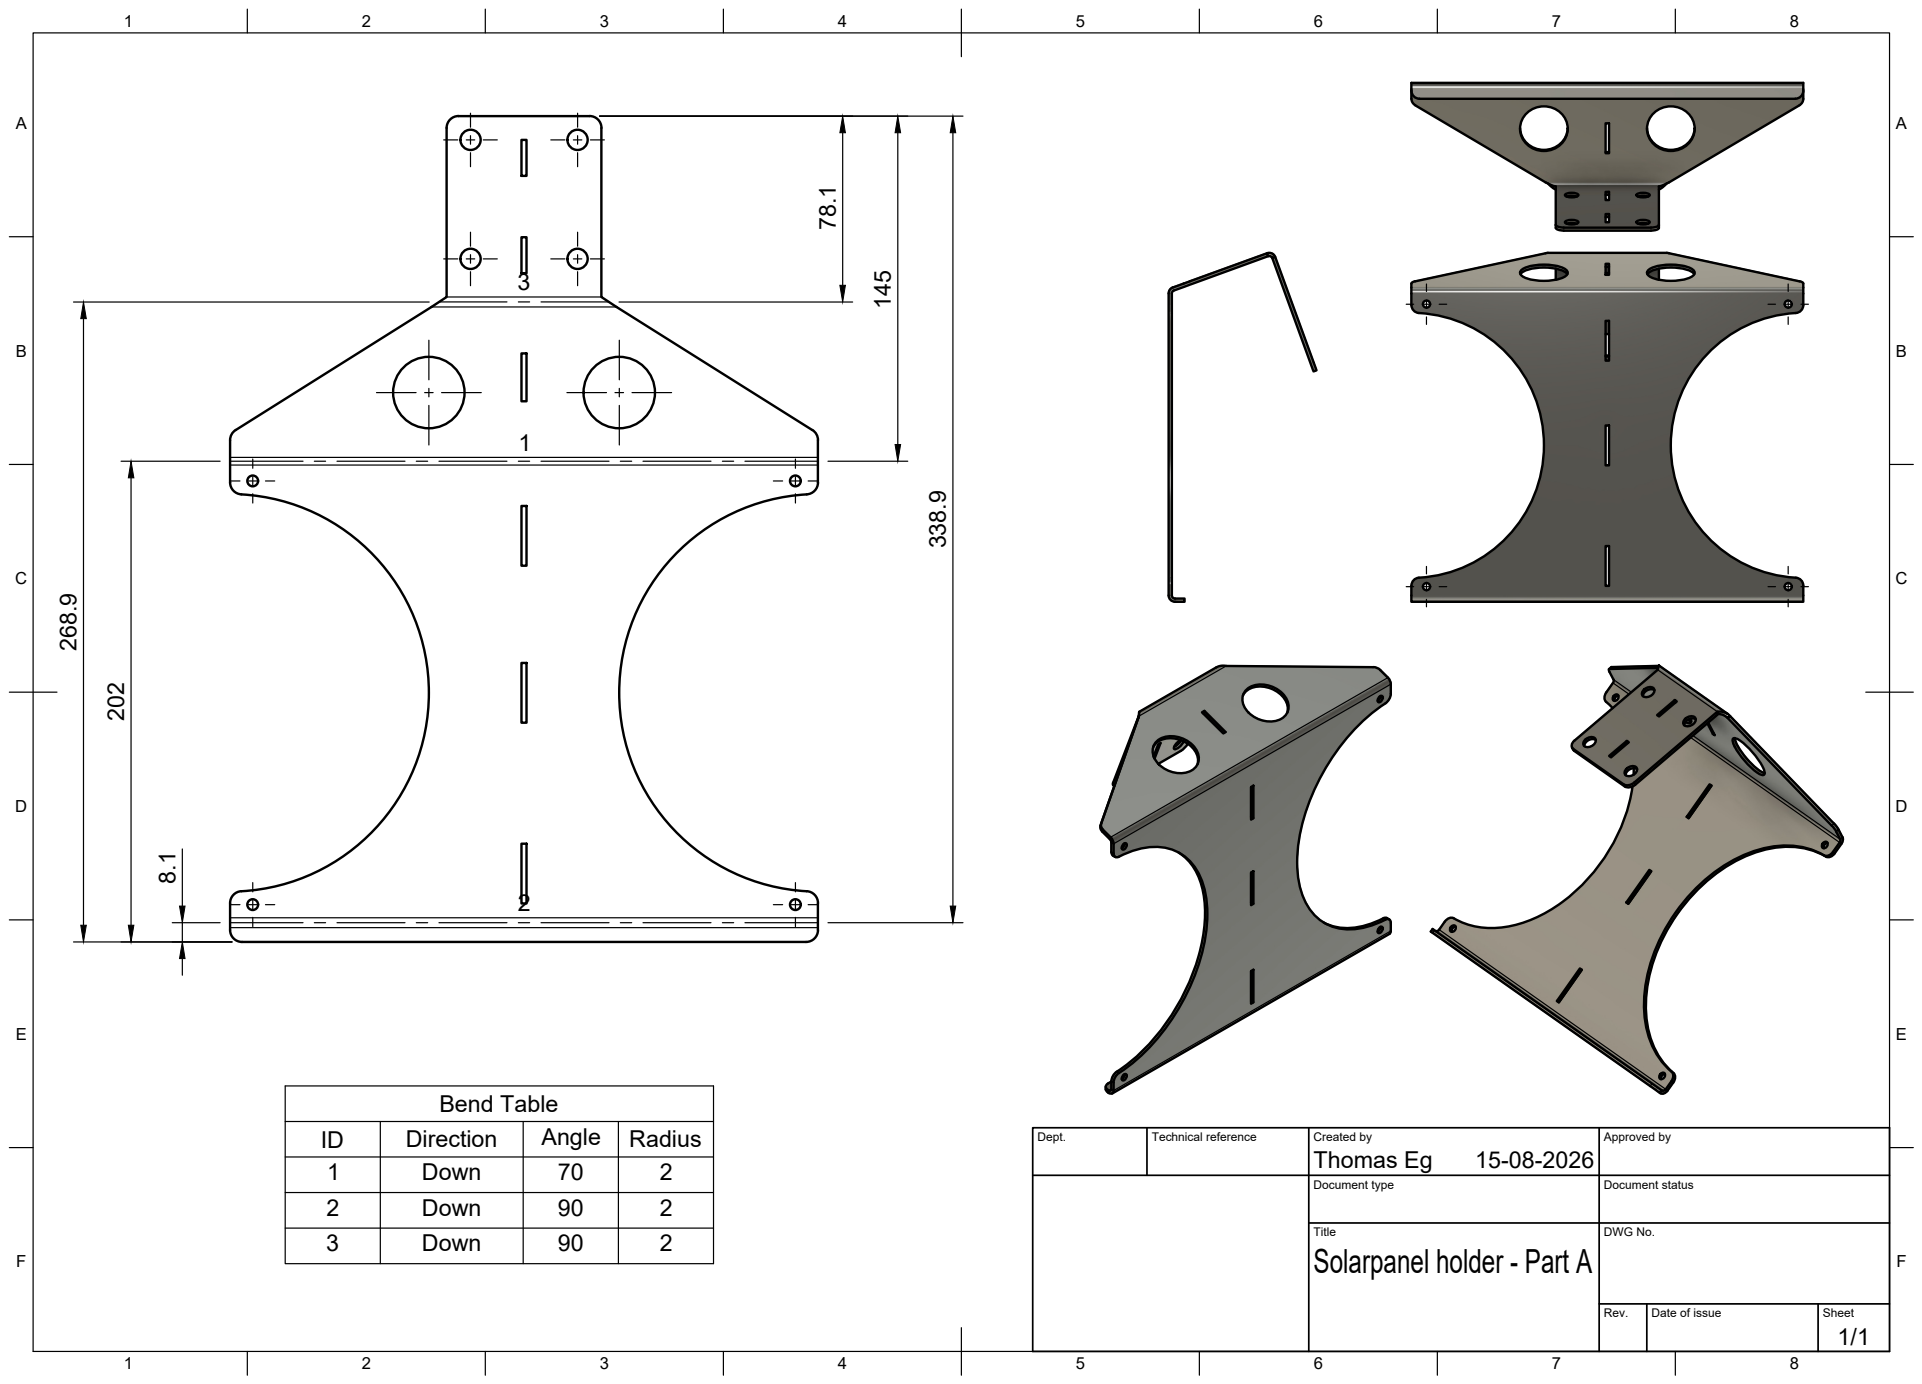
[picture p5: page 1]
Title; DWG No.; Rev.; Date of issue; Sheet; Bend Table

ID | Direction | Angle | Radius
1 | Down | 70 | 2
2 | Down | 90 | 2
3 | Down | 90 | 2

Dept. | Technical reference | Created by Thomas Eg 15-08-2026 | Approved by

Document type | Document status

Solarpanel holder - Part A

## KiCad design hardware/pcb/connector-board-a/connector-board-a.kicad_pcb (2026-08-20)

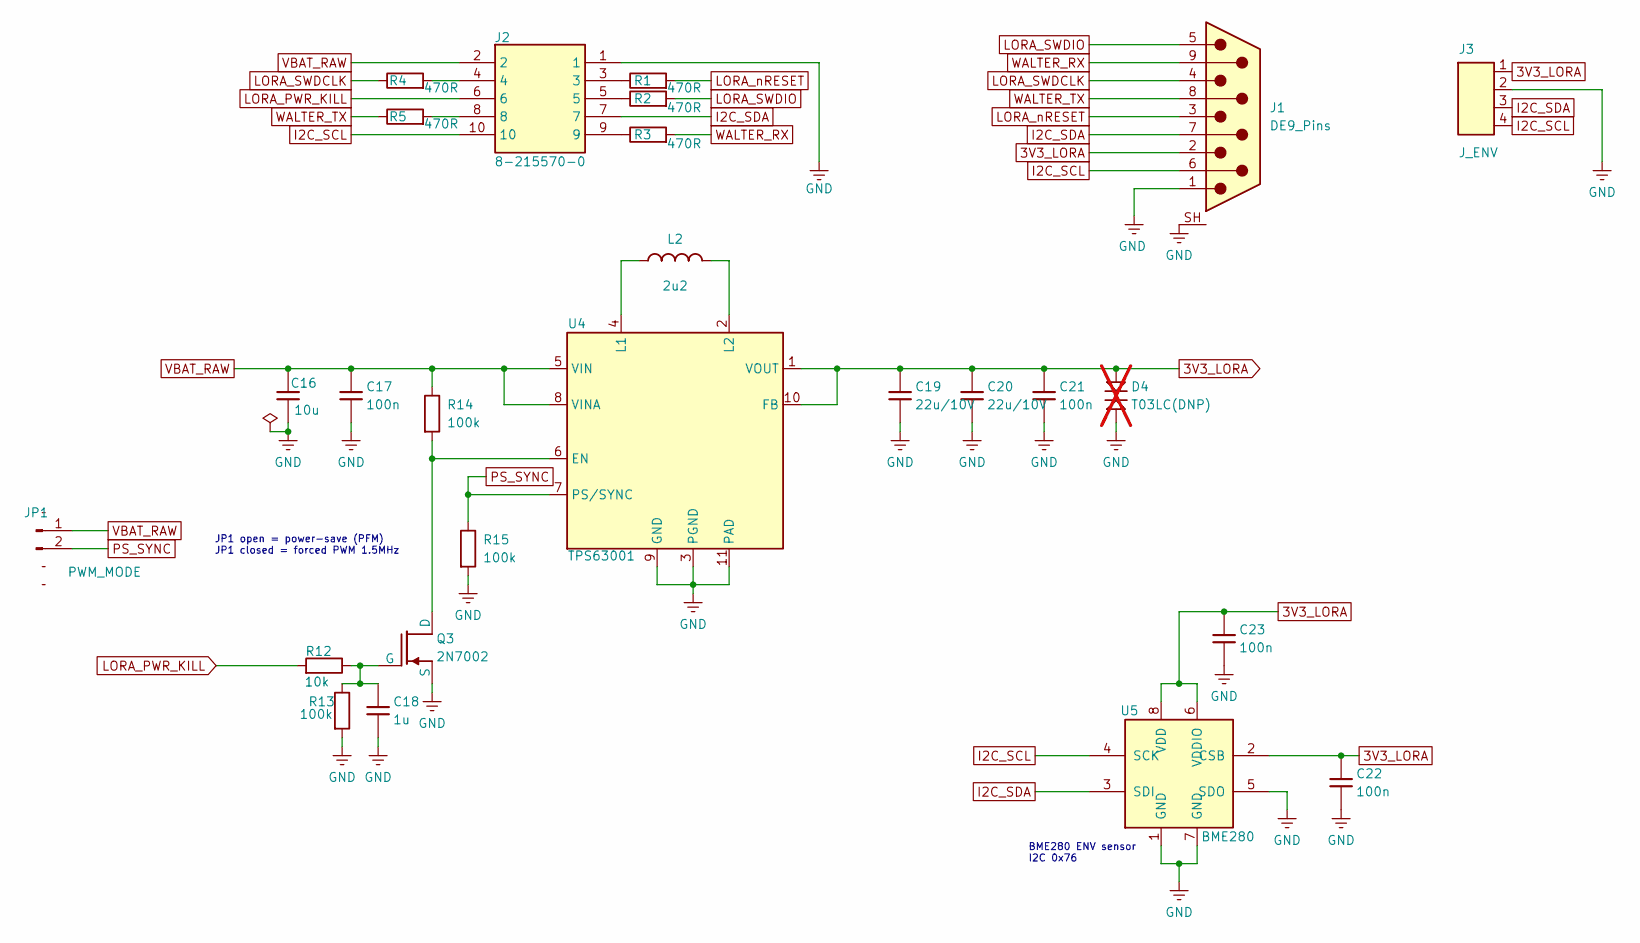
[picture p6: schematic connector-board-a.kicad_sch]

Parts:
C16: 10u; C_0805_2012Metric; LCSC Part # C15850
C17, C21, C22, C23: 100n; C_0603_1608Metric; LCSC Part # C14663
C18: 1u; C_0603_1608Metric; LCSC Part # C15849
C19, C20: 22u/10V; C_0805_2012Metric; LCSC Part # C45783
D4: T03LC(DNP); D_SOD-323; not fitted
J1: DE9_Pins; DSUB-9_Pins_Vertical_P2.77x2.84mm_MountingHoles
J2: 8-215570-0; 82155700; Manufacturer_Part_Number 8-215570-0
J3: J_ENV; PinHeader_1x04_P2.54mm_Vertical
JP1: PWM_MODE; PinHeader_1x02_P2.54mm_Vertical
L2: 2u2; L_Coilcraft_LPS4018; LCSC Part # C4354938
Q3: 2N7002; SOT-23; LCSC Part # C8545
R1, R2, R3, R4, R5: 470R; R_0805_2012Metric; LCSC Part # C17710
R12: 10k; R_0805_2012Metric; LCSC Part # C17414
R13, R14, R15: 100k; R_0805_2012Metric; LCSC Part # C149504
U4: TPS63001; Texas_DRC0010J; LCSC Part # C28060
U5: BME280; Bosch_LGA-8_2.5x2.5mm_P0.65mm_ClockwisePinNumbering; LCSC Part # C92489

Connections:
3V3_LORA: C19.1, C20.1, C21.1, C22.1, C23.1, D4.1, J1.2, J3.1, U4.1 (VOUT), U4.10 (FB), U5.2 (CSB), U5.6 (VDDIO), U5.8 (VDD)
GND: C16.2, C17.2, C18.2, C19.2, C20.2, C21.2, C22.2, C23.2, D4.2, J1.1, J1.SH, J2.1, J3.2, Q3.2 (S), R13.2, R15.2, U4.3 (PGND), U4.9 (GND), U4.11 (PAD), U5.1 (GND), U5.5 (SDO), U5.7 (GND)
I2C_SCL: J1.6, J2.10, J3.4, U5.4 (SCK)
I2C_SDA: J1.7, J2.7, J3.3, U5.3 (SDI)
LORA_PWR_KILL: J2.6, R12.1
LORA_SWDCLK: J1.4, R4.1
LORA_SWDIO: J1.5, R2.2
LORA_nRESET: J1.3, R1.2
unnamed: J2.3, R1.1
unnamed: J2.4, R4.2
unnamed: J2.5, R2.1
unnamed: J2.8, R5.2
unnamed: J2.9, R3.1
unnamed: Q3.3 (D), R14.2, U4.6 (EN)
unnamed: C18.1, Q3.1 (G), R12.2, R13.1
unnamed: L2.1, U4.4 (L1)
unnamed: L2.2, U4.2 (L2)
PS_SYNC: JP1.2, R15.1, U4.7 (PS/SYNC)
VBAT_RAW: C16.1, C17.1, J2.2, JP1.1, R14.1, U4.5 (VIN), U4.8 (VINA)
WALTER_RX: J1.9, R3.2
WALTER_TX: J1.8, R5.1

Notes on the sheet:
BME280 ENV sensor I2C 0x76
JP1 open = power-save (PFM) JP1 closed = forced PWM 1.5MHz

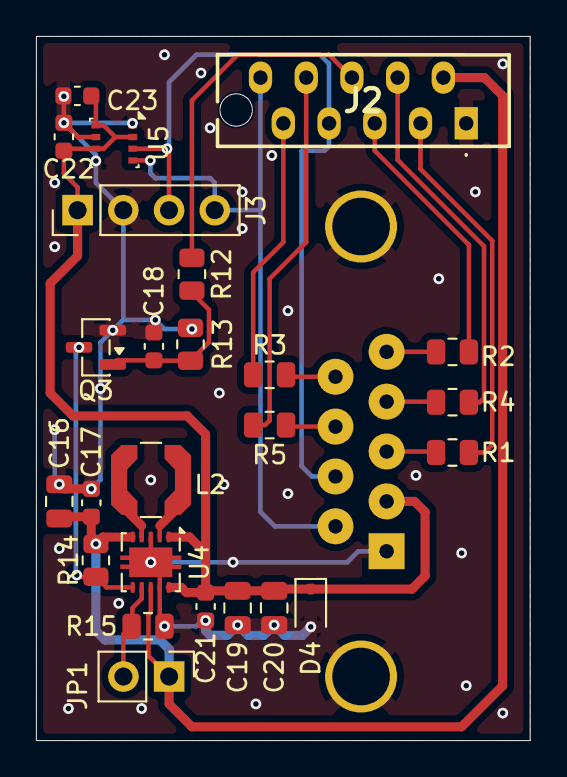
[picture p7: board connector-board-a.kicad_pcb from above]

Board: 2 copper layers, 27.4 x 39.1 mm, 26 parts (1 on the bottom side), 21 nets.

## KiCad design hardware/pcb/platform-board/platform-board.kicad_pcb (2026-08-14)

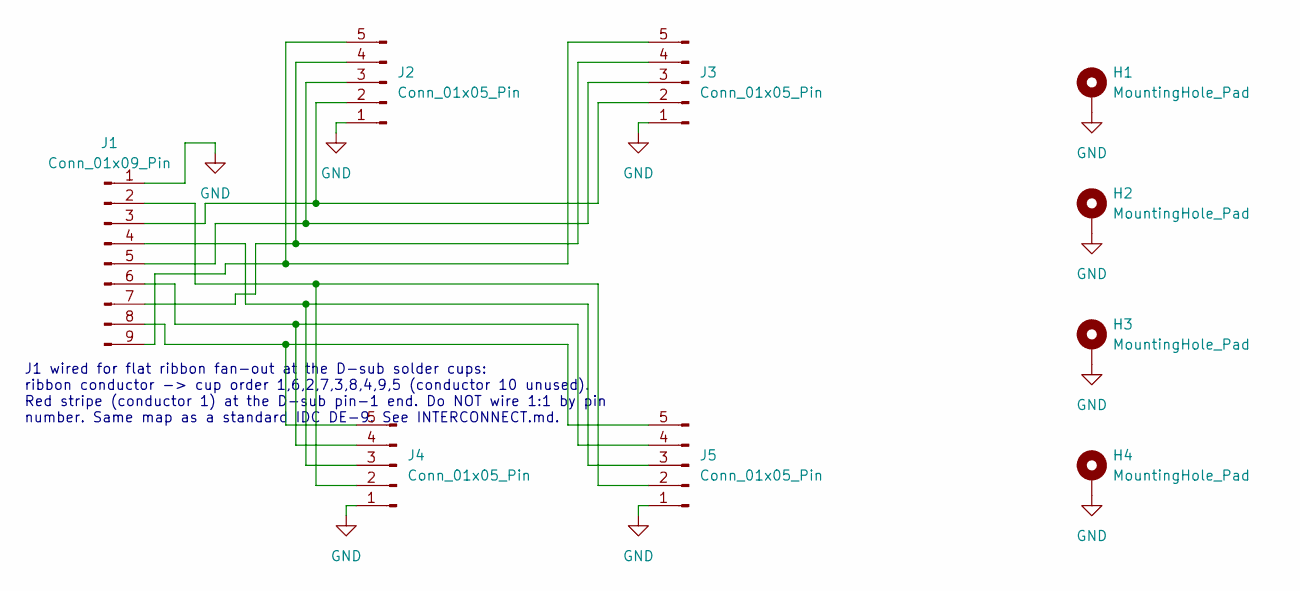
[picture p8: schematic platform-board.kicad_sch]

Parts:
H1, H2, H3, H4: MountingHole_Pad; MountingHole_3.5mm_Pad
J1: Conn_01x09_Pin; 82155700
J2, J3, J4, J5: Conn_01x05_Pin; PinHeader_1x05_P2.54mm_Vertical

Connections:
GND: H1.1 (1_1), H2.1 (1_1), H3.1 (1_1), H4.1 (1_1), J1.1, J2.1, J3.1, J4.1, J5.1
unnamed: J1.2, J4.2, J5.2
unnamed: J1.3, J2.2, J3.2
unnamed: J1.4, J4.3, J5.3
unnamed: J1.5, J2.3, J3.3
unnamed: J1.6, J4.4, J5.4
unnamed: J1.7, J2.4, J3.4
unnamed: J1.8, J4.5, J5.5
unnamed: J1.9, J2.5, J3.5

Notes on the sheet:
J1 wired for flat ribbon fan-out at the D-sub solder cups: ribbon conductor -> cup order 1,6,2,7,3,8,4,9,5 (conductor 10 unused). Red stripe (conductor 1) at the D-sub pin-1 end. Do NOT wire 1:1 by pin number. Same map as a standard IDC DE-9. See INTERCONNECT.md.

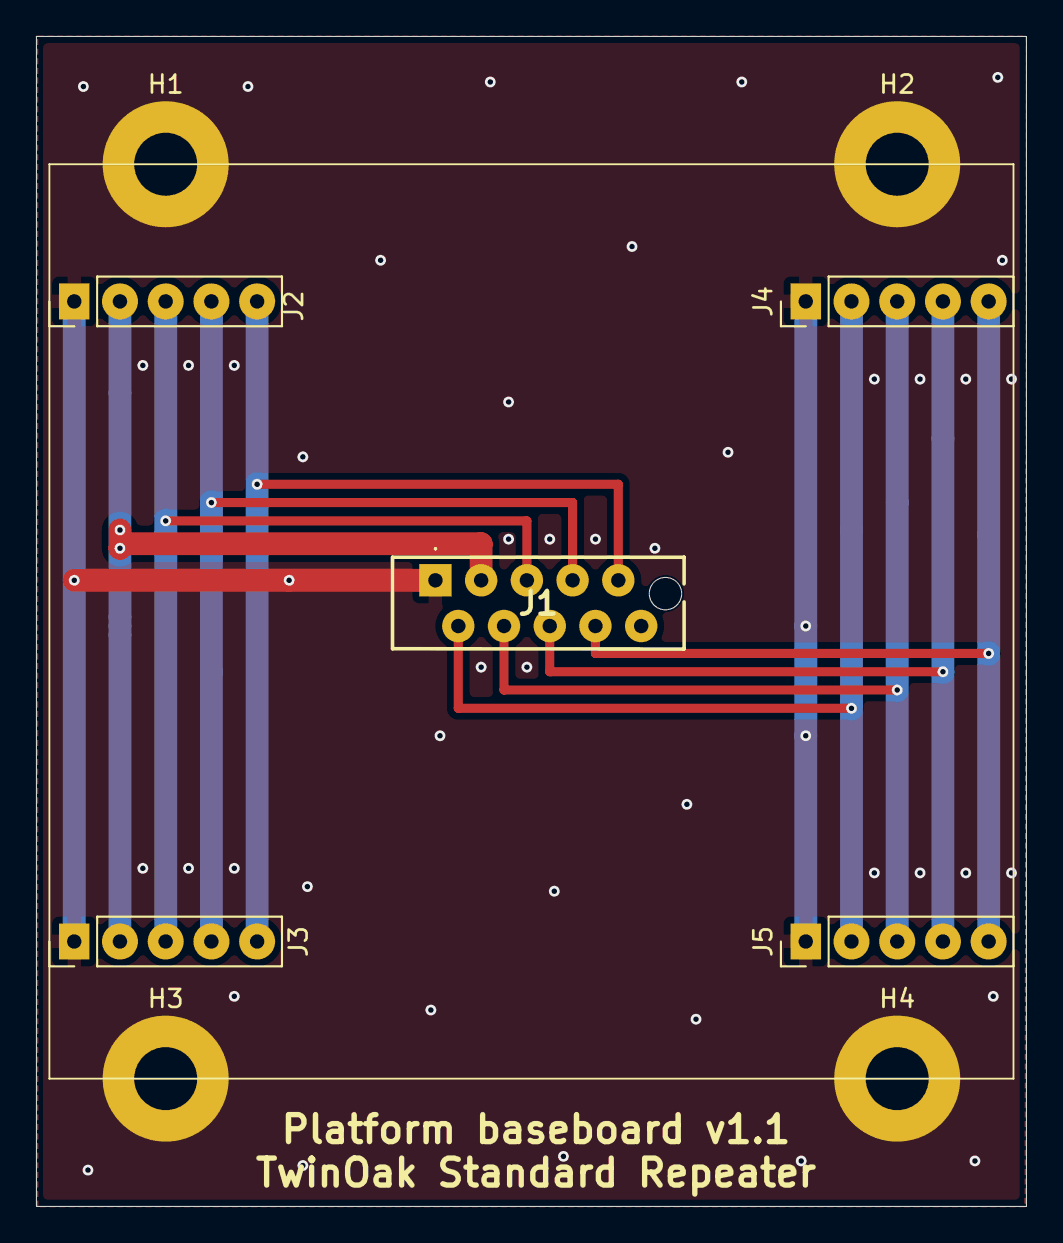
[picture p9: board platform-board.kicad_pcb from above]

Board: 2 copper layers, 55.0 x 65.0 mm, 9 parts (0 on the bottom side), 9 nets.

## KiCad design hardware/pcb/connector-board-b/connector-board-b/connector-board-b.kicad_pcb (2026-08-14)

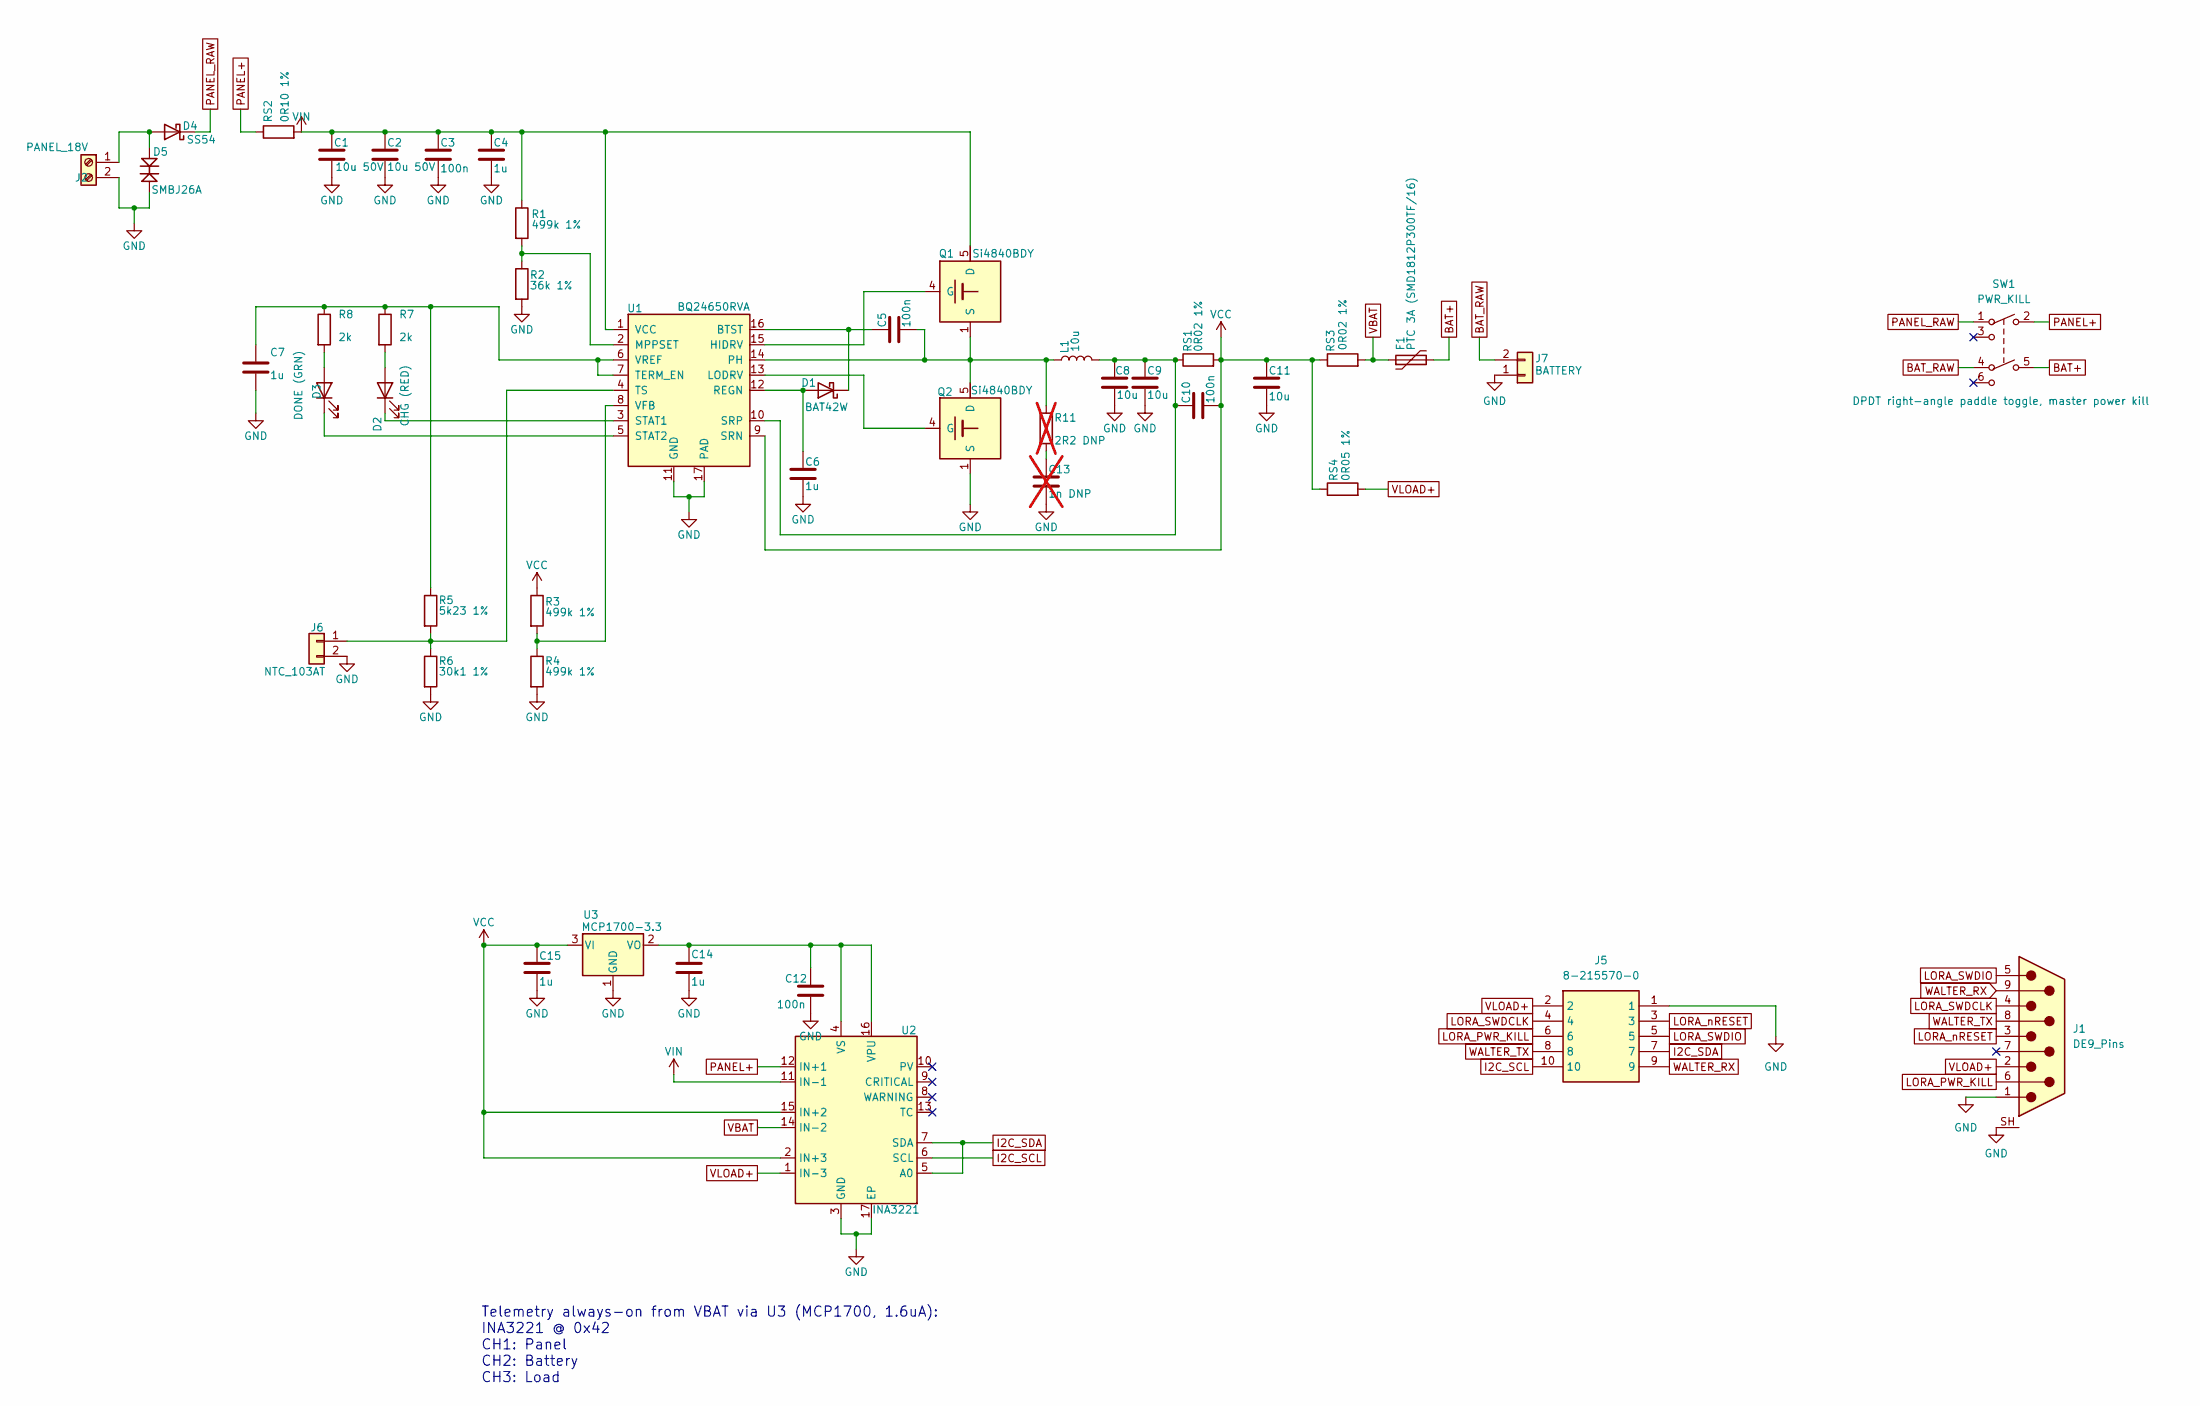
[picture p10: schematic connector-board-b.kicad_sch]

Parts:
C1, C2: 10u 50V; C_1210_3225Metric; LCSC Part # C138687
C3, C5, C10, C12: 100n; C_0805_2012Metric; LCSC Part # C49678
C4, C6, C7, C14, C15: 1u; C_0805_2012Metric; LCSC Part # C28323
C8, C9, C11: 10u; C_1206_3216Metric; LCSC Part # C13585
C13: 1n DNP; C_0805_2012Metric; LCSC Part # C94121; not fitted
D1: BAT42W; D_SOD-123; LCSC Part # C134396
D2: CHG (RED); LED_0805_2012Metric; LCSC Part # C84256
D3: DONE (GRN); LED_0805_2012Metric; LCSC Part # C2297
D4: SS54; D_SMA; LCSC Part # C22452
D5: SMBJ26A; D_SMB; LCSC Part # C123820
F1: PTC 3A (SMD1812P300TF/16); Fuse_1812_4532Metric; LCSC Part # C702820
J1: DE9_Pins; DSUB-9_Pins_Vertical_P2.77x2.84mm_MountingHoles
J2: PANEL_18V; TerminalBlock_MaiXu_MX126-5.0-02P_1x02_P5.00mm; LCSC Part # C5188434
J5: 8-215570-0; 82155700; Manufacturer_Part_Number 8-215570-0
J6: NTC_103AT; JST_PH_B2B-PH-K_1x02_P2.00mm_Vertical; LCSC Part # C131337
J7: BATTERY; JST_EH_B2B-EH-A_1x02_P2.50mm_Vertical; LCSC Part # C160262
L1: 10u; L_Vishay_IHLP-4040; LCSC Part # C845066
Q1, Q2: Si4840BDY; SOIC-8_3.9x4.9mm_P1.27mm; LCSC Part # C558269
R1, R3, R4: 499k 1%; R_0805_2012Metric; LCSC Part # C17721
R2: 36k 1%; R_0805_2012Metric; LCSC Part # C4360
R5: 5k23 1%; R_0805_2012Metric; LCSC Part # C17739
R6: 30k1 1%; R_0805_2012Metric; LCSC Part # C21841
R7, R8: 2k; R_0805_2012Metric; LCSC Part # C17604
R11: 2R2 DNP; R_0805_2012Metric; not fitted
RS1, RS3: 0R02 1%; R_1206_3216Metric; LCSC Part # C2903502
RS2: 0R10 1%; R_1206_3216Metric; LCSC Part # C25334
RS4: 0R05 1%; R_1206_3216Metric; LCSC Part # C2904224
SW1: PWR_KILL; SW_Toggle_CAX_MTS202C3D1_RightAngle; LCSC Part # C55159901
U1: BQ24650RVA; Texas_RVA0016A_VQFN-16-1EP_3.5x3.5mm_P0.5mm_EP2.1x2.1mm; LCSC Part # C53712
U2: INA3221; Texas_RGV0016A_VQFN-16-1EP_4x4mm_P0.65mm_EP2.1x2.1mm; LCSC Part # C181255
U3: MCP1700-3.3; SOT-23; LCSC Part # C39051

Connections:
BAT+: F1.2, SW1.5 (COM2)
BAT_RAW: J7.2, SW1.4 (A2)
GND: C1.2, C2.2, C3.2, C4.2, C6.2, C7.2, C8.2, C9.2, C11.2, C12.2, C13.2, C14.2, C15.2, D5.2, J1.1 (1_1), J1.SH, J2.2, J5.1, J6.2, J7.1, Q2.1 (S), Q2.2 (S), Q2.3 (S), R2.2, R4.2, R6.2, U1.11 (GND), U1.17 (PAD), U2.3 (GND), U2.17 (EP), U3.1 (GND)
I2C_SCL: J5.10, U2.6 (SCL)
I2C_SDA: J5.7, U2.5 (A0), U2.7 (SDA)
LORA_PWR_KILL: J1.6 (6_6), J5.6
LORA_SWDCLK: J1.4 (4_4), J5.4
LORA_SWDIO: J1.5 (5_5), J5.5
LORA_nRESET: J1.3 (3_3), J5.3
unnamed: C13.1, R11.2
unnamed: C6.1, D1.2 (A), U1.12 (REGN)
unnamed: C5.1, D1.1 (K), U1.16 (BTST)
unnamed: D2.2 (A), R7.2
unnamed: D2.1 (K), U1.3 (STAT1)
unnamed: D3.2 (A), R8.2
unnamed: D3.1 (K), U1.5 (STAT2)
unnamed: D4.2 (A), D5.1, J2.1
unnamed: J6.1, R5.2, R6.1, U1.4 (TS)
unnamed: Q1.4 (G), U1.15 (HIDRV)
unnamed: Q2.4 (G), U1.13 (LODRV)
unnamed: R1.2, R2.1, U1.2 (MPPSET)
unnamed: C5.2, L1.1, Q1.1 (S), Q1.2 (S), Q1.3 (S), Q2.5 (D), Q2.6 (D), Q2.7 (D), Q2.8 (D), R11.1, U1.14 (PH)
unnamed: C8.1, C9.1, C10.1, L1.2, RS1.1, U1.10 (SRP)
unnamed: C7.1, R5.1, R7.1, R8.1, U1.6 (VREF), U1.7 (TERM_EN)
unnamed: R3.2, R4.1, U1.8 (VFB)
unnamed: C12.1, C14.1, U2.4 (VS), U2.16 (VPU), U3.2 (VO)
PANEL+: RS2.1, SW1.2 (COM1), U2.12 (IN+1)
PANEL_RAW: D4.1 (K), SW1.1 (A1)
VBAT: F1.1, RS3.2, U2.14 (IN-2)
VCC: C10.2, C11.1, C15.1, R3.1, RS1.2, RS3.1, RS4.1, U1.9 (SRN), U2.2 (IN+3), U2.15 (IN+2), U3.3 (VI)
VIN: C1.1, C2.1, C3.1, C4.1, Q1.5 (D), Q1.6 (D), Q1.7 (D), Q1.8 (D), R1.1, RS2.2, U1.1 (VCC), U2.11 (IN-1)
VLOAD+: J1.2 (2_2), J5.2, RS4.2, U2.1 (IN-3)
WALTER_RX: J1.9 (9_9), J5.9
WALTER_TX: J1.8 (8_8), J5.8

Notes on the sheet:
Telemetry always-on from VBAT via U3 (MCP1700, 1.6uA): INA3221 @ 0x42 CH1: Panel CH2: Battery CH3: Load

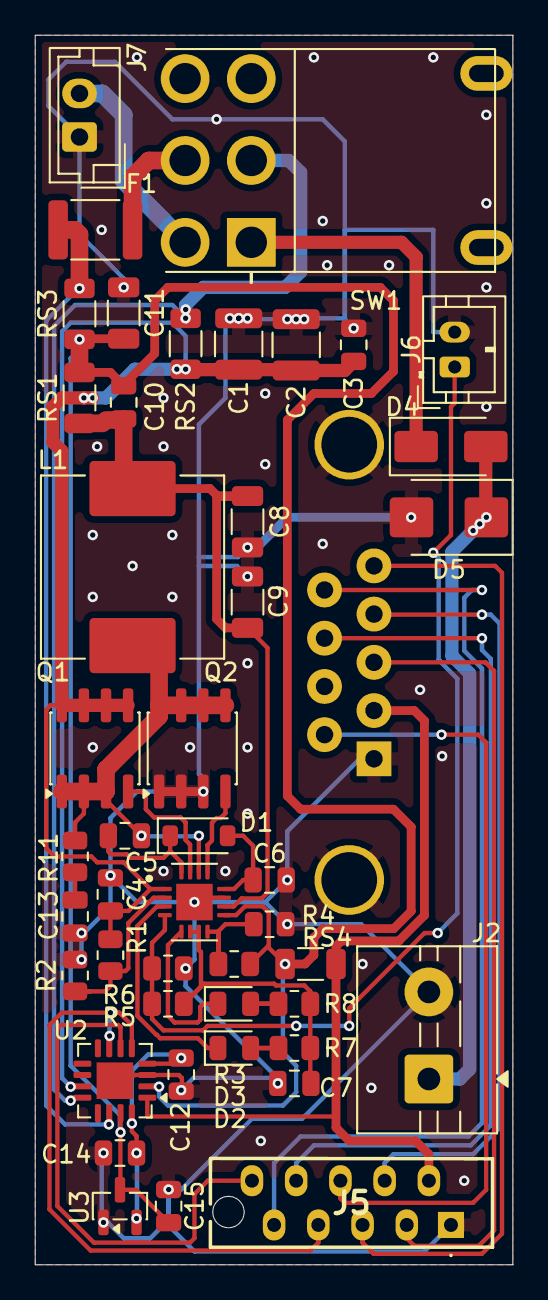
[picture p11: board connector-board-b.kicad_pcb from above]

Board: 2 copper layers, 27.4 x 70.6 mm, 46 parts (1 on the bottom side), 34 nets.

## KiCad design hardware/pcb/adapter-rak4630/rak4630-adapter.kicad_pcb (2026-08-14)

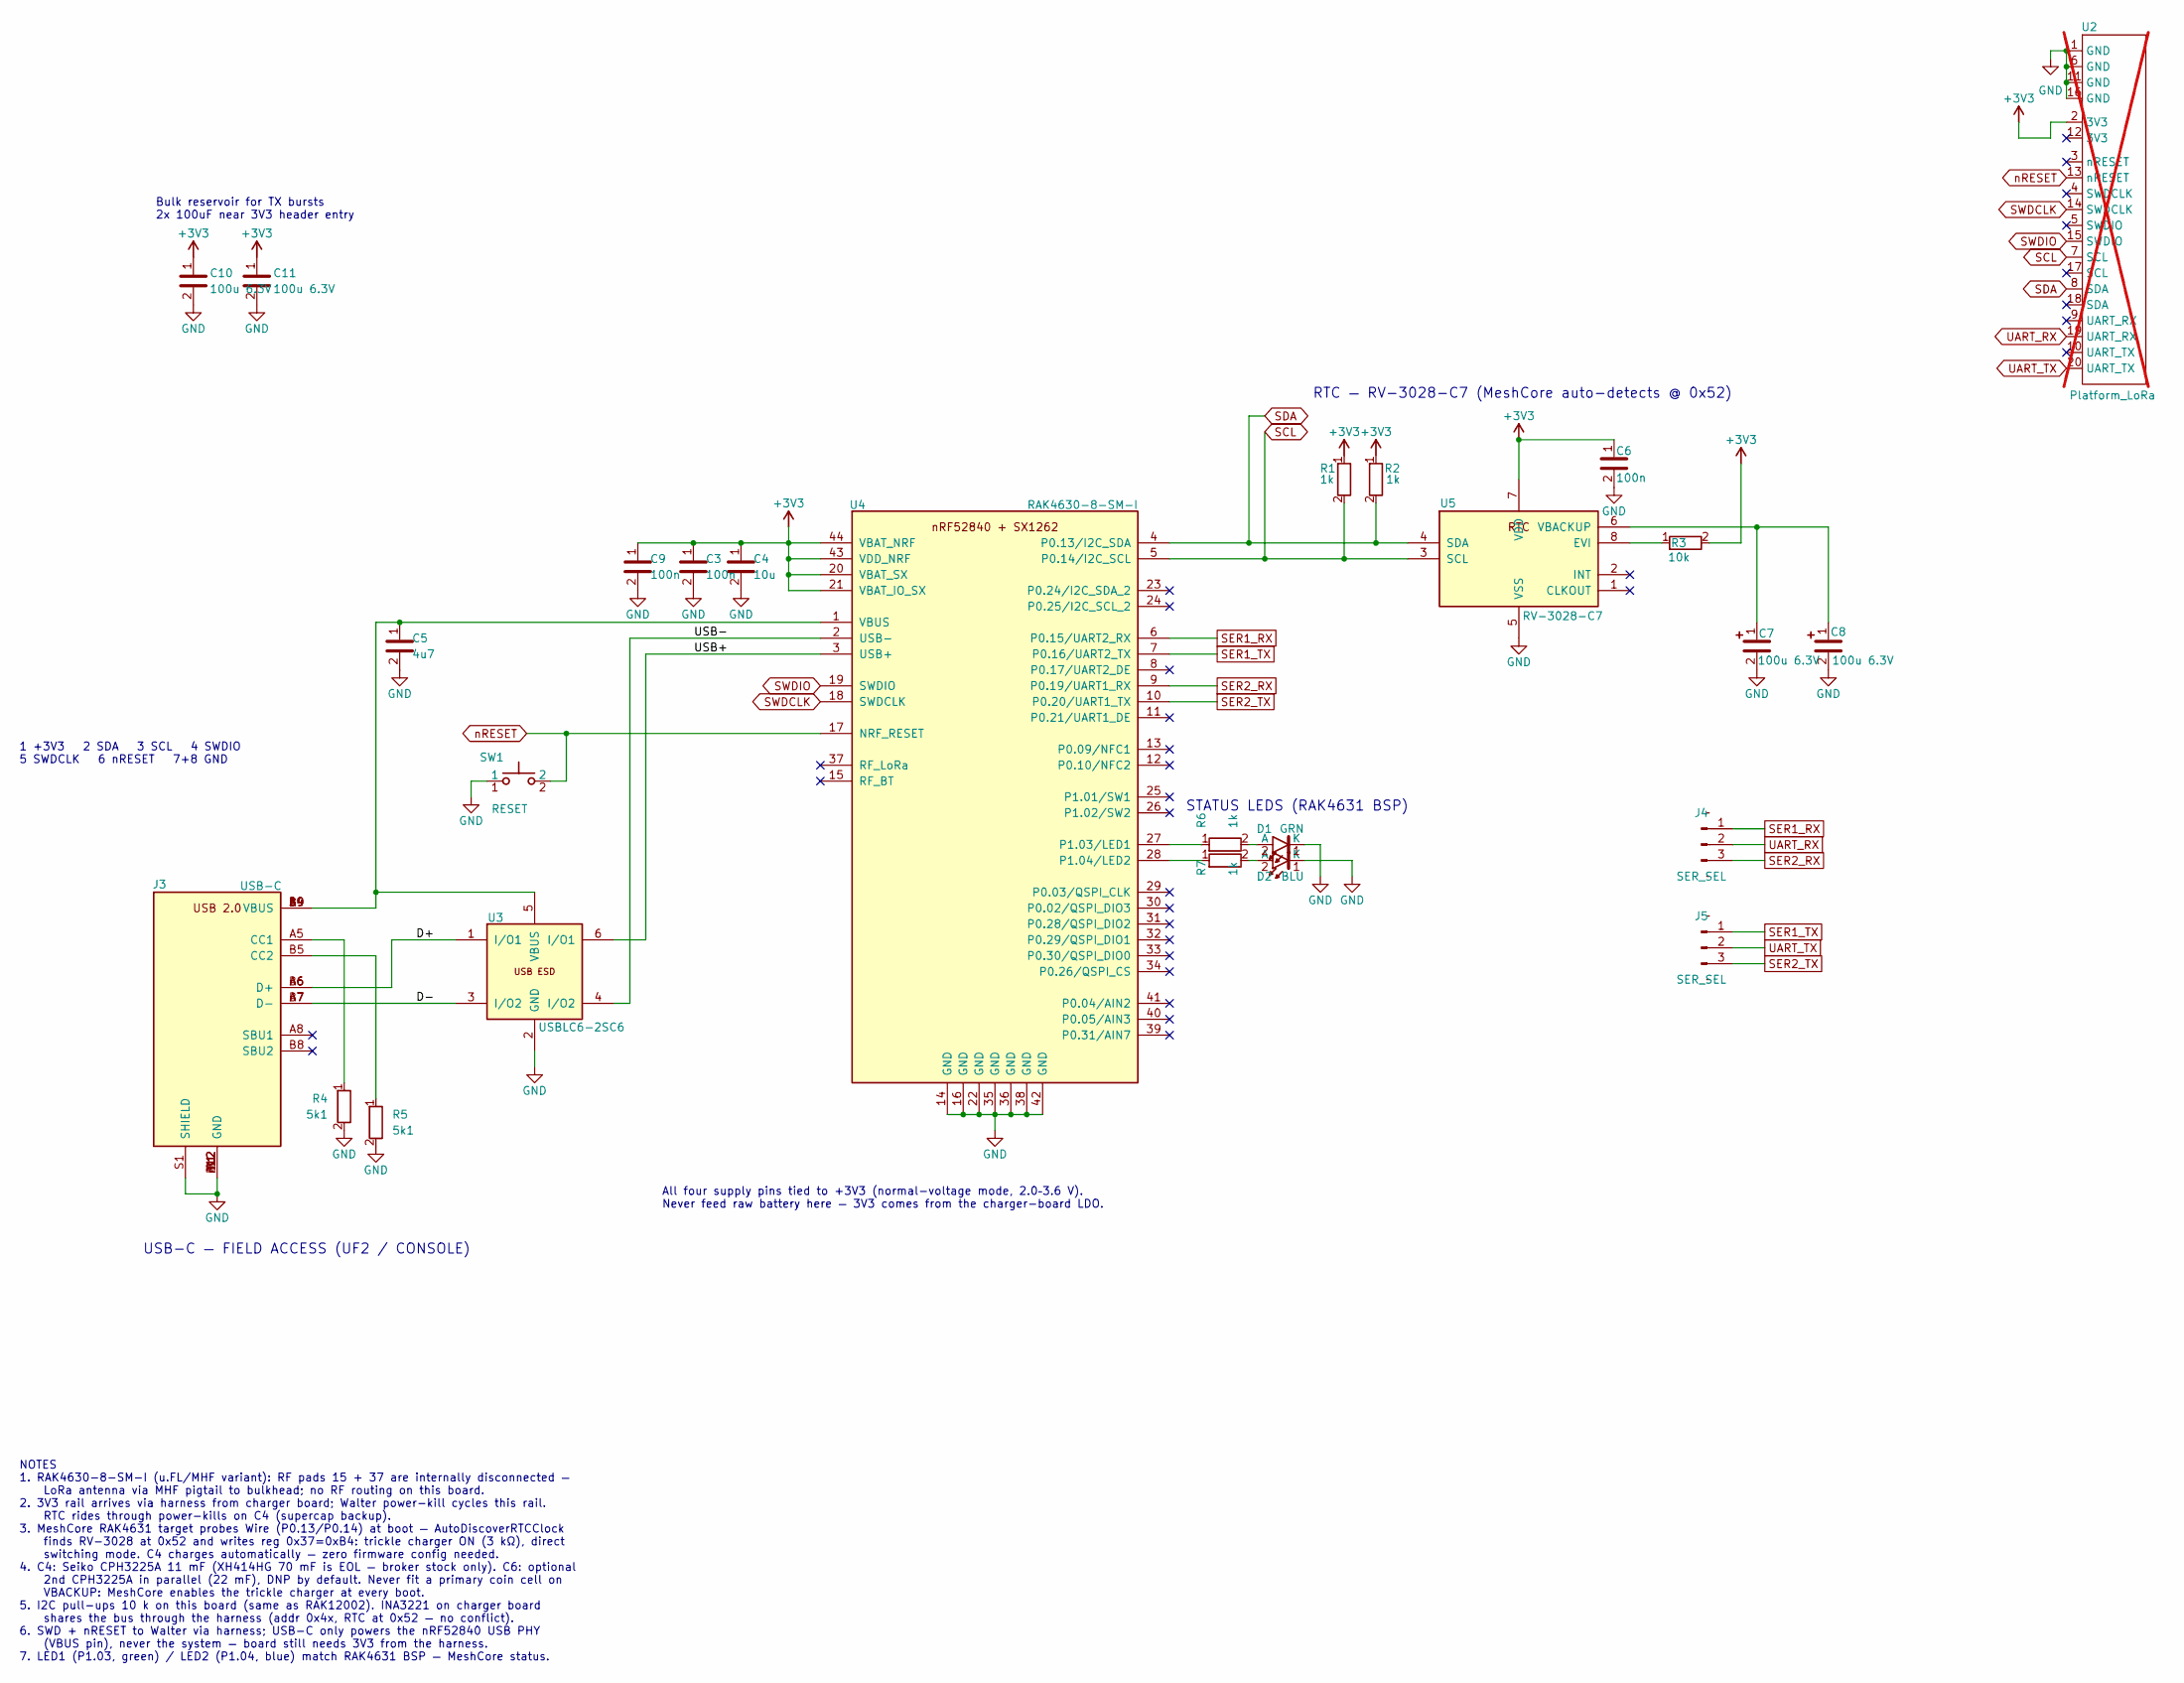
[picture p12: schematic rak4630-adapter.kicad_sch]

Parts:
C3, C6, C9: 100n; C_0805_2012Metric_Pad1.18x1.45mm_HandSolder; LCSC Part # C49678
C4: 10u; C_0805_2012Metric_Pad1.18x1.45mm_HandSolder; LCSC Part # C15850
C5: 4u7; C_0805_2012Metric_Pad1.18x1.45mm_HandSolder; LCSC Part # C1779
C7, C8, C10, C11: 100u 6.3V; CPH3225A; LCSC Part # C49066
D1: GRN; LED_0805_2012Metric; LCSC Part # C2297
D2: BLU; LED_0805_2012Metric; LCSC Part # C2293
J3: USB-C; USB_C_Receptacle_XUNPU_TYPEC-303-ACP16_Vertical; LCSC Part # C720628
J4, J5: SER_SEL; PinHeader_1x03_P2.54mm_Vertical
R1, R2, R6, R7: 1k; R_0805_2012Metric_Pad1.20x1.40mm_HandSolder; LCSC Part # C17513
R3: 10k; R_0805_2012Metric_Pad1.20x1.40mm_HandSolder; LCSC Part # C17414
R4, R5: 5k1; R_0805_2012Metric_Pad1.20x1.40mm_HandSolder; LCSC Part # C27834
SW1: RESET; SW_Push_Kinghelm_KH-6X6X5H-STM; LCSC Part # C2837531
U2: Platform_LoRa; platform-adapter-footprint; not fitted
U3: USBLC6-2SC6; SOT-23-6; LCSC Part # C7519
U4: RAK4630-8-SM-I; RAK4630; LCSC Part # C32315253
U5: RV-3028-C7; LCSC Part # C3304278

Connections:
+3V3: C3.1, C4.1, C6.1, C9.1, C10.1, C11.1, R1.1, R2.1, R3.2, U2.2 (3V3), U4.20 (VBAT_SX), U4.21 (VBAT_IO_SX), U4.43 (VDD_NRF), U4.44 (VBAT_NRF), U5.7 (VDD)
/D+: J3.A6 (D+), J3.B6 (D+), U3.1 (I/O1)
/D-: J3.A7 (D-), J3.B7 (D-), U3.3 (I/O2)
/USB+: U3.6 (I/O1), U4.3 (USB+)
/USB-: U3.4 (I/O2), U4.2 (USB-)
GND: C3.2, C4.2, C5.2, C6.2, C7.2, C8.2, C9.2, C10.2, C11.2, D1.1 (K), D2.1 (K), J3.A1 (GND), J3.A12 (GND), J3.B1 (GND), J3.B12 (GND), J3.S1 (SHIELD), R4.2, R5.2, SW1.1, U2.1 (GND), U2.6 (GND), U2.11 (GND), U2.16 (GND), U3.2 (GND), U4.14 (GND), U4.16 (GND), U4.22 (GND), U4.35 (GND), U4.36 (GND), U4.38 (GND), U4.42 (GND), U5.5 (VSS)
unnamed: D1.2 (A), R6.2
unnamed: D2.2 (A), R7.2
unnamed: J3.A5 (CC1), R4.1
unnamed: J3.B5 (CC2), R5.1
unnamed: C5.1, J3.A4 (VBUS), J3.A9 (VBUS), J3.B4 (VBUS), J3.B9 (VBUS), U3.5 (VBUS), U4.1 (VBUS)
unnamed: R6.1, U4.27 (P1.03/LED1)
unnamed: R7.1, U4.28 (P1.04/LED2)
unnamed: R3.1, U5.8 (EVI)
unnamed: C7.1, C8.1, U5.6 (VBACKUP)
SCL: R1.2, U2.7 (SCL), U4.5 (P0.14/I2C_SCL), U5.3 (SCL)
SDA: R2.2, U2.8 (SDA), U4.4 (P0.13/I2C_SDA), U5.4 (SDA)
SER1_RX: J4.1, U4.6 (P0.15/UART2_RX)
SER1_TX: J5.1, U4.7 (P0.16/UART2_TX)
SER2_RX: J4.3, U4.9 (P0.19/UART1_RX)
SER2_TX: J5.3, U4.10 (P0.20/UART1_TX)
SWDCLK: U2.14 (SWDCLK), U4.18 (SWDCLK)
SWDIO: U2.15 (SWDIO), U4.19 (SWDIO)
UART_RX: J4.2, U2.19 (UART_RX)
UART_TX: J5.2, U2.20 (UART_TX)
nRESET: SW1.2, U2.13 (nRESET), U4.17 (NRF_RESET)

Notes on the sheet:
Bulk reservoir for TX bursts 2x 100uF near 3V3 header entry
1 +3V3 2 SDA 3 SCL 4 SWDIO 5 SWDCLK 6 nRESET 7+8 GND
USB-C — FIELD ACCESS (UF2 / CONSOLE)
STATUS LEDS (RAK4631 BSP)
RTC — RV-3028-C7 (MeshCore auto-detects @ 0x52)
NOTES 1. RAK4630-8-SM-I (u.FL/MHF variant): RF pads 15 + 37 are internally disconnected — LoRa antenna via MHF pigtail to bulkhead; no RF routing on this board. 2. 3V3 rail arrives via harness from charger board; Walter power-kill cycles this rail. RTC rides through power-kills on C4 (supercap back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
All four supply pins tied to +3V3 (normal-voltage mode, 2.0–3.6 V). Never feed raw battery here — 3V3 comes from the charger-board LDO.

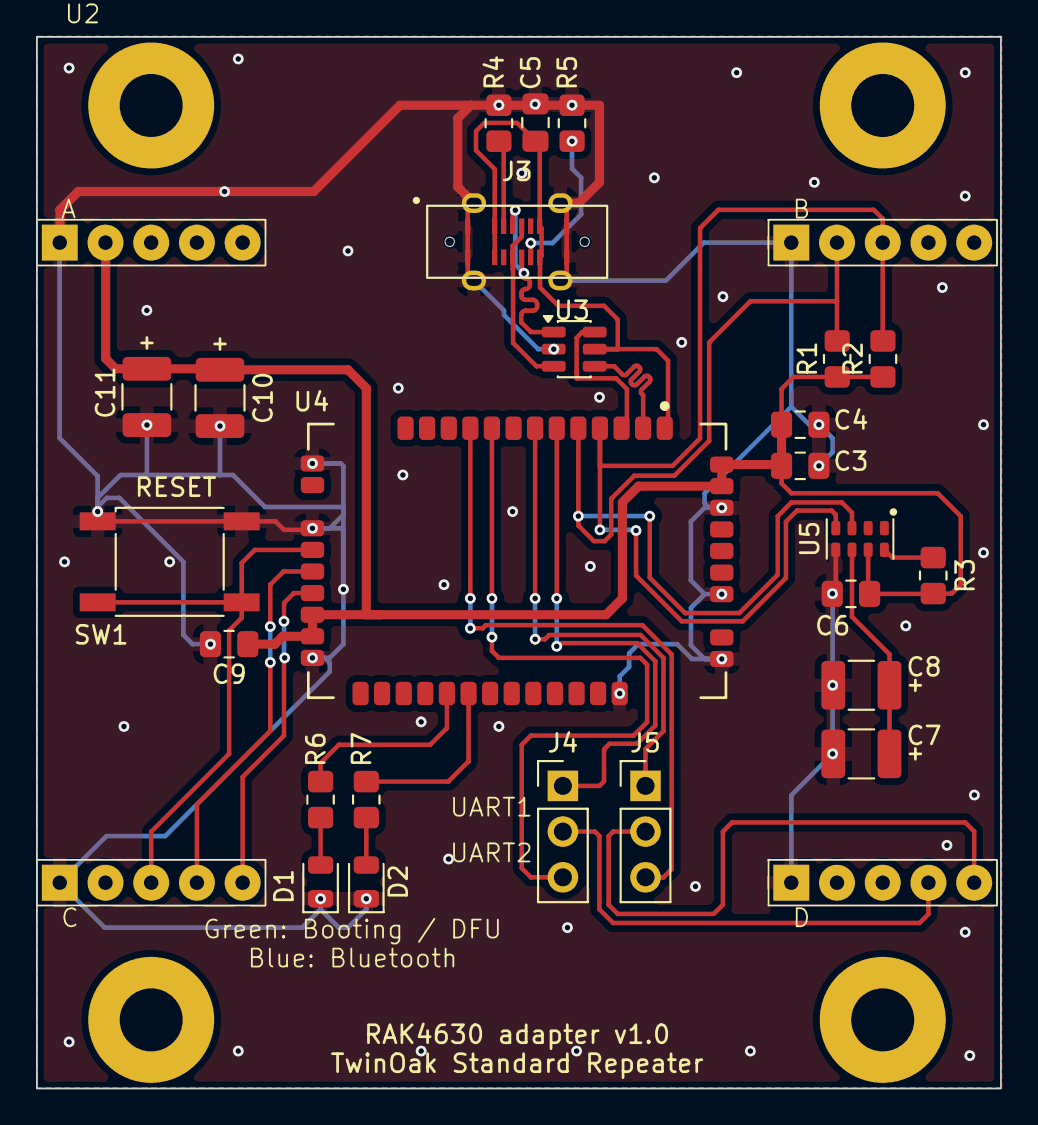
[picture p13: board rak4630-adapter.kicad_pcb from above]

Board: 2 copper layers, 53.6 x 58.4 mm, 26 parts (0 on the bottom side), 26 nets.

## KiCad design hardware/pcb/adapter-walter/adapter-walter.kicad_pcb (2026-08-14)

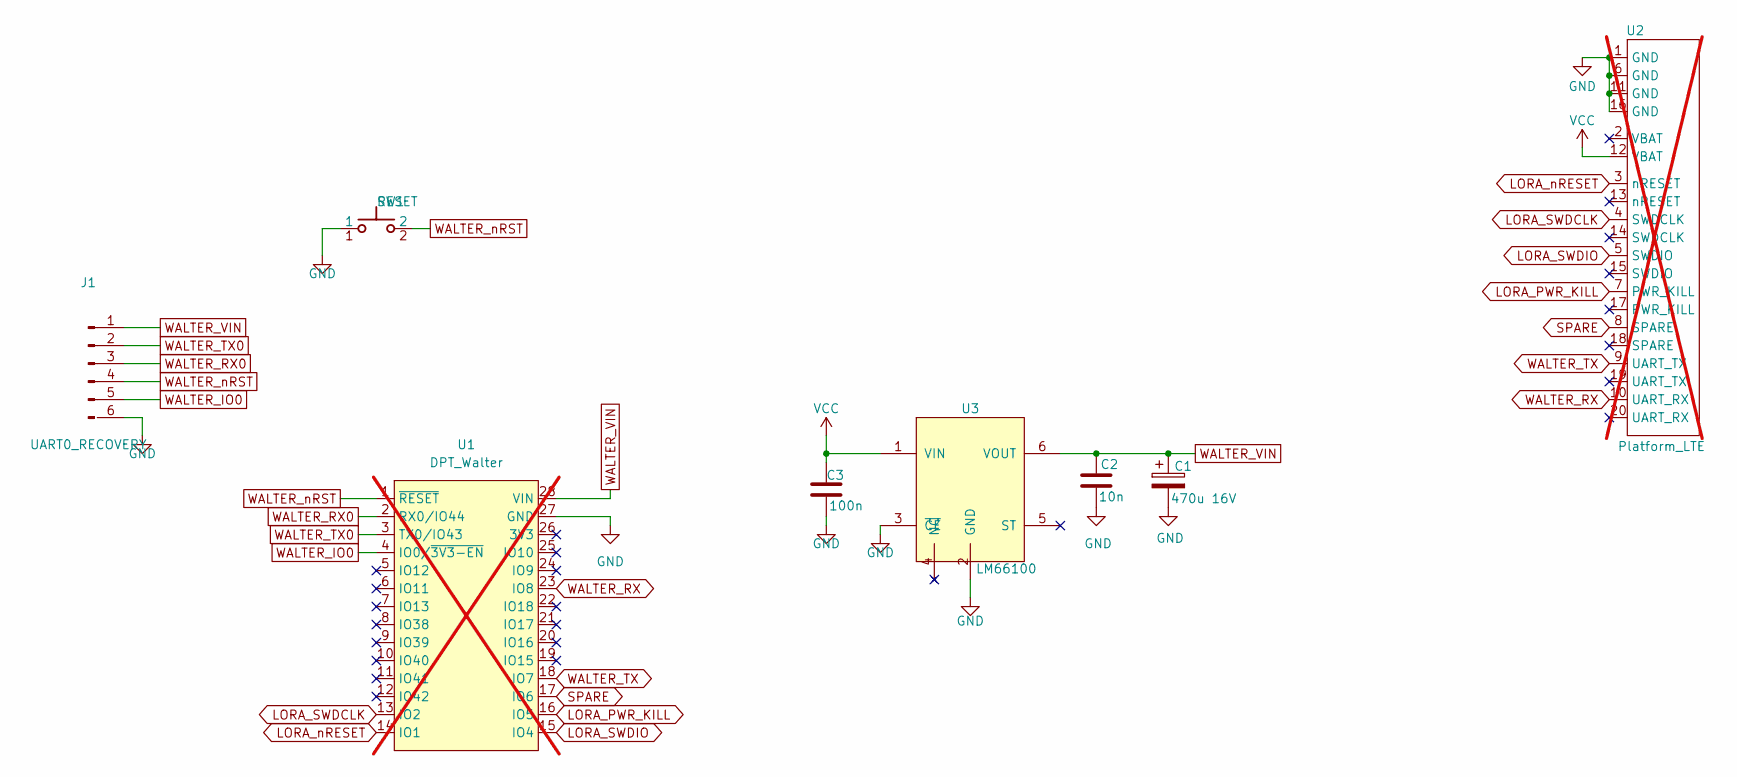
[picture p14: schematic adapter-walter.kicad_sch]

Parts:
C1: 470u 16V; CP_Radial_D8.0mm_P3.50mm; MPN Panasonic 16SEPG470M (OS-CON)
C2: 10n; C_Rect_L4.0mm_W2.5mm_P2.50mm; MPN SR Passives CCT-10N/100V-S
C3: 100n; C_0805_2012Metric_Pad1.18x1.45mm_HandSolder; LCSC Part # C49678
J1: UART0_RECOVERY; PinHeader_1x06_P2.54mm_Vertical
SW1: RESET; SW_Push_Kinghelm_KH-6X6X5H-STM; LCSC Part # C2837531
U1: DPT_Walter; walter-socket; not fitted
U2: Platform_LTE; platform-adapter-footprint; not fitted
U3: LM66100; SOT-363_SC-70-6; LCSC Part # C2832141

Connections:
GND: C1.2, C2.2, C3.2, J1.6, SW1.1, U1.27 (GND), U2.1 (GND), U2.6 (GND), U2.11 (GND), U2.16 (GND), U3.2 (GND), U3.3 (~CE)
LORA_PWR_KILL: U1.16 (IO5), U2.7 (PWR_KILL)
LORA_SWDCLK: U1.13 (IO2), U2.4 (SWDCLK)
LORA_SWDIO: U1.15 (IO4), U2.5 (SWDIO)
LORA_nRESET: U1.14 (IO1), U2.3 (nRESET)
SPARE: U1.17 (IO6), U2.8 (SPARE)
VCC: C3.1, U2.12 (VBAT), U3.1 (VIN)
WALTER_IO0: J1.5, U1.4 (IO0/~3V3-EN)
WALTER_RX: U1.23 (IO8), U2.10 (UART_RX)
WALTER_RX0: J1.3, U1.2 (RX0/IO44)
WALTER_TX: U1.18 (IO7), U2.9 (UART_TX)
WALTER_TX0: J1.2, U1.3 (TX0/IO43)
WALTER_VIN: C1.1, C2.1, J1.1, U1.28 (VIN), U3.6 (VOUT)
WALTER_nRST: J1.4, SW1.2, U1.1 (~RESET)

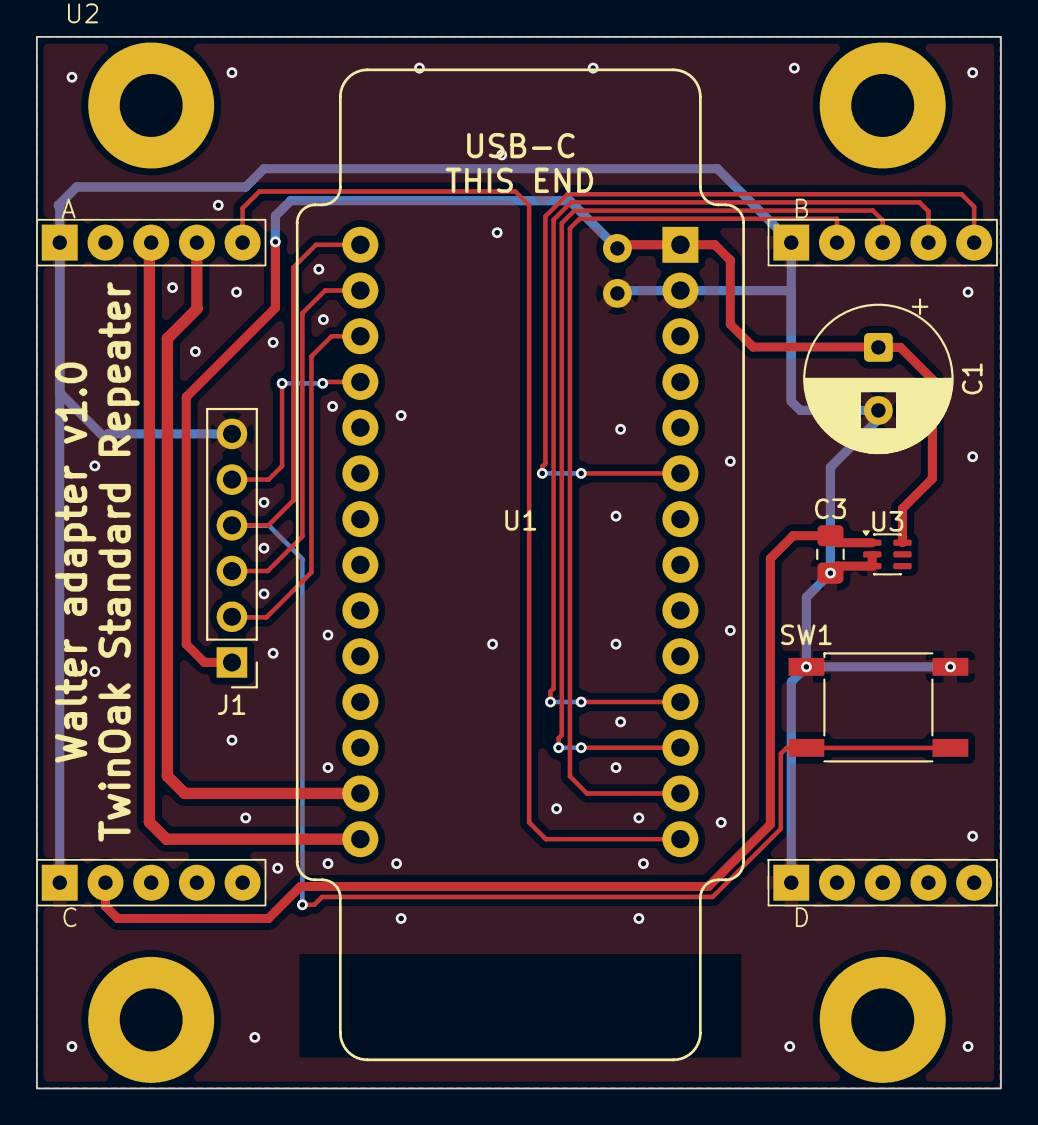
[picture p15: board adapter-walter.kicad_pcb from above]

Board: 2 copper layers, 53.6 x 58.4 mm, 8 parts (1 on the bottom side), 14 nets.

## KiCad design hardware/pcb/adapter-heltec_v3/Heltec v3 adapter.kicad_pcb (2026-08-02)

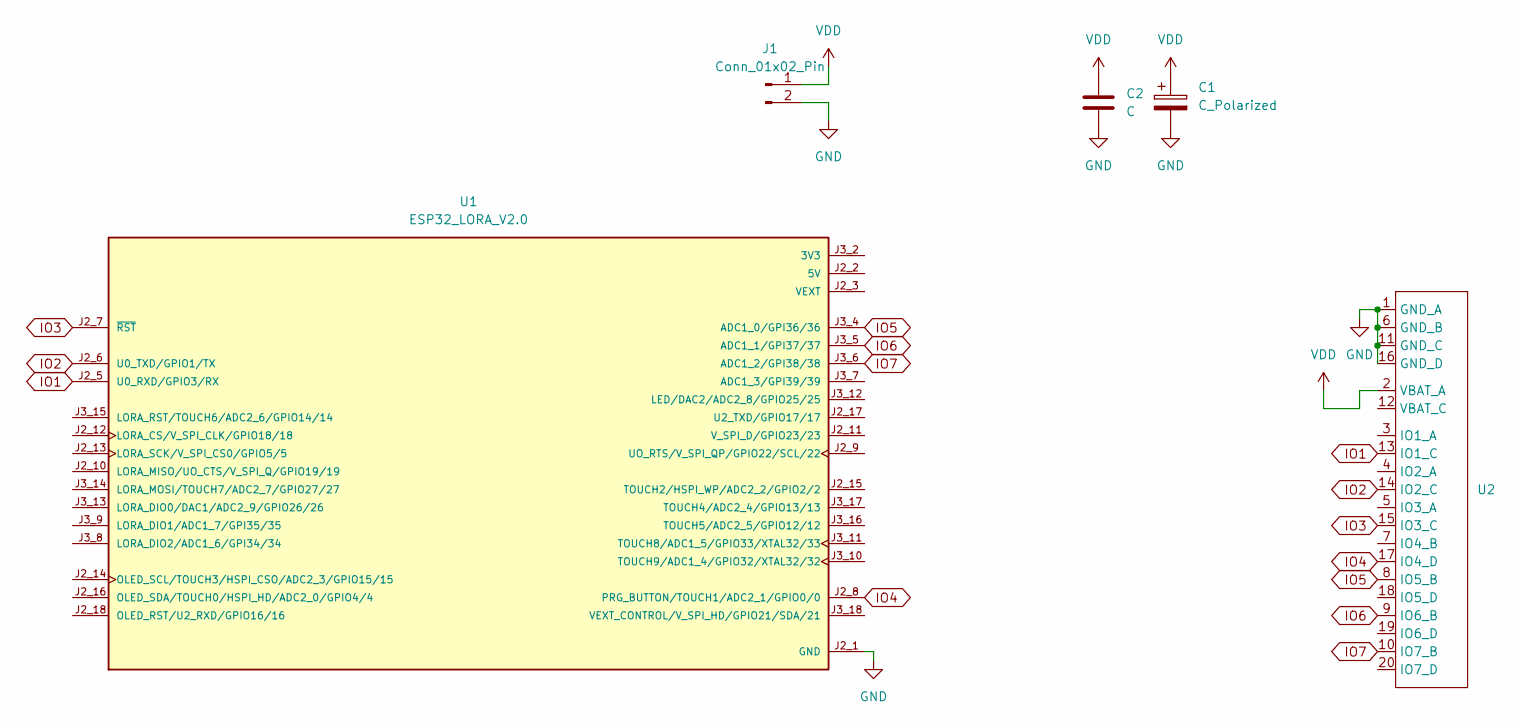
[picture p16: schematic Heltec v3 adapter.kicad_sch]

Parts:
C1: C_Polarized; CP_Radial_D8.0mm_P3.50mm
C2: C; C_Rect_L4.0mm_W2.5mm_P2.50mm
J1: Conn_01x02_Pin; PinHeader_1x02_P2.54mm_Vertical
U1: ESP32_LORA_V2.0; MODULE_ESP32_LORA_V2.0; PARTREV 2.0
U2: platform-adapter-footprint

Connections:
3V3: U1.J3_2 (3V3), U1.J3_3 (3V3)
GND: C1.2, C2.2, J1.2, U1.J2_1 (GND), U1.J3_1 (GND), U2.1 (GND_A), U2.6 (GND_B), U2.11 (GND_C), U2.16 (GND_D), U2.22, U2.23, U2.24, U2.25
IO1: U1.J2_5 (U0_RXD/GPIO3/RX), U2.13 (IO1_C)
IO2: U1.J2_6 (U0_TXD/GPIO1/TX), U2.14 (IO2_C)
IO3: U1.J2_7 (~RST), U2.15 (IO3_C)
IO4: U1.J2_8 (PRG_BUTTON/TOUCH1/ADC2_1/GPIO0/0), U2.17 (IO4_D)
IO5: U1.J3_4 (ADC1_0/GPI36/36), U2.8 (IO5_B)
IO6: U1.J3_5 (ADC1_1/GPI37/37), U2.9 (IO6_B)
IO7: U1.J3_6 (ADC1_2/GPI38/38), U2.10 (IO7_B)
VDD: C1.1, C2.1, J1.1, U2.2 (VBAT_A)
VEXT: U1.J2_3 (VEXT), U1.J2_4 (VEXT)

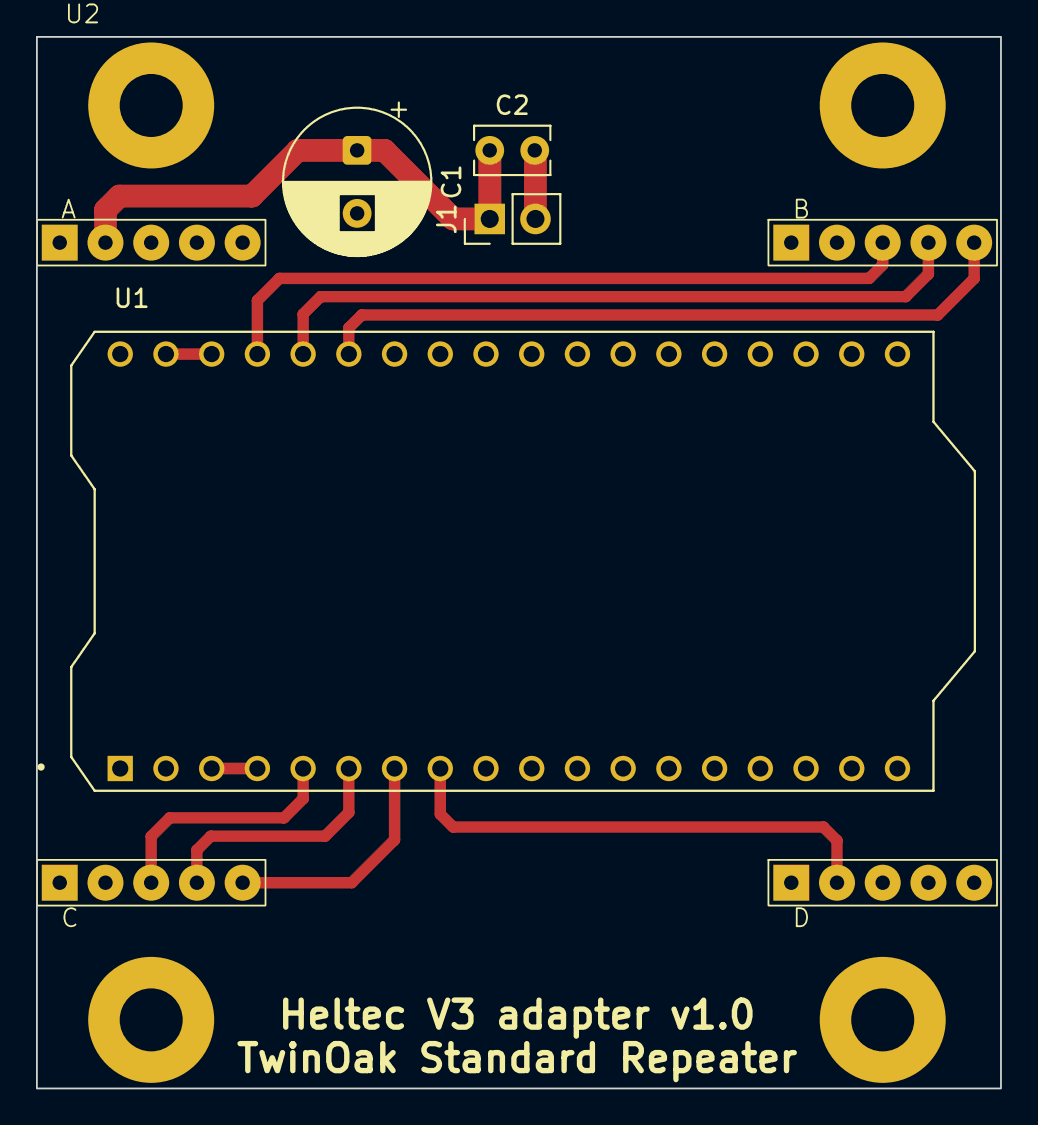
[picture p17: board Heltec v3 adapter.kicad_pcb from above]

Board: 2 copper layers, 53.6 x 58.4 mm, 5 parts (0 on the bottom side), 11 nets.

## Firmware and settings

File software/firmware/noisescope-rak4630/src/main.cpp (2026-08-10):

// ---------------------------------------------------------------------------
// NoiseScope — SX1262 spectrum/noise scanner for the TwinOak RAK4630 adapter
//
// Diagnostic firmware, temporarily flashed in place of MeshCore when a site
// needs RF debugging. Streams NDJSON over the Walter management UART (and USB
// CDC when attached). Never transmits — RX only.
//
// See PROTOCOL.md for the line format and command set.
// ---------------------------------------------------------------------------

#include <Arduino.h>
#include "config.h"
#include "out.h"
#include "wdt.h"
#include "telemetry.h"
#include "scanner.h"

static uint32_t s_stat_next_ms = 0;
static uint32_t s_auto_min = AUTO_SWEEP_MIN_DEFAULT;
static uint32_t s_auto_last_ms = 0;
static char s_reset_reason[8] = "por";

// ---- serial line input (two independent sources) ----

struct LineBuf {
  char buf[160];
  uint8_t len = 0;
  bool ready = false;
};
static LineBuf lb_walter, lb_usb;

static void feed_linebuf(LineBuf& lb, Stream& s) {
  if (lb.ready) return;                    // hold further bytes in HW/driver buffer
  while (s.available()) {
    char c = (char)s.read();
    if (c == '\n' || c == '\r') {
      if (lb.len > 0) { lb.buf[lb.len] = 0; lb.ready = true; return; }
    } else if (lb.len < sizeof(lb.buf) - 1) {
      lb.buf[lb.len++] = c;
    }
  }
}

// Called from scanner.cpp during blocking scan windows too.
void input_poll() {
  feed_linebuf(lb_walter, WALTER_SERIAL);
  feed_linebuf(lb_usb, Serial);
}

// ---- helpers ----

static void emit_ack(const char* cmd, bool ok, const char* msg) {
  out_printf("{\"t\":\"ack\",\"cmd\":\"%s\",\"ok\":%s", cmd, ok ? "true" : "false");
  if (msg && msg[0]) out_printf(",\"msg\":\"%s\"", msg);
  out_raw("}");
  out_end();
}

static void emit_stat() {
  float f, bw; uint8_t sf, cr;
  scan_get_home(&f, &bw, &sf, &cr);
  out_printf("{\"t\":\"stat\",\"ts\":%lu,\"ms\":%lu,\"up\":%lu,\"mode\":\"%s\",\"home\":%.3f",
             (unsigned long)time_epoch(), (unsigned long)millis(),
             (unsigned long)(millis() / 1000UL), scan_mode_name(), f);
  MonStats ms;
  if (scan_mode() == MODE_MONITOR && scan_get_monitor_stats(&ms, true)) {
    out_printf(",\"rssi\":{\"n\":%lu,\"avg\":%.1f,\"max\":%.1f,\"min\":%.1f,\"dc\":%.4f,\"th\":%.1f}",
               (unsigned long)ms.n, ms.avg, ms.mx, ms.mn, ms.dc, ms.th);
  }
  if (ina_ok()) {
    float v1, i1, v2, i2, v3, i3;
    bool a = ina_read(1, &v1, &i1), b = ina_read(2, &v2, &i2), c = ina_read(3, &v3, &i3);
    if (a && b && c) {
      out_printf(",\"pwr\":{\"vpanel\":%.2f,\"ipanel\":%.0f,\"vbat\":%.3f,\"ibat\":%.0f,\"vload\":%.3f,\"iload\":%.0f}",
                 v1, i1, v2, i2, v3, i3);
    }
  }
  out_raw("}");
  out_end();
}

static void emit_info() {
  float f, bw; uint8_t sf, cr;
  scan_get_home(&f, &bw, &sf, &cr);
  out_printf("{\"t\":\"info\",\"fw\":\"%s\",\"ver\":\"%s\",\"hw\":\"rak4630\",\"radio\":\"sx1262\","
             "\"build\":\"%s\",\"devid\":\"%08lx%08lx\",\"reset\":\"%s\",\"rtc\":%d,\"ina\":%d,"
             "\"radio_ok\":%d,\"boost\":%d,\"auto_min\":%lu",
             FW_NAME, FW_VERSION, __DATE__,
             (unsigned long)NRF_FICR->DEVICEID[1], (unsigned long)NRF_FICR->DEVICEID[0],
             s_reset_reason, rtc_ok() ? 1 : 0, ina_ok() ? 1 : 0,
             scan_radio_ok() ? 1 : 0, scan_get_boost() ? 1 : 0, (unsigned long)s_auto_min);
  out_printf(",\"home\":{\"f\":%.3f,\"bw\":%.1f,\"sf\":%u,\"cr\":%u}}", f, bw, sf, cr);
  out_end();
}

static void emit_help() {
  out_raw("# NoiseScope " FW_VERSION " — commands (NDJSON out, '#' lines are chatter)\n"
          "#   sweep [f0 f1 [step_khz [dwell_ms [passes]]]]   RSSI sweep; passes 0 = until stop\n"
          "#   hist  [f0 f1 [step_khz [samples [passes]]]]    spectral-scan histograms (33 x 4dB bins)\n"
          "#   dwell <f_mhz> [secs [win_ms]]                  time-domain stats on one frequency\n"
          "#   cad   [f_mhz [count]]                          LoRa preamble detection ratio\n"
          "#   stop | stat | info | help\n"
          "#   home <f_mhz> [bw_khz sf cr]                    set monitor channel\n"
          "#   boost on|off                                   RX boosted gain\n"
          "#   auto <minutes>                                 periodic background sweep (0 = off)\n"
          "#   time <epoch>                                   set clock (writes RTC when present)\n"
          "#   reboot | dfu [serial]                          restart / enter bootloader\n");
}

// ---- command dispatch ----

static void handle_command(char* line) {
  // tokenize (max 8 tokens)
  char* tok[8] = {0};
  int nt = 0;
  char* save = nullptr;
  for (char* t = strtok_r(line, " \t", &save); t && nt < 8; t = strtok_r(nullptr, " \t", &save)) {
    tok[nt++] = t;
  }
  if (nt == 0) return;
  for (char* p = tok[0]; *p; p++) *p = tolower(*p);
  const char* c = tok[0];

  if (!strcmp(c, "help")) { emit_help(); return; }
  if (!strcmp(c, "info")) { emit_info(); return; }
  if (!strcmp(c, "stat")) { emit_stat(); return; }

  if (!strcmp(c, "stop")) {
    scan_stop();
    emit_ack("stop", true, "monitor");
    return;
  }

  if (!strcmp(c, "sweep") || !strcmp(c, "hist")) {
    bool is_hist = !strcmp(c, "hist");
    float f0 = SWEEP_F0_MHZ, f1 = SWEEP_F1_MHZ, step = SWEEP_STEP_KHZ;
    long p4 = is_hist ? 2048 : SWEEP_DWELL_MS;   // samples / dwell_ms
    long passes = 1;
    if (nt >= 3) { f0 = atof(tok[1]); f1 = atof(tok[2]); }
    if (nt >= 4) step = atof(tok[3]);
    if (nt >= 5) p4 = atol(tok[4]);
    if (nt >= 6) passes = atol(tok[5]);
    scan_stop();
    bool ok = is_hist
      ? scan_start_hist(f0, f1, step, (uint16_t)p4, (int)passes)
      : scan_start_sweep(f0, f1, step, (uint16_t)p4, (int)passes);
    emit_ack(c, ok, ok ? "started" : "bad params or radio error");
    return;
  }

  if (!strcmp(c, "dwell")) {
    if (nt < 2) { emit_ack(c, false, "usage: dwell <f_mhz> [secs [win_ms]]"); return; }
    float f = atof(tok[1]);
    uint32_t secs = (nt >= 3) ? (uint32_t)atol(tok[2]) : 60;
    uint32_t win = (nt >= 4) ? (uint32_t)atol(tok[3]) : 1000;
    scan_stop();
    bool ok = scan_start_dwell(f, secs, win);
    emit_ack(c, ok, ok ? "started" : "bad params");
    return;
  }

  if (!strcmp(c, "cad")) {
    float fh, bw; uint8_t sf, cr;
    scan_get_home(&fh, &bw, &sf, &cr);
    float f = (nt >= 2) ? atof(tok[1]) : fh;
    uint16_t count = (nt >= 3) ? (uint16_t)atol(tok[2]) : 100;
    scan_stop();
    bool ok = scan_start_cad(f, count);
    emit_ack(c, ok, ok ? "started" : "bad params");
    return;
  }

  if (!strcmp(c, "home")) {
    if (nt < 2) { emit_ack(c, false, "usage: home <f_mhz> [bw_khz sf cr]"); return; }
    float fh, bw; uint8_t sf, cr;
    scan_get_home(&fh, &bw, &sf, &cr);
    float f = atof(tok[1]);
    if (nt >= 5) { bw = atof(tok[2]); sf = (uint8_t)atol(tok[3]); cr = (uint8_t)atol(tok[4]); }
    bool ok = scan_set_home(f, bw, sf, cr);
    emit_ack(c, ok, ok ? "retuned" : "bad params");
    return;
  }

  if (!strcmp(c, "boost")) {
    if (nt < 2) { emit_ack(c, false, "usage: boost on|off"); return; }
    bool on = !strcmp(tok[1], "on") || !strcmp(tok[1], "1");
    bool ok = scan_set_boost(on);
    emit_ack(c, ok, on ? "boosted gain on" : "boosted gain off");
    return;
  }

  if (!strcmp(c, "auto")) {
    if (nt < 2) { emit_ack(c, false, "usage: auto <minutes>"); return; }
    s_auto_min = (uint32_t)atol(tok[1]);
    s_auto_last_ms = millis();
    emit_ack(c, true, s_auto_min ? "auto-sweep on" : "auto-sweep off");
    return;
  }

  if (!strcmp(c, "time")) {
    if (nt < 2) { emit_ack(c, false, "usage: time <unix_epoch>"); return; }
    uint32_t t = (uint32_t)strtoul(tok[1], nullptr, 10);
    bool ok = (t > 1700000000UL) && time_set(t);
    emit_ack(c, ok, ok ? "clock set" : "bad epoch or rtc write failed");
    return;
  }

  if (!strcmp(c, "reboot")) {
    emit_ack(c, true, "rebooting");
    delay(50);
    NVIC_SystemReset();
  }

  if (!strcmp(c, "dfu")) {
    bool serial_only = (nt >= 2) && !strcmp(tok[1], "serial");
    emit_ack(c, true, serial_only ? "entering serial DFU" : "entering UF2 bootloader");
    delay(50);
    NRF_POWER->GPREGRET = serial_only ? 0x4e : 0x57;  // DFU_MAGIC_SERIAL_ONLY / DFU_MAGIC_UF2
    NVIC_SystemReset();
  }

  emit_ack(c, false, "unknown command, try: help");
}

static void check_commands() {
  if (lb_walter.ready) {
    handle_command(lb_walter.buf);
    lb_walter.len = 0; lb_walter.ready = false;
  }
  if (lb_usb.ready) {
    handle_command(lb_usb.buf);
    lb_usb.len = 0; lb_usb.ready = false;
  }
}

// ---- boot / main loop ----

static void capture_reset_reason() {
  uint32_t r = NRF_POWER->RESETREAS;
  NRF_POWER->RESETREAS = r;   // clear (write 1 to clear)
  if (r & POWER_RESETREAS_DOG_Msk)           strcpy(s_reset_reason, "wdt");
  else if (r & POWER_RESETREAS_SREQ_Msk)     strcpy(s_reset_reason, "soft");
  else if (r & POWER_RESETREAS_LOCKUP_Msk)   strcpy(s_reset_reason, "lockup");
  else if (r & POWER_RESETREAS_RESETPIN_Msk) strcpy(s_reset_reason, "pin");
  else                                       strcpy(s_reset_reason, "por");
}

void setup() {
  capture_reset_reason();
  out_init();
  wdt_init();
  delay(100);            // let the 3V3 rail and TCXO settle after a power-kill cycle
  tele_init();
  bool radio_ok = scan_init();

  out_printf("{\"t\":\"boot\",\"fw\":\"%s\",\"ver\":\"%s\",\"hw\":\"rak4630\",\"radio\":\"sx1262\","
             "\"reset\":\"%s\",\"radio_ok\":%s,\"rtc\":%d,\"ina\":%d,\"ts\":%lu}",
             FW_NAME, FW_VERSION, s_reset_reason, radio_ok ? "true" : "false",
             rtc_ok() ? 1 : 0, ina_ok() ? 1 : 0, (unsigned long)time_epoch());
  out_end();

  s_stat_next_ms = millis() + STAT_INTERVAL_MS;
  s_auto_last_ms = millis();
}

void loop() {
  wdt_feed();
  out_service();
  input_poll();
  check_commands();
  scan_service();

  uint32_t now = millis();
  if ((int32_t)(now - s_stat_next_ms) >= 0) {
    emit_stat();
    s_stat_next_ms += STAT_INTERVAL_MS;
  }

  if (s_auto_min > 0 && scan_mode() == MODE_MONITOR &&
      now - s_auto_last_ms >= s_auto_min * 60000UL) {
    s_auto_last_ms = now;
    if (scan_start_sweep(SWEEP_F0_MHZ, SWEEP_F1_MHZ, SWEEP_STEP_KHZ, SWEEP_DWELL_MS, 1)) {
      out_line("{\"t\":\"ack\",\"cmd\":\"auto-sweep\",\"ok\":true}");
    }
  }
}

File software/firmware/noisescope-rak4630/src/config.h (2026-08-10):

#pragma once
// ---------------------------------------------------------------------------
// NoiseScope build-time configuration.
// Every value can be overridden with -D <NAME>=<value> in platformio.ini.
// ---------------------------------------------------------------------------

#ifndef FW_NAME
  #define FW_NAME "noisescope"
#endif
#ifndef FW_VERSION
  #define FW_VERSION "0.1.0"
#endif

// ---- SX1262 wiring (RAK4630/RAK4631, identical to MeshCore's rak4631 variant) ----
#ifndef P_LORA_NSS
  #define P_LORA_NSS    42    // P1.10
#endif
#ifndef P_LORA_DIO_1
  #define P_LORA_DIO_1  47    // P1.15
#endif
#ifndef P_LORA_RESET
  #define P_LORA_RESET  38    // P1.06
#endif
#ifndef P_LORA_BUSY
  #define P_LORA_BUSY   46    // P1.14
#endif
#ifndef P_LORA_SCLK
  #define P_LORA_SCLK   43    // P1.11
#endif
#ifndef P_LORA_MISO
  #define P_LORA_MISO   45    // P1.13
#endif
#ifndef P_LORA_MOSI
  #define P_LORA_MOSI   44    // P1.12
#endif

#define SX126X_DIO2_AS_RF_SWITCH  true
#define SX126X_DIO3_TCXO_VOLTAGE  1.8f
#ifndef SX126X_CURRENT_LIMIT
  #define SX126X_CURRENT_LIMIT    140.0f
#endif
#ifndef RX_BOOSTED_GAIN_DEFAULT
  #define RX_BOOSTED_GAIN_DEFAULT 1     // match MeshCore rak4631 build (SX126X_RX_BOOSTED_GAIN=1)
#endif

// ---- Home channel (what MeshCore normally listens on; monitor mode uses this) ----
#ifndef HOME_FREQ_MHZ
  #define HOME_FREQ_MHZ 869.618f        // MeshCore DK standard, EU Narrow
#endif
#ifndef HOME_BW_KHZ
  #define HOME_BW_KHZ   62.5f
#endif
#ifndef HOME_SF
  #define HOME_SF       8
#endif
#ifndef HOME_CR
  #define HOME_CR       8
#endif

// ---- Walter management UART ----
// TwinOak RAK4630 adapter: J4/J5 jumpers 1-2 -> Serial1 (P0.15 RX / P0.16 TX, default),
// jumpers 2-3 -> Serial2 (P0.19 / P0.20). Override WALTER_SERIAL to Serial2 if strapped so.
#ifndef WALTER_SERIAL
  #define WALTER_SERIAL Serial1
#endif
#ifndef WALTER_BAUD
  #define WALTER_BAUD   115200          // per INTERCONNECT.md (2x 1000 pF bulkhead filters are fine at this rate)
#endif

// ---- Default sweep (also used by the periodic auto-sweep) ----
#ifndef SWEEP_F0_MHZ
  #define SWEEP_F0_MHZ  863.0f          // full EU868 SRD band
#endif
#ifndef SWEEP_F1_MHZ
  #define SWEEP_F1_MHZ  870.0f
#endif
#ifndef SWEEP_STEP_KHZ
  #define SWEEP_STEP_KHZ 25.0f
#endif
#ifndef SWEEP_DWELL_MS
  #define SWEEP_DWELL_MS 20
#endif
#ifndef AUTO_SWEEP_MIN_DEFAULT
  #define AUTO_SWEEP_MIN_DEFAULT 10     // minutes between unattended sweeps; 0 = off
#endif

// ---- Reporting cadence / limits ----
#ifndef STAT_INTERVAL_MS
  #define STAT_INTERVAL_MS 10000        // heartbeat "stat" line
#endif
#ifndef MON_SAMPLE_US
  #define MON_SAMPLE_US    1000         // monitor/dwell RSSI sampling pace (~1 kHz)
#endif
#ifndef BURST_TH_DELTA_DB
  #define BURST_TH_DELTA_DB 10.0f       // duty-cycle threshold = window min + this
#endif
#define MAX_SWEEP_POINTS  512
#define HIST_BINS         33            // fixed by the SX126x spectral-scan engine

// ---- I2C peripherals on the TwinOak boards ----
#define RTC_ADDR   0x52                 // RV-3028-C7 on the RAK adapter
#define INA_ADDR   0x42                 // INA3221 on connector board B (A0 tied to SDA)
#ifndef INA_SHUNT_MILLIOHM
  #define INA_SHUNT_MILLIOHM 20         // RS2/RS3/RS4 20 mOhm per BOM
#endif
#ifndef I2C_CLOCK_HZ
  #define I2C_CLOCK_HZ 100000           // 1k pullups through bulkhead filter: keep at/below 100 kHz
#endif

// ---- Watchdog ----
#ifndef WDT_TIMEOUT_S
  #define WDT_TIMEOUT_S 8
#endif

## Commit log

2026-07-19 Added platform board
    [platform-board.kicad_pcb, platform-board.kicad_sch]
2026-07-19 Added initial Heltec V3 adapter
    [Heltec v3 adapter.kicad_pcb, Heltec v3 adapter.kicad_sch, platform-board.kicad_pcb]
2026-08-02 Initial boards for raw prototyping
    [Heltec T096 adapter.kicad_pcb, Heltec T096 adapter.kicad_sch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]
2026-08-08 Initial version of RAK4630 adapter
    [rak4630-adapter.kicad_pcb, rak4630-adapter.kicad_sch]
2026-08-09 Updated RAK4630 board
    [rak4630-adapter.kicad_pcb, rak4630-adapter.kicad_sch]
2026-08-09 Updated connector A board to rev 1.1
    [connector-board-a.kicad_pcb, connector-board-a.kicad_sch]
2026-08-09 Updated Connectorboard A
    [connector-board-a.kicad_pcb]
2026-08-09 Updated documentation to match wiring
2026-08-09 Added missing description
    [connector-board-a.kicad_sch]
2026-08-09 Updated Connectorboard B to rev. 1.1
    [connector-board-b.kicad_pcb, connector-board-b.kicad_sch]
2026-08-09 Updated RAK4630 adapter
    [rak4630-adapter.kicad_pcb, rak4630-adapter.kicad_sch]
2026-08-09 Updated Walter adapter schematics
    [adapter-walter.kicad_sch]
2026-08-09 Update Heltec v3 adapter.kicad_sch
    [Heltec v3 adapter.kicad_sch]
2026-08-09 Adjusted track widths on all boards
    [rak4630-adapter.kicad_pcb, rak4630-adapter.kicad_sch]
2026-08-09 Cleanup of schematics and pcb traces on RAK4630 adapter
    [rak4630-adapter.kicad_pcb, rak4630-adapter.kicad_sch]
2026-08-10 Added initial noisescope stub
    [config.h, main.cpp, out.cpp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]
2026-08-10 Routing of connector b board
    [connector-board-a.kicad_pcb, connector-board-a.kicad_sch, connector-board-b.kicad_pcb]
2026-08-11 Cleanup. Added feedback prevention circuits to Walter adapter
    [adapter-walter.kicad_pcb, adapter-walter.kicad_sch, connector-board-a.kicad_pcb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]
2026-08-11 Initial routing of walter - Not finished, missing polish
    [adapter-walter.kicad_pcb, adapter-walter.kicad_sch]
2026-08-12 Minor connector b updates
    [connector-board-b.kicad_pcb, connector-board-b.kicad_sch]
2026-08-12 Misc changes
    [connector-board-a.kicad_pcb, connector-board-a.kicad_sch, connector-board-b.kicad_pcb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]
2026-08-13 Updates according to preflight
    [connector-board-b.kicad_pcb, connector-board-b.kicad_sch, rak4630-adapter.kicad_pcb]
2026-08-13 Minor adjustments to PCBs
    [adapter-walter.kicad_pcb, connector-board-b.kicad_pcb]
2026-08-13 Misc minor updates for production of pcbs
    [adapter-walter.kicad_pcb, adapter-walter.kicad_sch, connector-board-a.kicad_pcb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]
2026-08-13 Fixed bogus footprints
    [rak4630-adapter.kicad_pcb]
2026-08-13 Fixed bogus rotation of component on PCB
    [connector-board-b.kicad_pcb]
2026-08-14 Platform rewire
    [adapter-walter.kicad_pcb, platform-board.kicad_pcb, platform-board.kicad_sch]
2026-08-14 Final PCB adjuments to rev 1.1
    [adapter-walter.kicad_pcb, adapter-walter.kicad_sch, connector-board-a.kicad_pcb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]
2026-08-19 Added bracket designs
    [Enclosure bracket.dxf, Enclosure bracket.step, Solarpanel holder - Part A_V2.dxf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]
2026-08-20 Added I2C environment sensor
    [connector-board-a.kicad_sch]
2026-08-20 Routed new BME280 addition to connector A
    [connector-board-a.kicad_pcb]
2026-10-10 Moved connector b board to parent folder
2026-10-10 Changed via placements to avoid solderwicking
2026-10-19 Initial power-on plan
